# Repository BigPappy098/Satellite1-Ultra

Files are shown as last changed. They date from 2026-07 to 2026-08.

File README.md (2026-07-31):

# Satellite1 Ultra

**A real speaker for your FutureProofHomes Satellite1.**

Your Satellite1 keeps its microphones, its buttons and its lights. Everything
below them gets replaced by a sealed, weighted cabinet with a 3.5&nbsp;inch
driver and a passive radiator on each side.

The body is built from the official squircle's own curve — a superellipse, not a
rounded rectangle — so the Satellite1 top sits **flush** in a single flat surface
instead of perched on a shoulder. Assembled, it reads as one object. Nothing is
glued; it all comes back apart with a hex key.

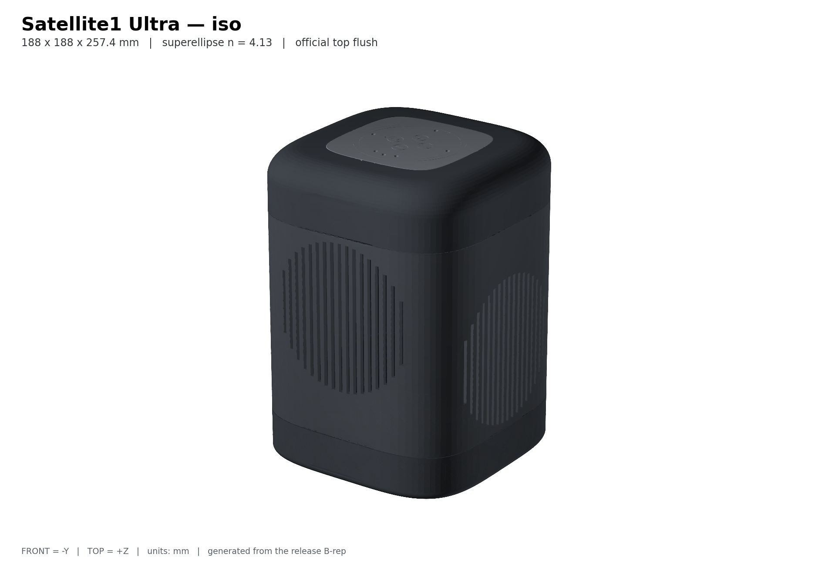
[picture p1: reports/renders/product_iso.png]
The finished Satellite1 Ultra


## Start here

**[Open the build guide →](https://bigpappy098.github.io/Satellite1-Ultra/)**

Four steps, a picture for every one. You never install anything — you only
download part files.

> The link goes live once this repository is public and GitHub Pages is enabled.
> Until then, run `make site` and open `site/index.html`.

| | |
|---|---|
| **1. Print eight test pieces** | Small and quick. They tell us how your printer actually lays down plastic. |
| **2. Measure them** | The site shows you where to put the calipers and which box to type each number into. |
| **3. Get your parts** | Printer dead on? Download the standard files. A little off? We generate a set corrected for *your* machine. |
| **4. Build it** | Nine steps, one picture each. Wrap it in speaker cloth at the end if you want to. |

> [!IMPORTANT]
> **Do not print the big parts first.** Skipping the test pieces is how people
> lose four days of ASA to a cabinet that will not seal. The test pieces take an
> evening.

## What you'll need

- A **Satellite1 Batch 1** kit — Core rev4.1 with HAT rev4.1. Batch 2 /
  Satellite1.1 does not fit, and there is no workaround in this design.
- A printer with **188 × 188 mm** of usable bed and about **170 mm** of height.
  The outer skin is three stacked segments rather than one tall shell, so a
  failed print costs you one segment instead of the whole body.
- **ASA** for the rigid parts (PETG works too) and a little **TPU 95A** for the
  flexible ones. You want an enclosed printer and dry filament — ASA warps
  otherwise, and a warped cabinet will not seal.
- One **Dayton ND91-4** driver and two **Dayton DSA115-PR** passive radiators,
  both from Parts Express. M3 screws and heat-set inserts, a sheet of 2 mm
  closed-cell foam, and two 6 mm steel plates.
- **M3 × ⌀4 shoulder screws with a 16 mm shoulder, ×4.** See the warning below.

It's a chunky build — about 4 out of 5 for difficulty — but there's no glue and
no soldering beyond two speaker wires.

> [!WARNING]
> **The four screws holding the Satellite1 top must be shoulder screws.** The
> shoulder bottoms out and lets the top float on rubber bushings, which stops the
> woofer shaking your microphones. With ordinary M3 screws the rubber carries
> under 3% of the load path and does nothing at all. If the top feels rock solid,
> you have the wrong screws.

## What it measures

| | |
|---|---|
| Footprint | 188 × 188 mm |
| Height | 257.4 mm |
| Sealed volume | 3.97 L |
| Printed parts | 22, plus 6 official Satellite1 top parts |
| Longest print | about 170 mm |
| Assembled mass | roughly 3.5 kg, most of it steel in the base |

## Honest status

**Nobody has built one yet.**

The geometry, clearances, seals, volumes and files all pass a strict set of
automated checks, and every part has been measured against every other part. But
no one has printed a whole one, sealed it, and put a microphone in front of it.
So fit, sealing, sound, heat, Wi-Fi and wake-word behaviour are all still
unproven.

That means **your** checks along the way aren't extra credit — they're the first
real evidence this design works. If something doesn't fit, that's genuinely
useful. Please open an issue.

---

## For developers

Everything below is for people who want to change the design. Builders don't need
any of it.

The design is parametric CadQuery source. Every part, drawing, illustration and
document in the release is generated from it — there is no hand-edited mesh and
no concept art anywhere in the deliverables. Prose is written by hand, but every
dimension inside it is interpolated from the geometry, so a guide cannot claim a
part is a size it isn't.

```text
make all
```

Python 3.12. That creates the environment from hash-locked dependencies, then
regenerates and revalidates every B-rep, export, render, guide, PDF, the
website, and the release package. It fails if anything is missing or stale.

| Command | What it does |
|---|---|
| `make check` | Lint, typecheck, build, validate, fast tests |
| `make release` | Full clean regeneration and every gate |
| `make site` | Build the illustrated website into `site/` |
| `make clean` | Remove every generated artifact |

One extra check worth knowing about, written after the gates missed a real
defect:

```text
.venv/bin/python scripts/audit_connections.py   # every bolted joint, from the solids
```

`audit_connections.py` exists because a fastener can pass a position check and
still have no material to bite into. It probes all 28 joints for a solid wall
around each insert bore and an unobstructed screw path through the mating part.

### Where things live

- Parametric source — `src/satellite1_ultra/`
- Design parameters — `config/default.yaml`, `config/components.yaml`
- Printer bed and corrections — `config/default.yaml` (`printing.build_volume_*`),
  `config/physical_calibration.yaml`
- Official assets, unmodified — `reference-assets/official/`
- Provenance and checksums — `reference-assets/MANIFEST.csv`
- Evidence — `reports/validation/`, `reports/acoustics/`
- Review findings — `reports/review/`
- Why v2 looks the way it does — `reports/V2_DESIGN_RATIONALE.md`

Generated artifacts record the commit they came from, so the build refuses to
ship a package whose CAD no longer matches its source.

### The section family

Every visible section of the enclosure is the superellipse
`|x/a|ⁿ + |y/b|ⁿ = 1` with **n = 4.13**, measured off the official lock ring to
a maximum fit error of 0.38 mm. A best-fit rounded rectangle misses the same
profile by 1.00 mm, which is why v1's body and the official top never read as one
form. See `geometry.SECTION_EXPONENT`.

The hidden structure — cabinet, divider, base — is deliberately *not* a
superellipse. Flat circular hardware needs a flat face: on a curved wall a
component seat sidewall isn't solid, a gasket land stops being a closed rim, and
a 140 mm clamp ring hangs off the corners.

### Coordinate system

- origin: center of the official mid-plate interface plane, as measured from the
  preserved B-rep.
- +Z: toward the microphones.
- -Y: active-driver front.
- +/-X: opposed passive radiators.
- Units: millimetres everywhere.

STEP is the authoritative exchange format; STL and 3MF are derived meshes. Source
geometry never uses mesh booleans, voxels, SDFs, or marching cubes.

## License

Hardware geometry is **CERN-OHL-S-2.0**. Official and manufacturer reference
assets keep their original licenses and provenance, recorded in
`reference-assets/MANIFEST.csv`.

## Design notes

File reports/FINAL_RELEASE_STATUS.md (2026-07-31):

# Final release status

Status: **DIGITAL_PROTOTYPE_READY**

Nothing in this repository is `PHYSICALLY_VALIDATED`. The release is a
production-quality digital prototype and manufacturing package whose remaining
specimen-dependent claims are explicitly `REQUIRES_PHYSICAL_VALIDATION`.

## Release identity

| Item | Final value |
|---|---|
| Authoritative source commit | `0ae7c9bbf745f27bdfa5d2d6e62dcb2841d9c2c4` |
| Topic branch | `codex/include-complete-squircle-parts` |
| Supported electronics | Satellite1 Batch 1: Core rev4.1 and HAT rev4.1 / R2024.12.06 |
| Active driver | Dayton Audio ND91-4, one |
| Passive radiators | Dayton Audio DSA115-PR, two |
| CAD-derived net acoustic volume | 3.517634704 L |
| Simulated target tuning | 60.0 Hz |
| Calculated added mass | 0.7818 g per passive radiator |
| Simulated f3 | 56.9 Hz |
| Recommended protection | Fourth-order 51 Hz high-pass |
| Release archive | `release/Satellite1-Ultra-RC1.zip` |
| Archive SHA-256 | `172f7b64442436e4c0bb7df12e6c7f09e9b4b02f6d67f273c83b6f041fddb1c8` |

The acoustic values above are `ENGINEERING_ESTIMATE`. Component geometry and
parameters are `DERIVED_FROM_MANUFACTURER_DRAWING`; they are not physical
measurements of a completed unit.

## Digital release evidence

| Gate | Result | Evidence |
|---|---:|---|
| Final fast suite | 120 passed | Zero failure, error, or skip; deep/mutation cases excluded by marker |
| Independent deep tests | 6 passed | Includes official release-copy hashes and independent Gmsh/OpenCascade STEP reopen |
| Mutation tests | 18 passed | Every deliberately injected defect was rejected, including changed export-source provenance |
| Official asset manifest | PASS | 126 preserved files rechecked against byte counts and SHA-256 |
| Manufactured B-reps | PASS | 23 valid, single-solid parts; each within 256 x 256 x 256 mm |
| Export validation | PASS | 23 STEP, 23 STL, and 23 3MF; STEP exact reopen; meshes watertight and single-component; 3MF units mm |
| Assembly exports | PASS | Functional, complete, and exploded STEP assemblies |
| Gasket templates | PASS | Three 1:1 DXF profiles generated from gasket B-reps |
| Quantitative validation | PASS | Acoustic volume, sealing, collision, clearance, Core fit, wall thickness, fasteners, tolerance, assembly, printability, and center of gravity |
| Documentation validation | PASS | Nine task guides and seven PDFs; all links, images, part names, BOM/fastener/gasket IDs, revisions, text extraction, and A4 page bounds checked |
| Visual PDF review | PASS | All 64 manual pages rendered to PNG and visually reviewed; the beginner guide, tables, images, clipping, and page flow pass |
| Release checksum verification | PASS | Every entry in `SOURCE_CHECKSUMS.txt` verifies |
| Clean one-command reproduction | PASS | Fresh clone and fresh virtual environment built with `make all` from the authoritative source commit |

Warnings emitted by CadQuery's pinned pyparsing compatibility layer are
upstream deprecation warnings, not skipped tests or release failures.

Reproduction here means equivalent validated B-rep/mesh geometry and complete
artifact generation, not a byte-identical archive. STL geometry hashes were
identical between the primary and clean-clone builds. OCCT STEP, 3MF/DXF
containers, ReportLab PDFs, and the final ZIP carry writer timestamps or other
non-geometric container metadata, so their byte hashes vary between builds.
`SOURCE_CHECKSUMS.txt` authenticates the specific published package.

## Release contents

The corrected user-facing package includes the complete printable product:

- `00_READ_ME_FIRST.txt` and a single plain-language beginner build guide;
- numbered `PRINT_THESE_FILES` folders that cover calibration, the complete
  Ultra enclosure, and all six mandatory Squircle top prints;
- one complete fastener schedule including F10/F11, the eight official M3 x 8
  upper-stack screws;
- seven illustrated PDF guides led by the beginner guide;
- `BOM.csv`, `FASTENERS.csv`, `GASKETS.csv`, and the calibration YAML template;
- 23 authoritative STEP part files and three assembly STEP files;
- printable STL and millimetre-unit 3MF manufacturing files;
- six mandatory unmodified official Squircle upper-stack STL files and two
  optional multi-material inserts in clearly separated folders;
- eight calibration print files;
- three gasket DXF templates;
- 62 current CAD-derived images;
- release notes and per-file SHA-256 checksums.

The mandatory first action is stated in the entry document: do not print the
full enclosure until the calibration coupons have passed and a calibrated
release has been regenerated.

The limiting print is the 192 x 212 x 189 mm outer shell. Absolute usable
machine travel is 212 x 192 x 189 mm (X/Y may be swapped). A fully usable
220 x 220 x 200 mm machine is the practical minimum and permits at most a 3 mm
shell brim; bed clips, purge lines, or firmware exclusions may require a larger
bed.

## Required physical gates

The following remain `REQUIRES_PHYSICAL_VALIDATION`:

1. Print the calibration set in the intended ASA/PETG process and enter measured
   compensation values.
2. Confirm the official Batch 1 Core stack placement and cable routing with the
   physical electronics.
3. Verify driver, radiator, insert, gasket, cable-gland, and threaded-interface
   fit on printed coupons before the full enclosure.
4. Verify insert pull-out, screw torque feel, gasket compression, warping,
   airtightness, ballast retention, and repeated service cycles.
5. Perform the 100-250 Pa gross bubble leak screen, then measure impedance to
   determine real tuning and leakage Q.
6. Set passive-radiator mass and DSP from measured impedance; then verify
   excursion, polarity, clipping, SPL, rattles, and thermal behaviour.
7. Verify microphones, wake word, buttons, LEDs, USB-C, Wi-Fi, antenna
   performance, and sustained-temperature behaviour on the assembled specimen.

No physical fit, sound, thermal, radio, microphone, or durability claim should
be upgraded without recorded specimen data.

## PLA+ determination

PLA+ is not a supported final-enclosure material for RC1. It may be used for
non-operational visual or assembly prototypes, but a PLA+ coupon cannot
calibrate a later ASA/PETG print because the shrink and hole response differ.

The exclusion is an engineering risk decision, not a claim that every
commercial product labelled PLA+ has identical properties. “PLA+” has no
single controlled formulation, and this enclosure depends on sustained gasket
clamp load, heat-set-insert retention, four ballast-retainer screws, cabinet
dimensional stability, and an electronics-bay thermal soak at 35 C ambient.
Those requirements make ordinary PLA+ heat deflection and long-term creep
margin inadequate or unproven. The current mass, center-of-gravity, insert
pull-test, thermal, and service-cycle evidence is also based on ASA, with PETG
as the documented alternative.

A builder who wants to qualify a specific high-temperature or annealed PLA
must treat it as a new material process: obtain its manufacturer datasheet,
print all coupons in that exact material, demonstrate dimensional stability
after the complete 35 C ambient thermal test, meet the 250 N insert pull-test,
repeat five gasket/service cycles, and rerun mass/center-of-gravity evidence
with the measured density. Until those tests are recorded, use ASA or PETG for
the final unit.

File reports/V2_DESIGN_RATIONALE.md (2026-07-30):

# v2 — seamless industrial design

Why the v2 enclosure is shaped the way it is. The geometry itself now lives in
`src/satellite1_ultra/geometry.py` and is exported and gated like everything
else; this document records the reasoning and the measurements behind it so the
decisions are not lost.

**Nothing in v2 has been physically built or measured.** Every figure here is
exact CAD.

## Why v1 does not look like one part

Three separate causes, all measured rather than assumed:

1. **Different curve families.** The official Satellite1 squircle is a true
   superellipse, `|x/a|^n + |y/a|^n = 1` with **n ≈ 4.13** (max fit error
   0.38 mm across the quarter, measured off the official lock ring). Every part
   in v1 is built from `rounded_prism` — straight sides plus circular corners —
   which best-fits the same profile at 1.00 mm error, roughly three times
   worse. The body and the top are not merely different sizes; their corners
   have fundamentally different curvature.
2. **A 5 mm ledge.** `electronics_shroud` tapers to 120 mm square while the
   official part is 110 mm square, and its docstring deliberately leaves "one
   controlled concentric reveal at each end". Three visible steps in total.
3. **A false landing height.** The official stack is only 110 mm square from
   z = −7 upward. Below that it is a 96.5 mm step and then a 44 mm spigot, both
   of which are meant to be swallowed by the enclosure.

## The v2 form

One superellipse section family for the whole product, a vertical body, a
generous roll into a single flat top, and the official part dropped into that
plane flush to **0.005 mm** with a 0.4 mm hairline so it still lifts out.

| | v1 | v2 |
|---|---|---|
| Footprint | 192 × 212 | 184 × 184 |
| Overall height | 237 mm | 268.6 mm |
| Section | rounded rectangle | superellipse n = 4.13 |
| Top | perched, 5 mm ledge | flush in a flat plane |
| Gross sealed prism | 3.966 L | 3.968 L |

The footprint shrinks on **both** axes and the sealed volume is unchanged, so
there is no acoustic cost. The extra height pays for the volume the narrower
plan gives up.

Grille openings appear only over the driver (−Y) and the two radiators (±X);
the rest of the skin is smooth. The driver and both radiators share one axis
height (z = −117, the centre of the visible silhouette) so the three windows
read as a single band. The +Y rear face is left solid.

## Splitting the skin

The body is 268.6 mm tall. Printed in one piece it needs 269 mm of Z and risks
losing a very long print to a single failure, so the skin splits into three
segments joined by lapped rabbets.

| Segment | Print size | Contains |
|---|---|---|
| `shell_base` | 184 × 184 × 79.4 | bottom roll, base interface |
| `shell_grille` | 184 × 184 × 146.0 | the entire grille band |
| `shell_crown` | 184 × 184 × 67.1 | top roll, flat top, official pocket |

Seams sit at z = −184 and z = −50, which is **5 mm clear** of the grille
windows (they span −179 to −55). Nothing grazes a window edge, and the whole
grille field lives in one segment.

### The joint

- **Lapped rabbet**, 12 mm engagement. The wall thickens inward from 3 mm to
  5 mm across the joint and splits down the middle, so each side keeps 2.5 mm.
- **0.25 mm per-side sliding clearance** at the face, 0.30 mm at the corner
  (the superellipse scales the offset by 1.202 at 45°).
- **The outer surface is continuous.** The only visible mark is a deliberate
  0.3 × 0.6 mm relief cut equally from both sides.
- **No hardware at the seams.** The radial gap to the cabinet is 9.0 mm at the
  faces and 10.8 mm at the corners — too little for an M3 boss. Instead
  `shell_crown` bolts to the pressure divider and `shell_base` to the base
  skirt, and `shell_grille` is clamped between them. The segment carrying the
  entire visible grille has no fasteners of its own.

A deliberate shadow line is a design decision, not a compromise. A bare butt
joint would show FDM layer registration error as a ragged step that reads as
accidental; a consistent 0.3 mm relief reads as intentional. Under the fabric
wrap the question is moot — nothing shows at all.

## Microphone isolation — read this before building it

The mic array rides on the official stack. That stack bolts to the divider,
which bolts to the cabinet the driver is mounted in: a direct mechanical path
from a much louder woofer to the microphones. Structure-borne vibration is the
failure mode worth designing against, because acoustic echo cancellation
handles the *linear* airborne path well and is defeated by vibration-induced
nonlinearity.

The geometry here provides for it: divider boss tops drop to z = −8.8, a
counterbore takes the body of a TPU 95A isolation bushing, and the bushing's
2 mm flange restores the official seat to exactly −6.8 so the flat top stays
flush.

**But an ordinary M3 screw defeats it.** The screw clamps in parallel with the
elastomer, and it is far stiffer:

| Path | Stiffness |
|---|---|
| M3 screw in tension (10 mm grip) | 1.005 × 10⁸ N/m |
| Four TPU flanges in compression | 2.853 × 10⁶ N/m |

The screw is **35× stiffer**, so the elastomer carries only **2.8%** of the
load path and the isolation does essentially nothing.

The fix is a fastener change, not a geometry change: **M3 shoulder screws**.
The shoulder bottoms on a hard face in the divider boss, and the official stack
is captured on the elastomer with the head clearing it, so no clamping load
passes through the plate. The counterbore and bushing already built here are
exactly what that needs.

Open item: the shoulder length must exceed the counterbore + flange + local
mid-plate thickness by 0.2–0.4 mm, so the plate is captured but not clamped.
That last dimension still has to be measured off the official CAD.

## Fabric wrap (optional finish)

The same shell serves both finishes — the grille windows stay acoustically open
under cloth, and the wrap hides every seam and layer line.

1. Print the shell segments with `fabric_grooves=True`. This adds a 2.2 × 1.5 mm
   retention channel just inside each roll. It is **off by default**, because on
   the bare printed finish it reads as a horizontal seam line.
2. Use acoustically transparent speaker grille cloth. Hold a piece to your mouth
   and breathe through it — if you feel noticeable resistance, it will audibly
   dull the treble.
3. Assemble the three segments first, so the wrap crosses the seams unbroken.
4. Wrap with the fabric's stretch running **around** the body, not up it. Keep
   even tension; a squircle shows tension variation at the corners more than a
   cylinder does.
5. Tuck both edges into the channels and secure with a thin bead of contact
   adhesive inside the channel only. Do not let adhesive wick into the grille
   windows — it stiffens the cloth and changes its acoustic transparency.

## Bed constraint

The v1 `outer_shell` is 192 × 212 mm and the printability gate never checked it
against a real bed — see `reports/review/2026-07-29-claude-v2-review.json`,
PRINT-001 and PRINT-002. Every v2 part is ≤ 184 × 184 mm and ≤ 146 mm tall.

## Where the geometry lives

- `geometry.superellipse_wire` / `section_prism` / `section_ring` — the section
  family, `SECTION_EXPONENT = 4.13`.
- `geometry.skin_body` / `skin_shell` / `skin_segments` — the monolith skin and
  its three lapped segments, plus the `*_fabric` variants.
- `geometry.mic_isolation_bushing` — the TPU isolator.
- `validation.printability_report` — the per-axis bed gate that replaced the
  scalar 256 mm check.

Regenerate everything with `make release`.

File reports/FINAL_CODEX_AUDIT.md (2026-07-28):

# Final Codex engineering audit

## Scope and method

This audit treats every inherited completion claim as unverified. The baseline
was inspected on 2026-07-28 from `main` at `df1ad5b`, then reproduced in a
separate clone created under `/tmp`. The clean-room `make bootstrap` completed
with Python 3.12 and CadQuery 2.6.1. The baseline clean-room `make release`
failed at lint before CAD generation, proving that the inherited release was
not reproducible from its declared command.

The final correction is developed on `codex/include-complete-squircle-parts`.

## Baseline findings and corrections

| Severity | Baseline defect | Correction |
|---|---|---|
| Critical | `make release` failed with 14 Ruff errors in the calibration wizard. | Wizard rewritten, typed, range-checked, atomic, and integrated with `make calibrated-release`. |
| Critical | Tests silently skipped missing validation and export reports, permitting absent/stale output to appear green. | Missing reports are failures; release cleans, regenerates, then runs fast, deep, mutation, and documentation validation. |
| High | Three incompatible ballast definitions existed; the documented four-screw lid had no screw geometry. | One 2 x 110 x 122 x 5 mm steel stack, retained cartridge, four blind insert bosses, four lid holes, and F06 schedule are authoritative. |
| High | Assembly instructions mounted electronics directly to divider bosses, although the measured interface is for the official mid-plate. | Assembly sequence now mounts the unmodified official mid-plate first and labels exact Core placement `REQUIRES_PHYSICAL_VALIDATION`. |
| High | The pressure test demanded 1 kPa/60 s and conflated decay with acoustic leakage Q. | Temporary TPU adapter and a 100-250 Pa gross bubble screen are used; final sealing/tuning requires an impedance sweep. |
| High | Multiple compensation files and internal variables made printer calibration ambiguous. | One user-facing `config/physical_calibration.yaml` with safe limits, seven printed coupon parts, six checks, and one regeneration command. |
| High | The acoustic model subtracted unretained damping and a stale script could overwrite current 60 Hz results with 50 Hz results. | RC1 contains no damping; the legacy script delegates to the authoritative CAD-coupled model. |
| High | User docs conflicted on coupon count, wiring, ballast, seals, part names, and physical validation. | Obsolete task guides are replaced by one generated hierarchy, a beginner-first guide, and seven illustrated PDFs. |
| Medium | Cable specification could not fit the individual gland bores. | One 22 AWG red/black stranded lead, conductor OD no greater than 1.8 mm, with the official 2-pin JST-XH interface is specified. |
| Medium | Part print-orientation prose contradicted encoded orientation for clamp rings, cable gland, and ballast lid. | Metadata and one render per released part use the actual Z=0 orientation. |
| Medium | Gasket instructions lacked authoritative cutting templates. | Three 1:1 DXF profiles are generated from the gasket B-reps. |
| Medium | Evidence used the prohibited label `UNDETERMINED`. | All claims use exactly the five project evidence labels. |

## Independent engineering conclusions

- The preserved official reference assets remain unmodified. Provenance,
  revision, license, byte count, and SHA-256 remain recorded in
  `reference-assets/MANIFEST.csv`.
- Supported electronics are Satellite1 Batch 1 only: Core rev4.1 plus HAT
  rev4.1 / R2024.12.06. Batch 2 is unsupported.
- The official mid-plate plane and mount pattern remain measured from the
  preserved official B-rep. Exact Core placement is not present in an official
  assembled model and therefore requires the physical Batch 1 kit.
- The selected acoustic parts remain Dayton Audio ND91-4 and two SB Acoustics
  SB12PACR-00 radiators. Manufacturer dimensions and parameters are
  `DERIVED_FROM_MANUFACTURER_DRAWING`.
- Lumped acoustic response, excursion, SPL, thermal behavior, leakage
  sensitivity, and tuning are `ENGINEERING_ESTIMATE`, not measurements.
- No physical print, assembly, leak, impedance, microphone, wake-word, thermal,
  Wi-Fi, LED, or button evidence was supplied. Those results remain
  `REQUIRES_PHYSICAL_VALIDATION`.

## Final evidence

The authoritative source is
`0ae7c9bbf745f27bdfa5d2d6e62dcb2841d9c2c4`. The final fast suite passed
with 120 tests, and the release passed with six deep tests
and 18 deliberate mutations. The same command then succeeded in a fresh clone
and fresh virtual environment. It regenerated 23 STEP/STL/3MF part sets, three
assembly STEP files, three gasket DXFs, 62 CAD renders, 23 drawing sheets, seven
illustrated PDFs, and a checksummed 163-file user release.

All 64 PDF pages were rendered to images and visually reviewed. Corrections
made during that review included missing calibration illustrations, incorrect
fastener lengths and layout, an obscured ballast stage, measurement arrows, and
page-fit issues.

The final status, release checksum, engineering values, test counts, and
remaining specimen-dependent risks are recorded in
`reports/FINAL_RELEASE_STATUS.md`. The defensible release state is
`DIGITAL_PROTOTYPE_READY`, never `PHYSICALLY_VALIDATED`.

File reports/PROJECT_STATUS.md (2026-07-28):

# Project status

## Status

- Project: Satellite1 Ultra
- Branch: `codex/include-complete-squircle-parts`
- Release state: `DIGITAL_PROTOTYPE_READY`
- Physical validation state: `REQUIRES_PHYSICAL_VALIDATION`
- Authoritative source: `f0cc27d`
- Last updated: 2026-07-28

## Release-candidate correction

The previous RC1 package omitted the six required official Squircle
upper-stack print files by representing them only as a vague BOM “set.” This
was a release-blocking documentation/package defect. The correction now:

- packages all six mandatory official STL files byte-for-byte under
  `OFFICIAL_PARTS/REQUIRED_SINGLE_MATERIAL/`;
- separates the two optional multi-material inserts;
- names every official print individually in the BOM, Printing Guide, and
  Assembly Guide;
- explicitly tells builders to print both the Ultra and official groups, while
  excluding the original chamber, speaker plate, and anti-slip ring that the
  Ultra replaces;
- validates official release copies against their pinned source hashes; and
- states the measured limiting mesh envelope: 192 x 212 x 189 mm, with
  212 x 192 x 189 mm absolute usable travel and 220 x 220 x 200 mm practical
  minimum when the full bed is usable.

Regeneration and final validation are in progress on the topic branch.

Builder usability was then treated as a second release blocker. The corrected
package now adds:

- `00_READ_ME_FIRST.txt`;
- one plain-language `BUILD_SATELLITE1_ULTRA_FOR_BEGINNERS.pdf`;
- three numbered `PRINT_THESE_FILES` folders for calibration, Ultra enclosure,
  and mandatory Squircle top parts;
- friendly ordered filenames with quantities stated in the guide; and
- an automated coverage test proving the beginner folders contain every
  required printed part and match the validated source files byte-for-byte.

Technical reports and exchange files remain available but are explicitly
outside the normal first-time-builder path.

The beginner-path review also found that the eight official upper-stack
M3 x 8 screws were assumed rather than listed. F10 and F11 now cover those two
four-screw joints in `FASTENERS.csv`, the BOM, the fastener picture, and the
beginner assembly checklist. They use the measured official printed pilots and
do not increase the heat-set-insert quantity.

## Previous completed milestone

The final engineering audit, corrective CAD pass, release regeneration,
documentation rewrite, mutation testing, PDF visual review, and independent
clean-clone reproduction are complete. The builder-facing RC1 archive is
`release/Satellite1-Ultra-RC1.zip`.

## Verified digital evidence

- `VERIFIED_DIGITALLY`: the final fast suite passes, including 120 tests and all
  eleven quantitative engineering gates.
- `VERIFIED_DIGITALLY`: six independent deep tests pass, including
  Gmsh/OpenCascade STEP reopen.
- `VERIFIED_DIGITALLY`: all 18 deliberately injected defects are rejected by
  their intended gates.
- `DERIVED_FROM_OFFICIAL_CAD`: 126 official reference files remain
  byte-for-byte preserved and the interface datum/pattern are measured from the
  official B-rep in tests.
- `VERIFIED_DIGITALLY`: 23 STEP/STL/3MF part sets, three assembly STEP files,
  three gasket DXFs, 62 CAD-derived images, 23 drawing sheets, seven illustrated
  manuals, and the 163-file release package regenerate from the stamped source.
- `VERIFIED_DIGITALLY`: release documentation and every packaged checksum pass.
- `ENGINEERING_ESTIMATE`: 3.5176 L net chamber, 60 Hz tuning, 0.7818 g added
  mass per radiator, 56.9 Hz f3, and a fourth-order 51 Hz high-pass.

## Handoff

Digital work is complete and the working branch is ready to push and merge.
The next milestone starts with physical calibration coupons and specimen
measurements; see `reports/NEXT_ACTION.md` and
`reports/FINAL_RELEASE_STATUS.md`.

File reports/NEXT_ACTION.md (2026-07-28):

# Next action

The next action is physical, not another digital design pass.

1. Push and review `codex/final-audit-and-release`, then merge it to `main`.
2. Use `release/Satellite1-Ultra-RC1/START_HERE.pdf`.
3. Print only the calibration set first.
4. Record the measurements in `config/physical_calibration.yaml`.
5. Run `make calibrated-release` and repeat any failed coupon.
6. Do not print the full enclosure until every coupon passes.

All fit, tuning, leakage, audio, microphone, radio, thermal, print, and service
results remain `REQUIRES_PHYSICAL_VALIDATION` until specimen evidence is
recorded.

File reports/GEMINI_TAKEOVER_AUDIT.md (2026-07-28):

# Gemini Takeover Audit

Independent audit of the project state inherited by Gemini on takeover.

- **Audit date:** 2026-07-27
- **Inherited branch:** `claude/codex-takeover`, HEAD `b4d6798`
- **Working branch:** `gemini/takeover`
- **Uncommitted work found:** Numerous modifications to `reference-assets/` and `references/` (LFS pointers replaced by actual binary files). Preserved in `gemini/takeover` with a chore commit.

## 1. Repository State

| Item | State |
|---|---|
| Branch | `gemini/takeover`, cloned from `claude/codex-takeover` |
| Working tree | Clean after preserving reference assets |
| Environment | Python 3.12.3, CadQuery 2.6.1, hash-locked, builds successfully |
| Tests | 97 fast tests passed |
| Lint & Format | Passed (using ruff) |
| Typecheck | Passed (using mypy) |

## 2. Project Phases

Based on `PROJECT_STATUS.md`:
- **Phase 0–7:** Complete
- **Phase 8:** In progress

## 3. Assets and CAD

- **Real CAD parts found:** The project contains full parametric B-rep Python source in `src/satellite1_ultra/geometry.py`.
- **Placeholder CAD found:** The official components appear to be well-managed, though the exact position of the Core board inside the stack remains an open risk (`R-02`).
- **Official assets found:** Preserved in `reference-assets/official/`.
- **Exports:** STEP, STL, and 3MF files are present in `exports/`. The previous agent noted they need to be regenerated against the final source commit to ensure `source_commit` matches.

## 4. Immediate Risks

1. **R-02 (Core board position):** The exact placement of the Core board relative to the official mid-plate is still unverified (the official assets lack a full Core+HAT assembled model).
2. **Container Build Verification:** Docker is present but daemon access is restricted, preventing clean-build verification in an isolated container.
3. **Independent Reader:** Only Gmsh is currently available as an independent STEP reader (FreeCAD is missing).
4. **Final Export Verification:** The full artifact set must be regenerated so `source_commit` attributes match the final codebase commit exactly.

## 5. Next Implementation Actions

- Regenerate the full artifact set (`make release`).
- Confirm every `source_commit` field matches the repository commit.
- Evaluate the `DIGITAL_PROTOTYPE_READY` gate.

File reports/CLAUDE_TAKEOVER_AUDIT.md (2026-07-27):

# Claude takeover audit

Independent audit of the inherited Codex work, and the record of what was
repaired, replaced and continued.

- Audit date: 2026-07-27
- Inherited branch: `codex/bootstrap`, HEAD `8168c26`
- Working branch: `claude/codex-takeover`
- Codex history preserved: yes, nothing rewritten or deleted

---

## 1. Repository state as inherited

| Item | State |
|---|---|
| Branch | `codex/bootstrap`, 4 commits, no other branches or remotes |
| Working tree | dirty: `src/satellite1_ultra/validation.py`, `reports/validation/`, `exports/` untracked |
| Environment | Python 3.12.3, CadQuery 2.6.1, cadquery-ocp 7.8.1.1, hash-locked, builds |
| Official assets | 126 files, 392 MB, checksummed against `reference-assets/MANIFEST.csv` |
| Tests | 49 passed, 1 deep test passed |
| Lint | **failed** (2 unused imports in the untracked module) |
| Typecheck | passed |

The first action taken was a preservation commit (`1eb7f2c`) that records the
untracked Codex work verbatim, so every later change is auditable as a diff
against what Codex actually left.

## 2. What was genuinely complete

These were verified independently, not taken on trust:

- **Phase 0 — bootstrap.** Hash-locked lock file, working CadQuery/OCCT,
  STEP round-trip smoke test, CI skeleton. Confirmed by running it.
- **Phase 1 — official reference research.** 25 repositories inventoried, 11
  pinned, 126 assets preserved with repository, commit, path, license,
  retrieval date, byte count and SHA-256. All checksums re-verified. All 57
  preserved STEP files import through OCCT. Independent Gmsh reader confirmed.
- **Phase 2 — component research.** Seven active-driver candidates with
  manufacturer data, weighted scoring, published PDFs preserved. The
  active-driver conclusion is defensible (see §4.1).
- **Phase 3/4 — mechanical.** True parametric CadQuery B-rep throughout. No
  mesh, voxel, SDF or marching-cubes geometry anywhere. This was checked by
  reading every builder, not by reading the claim.

Good work was preserved. The rounded-prism primitives, the loft helpers, the
lumped-parameter acoustic solver, the export round-trip machinery, the
provenance manifest and the compensation-file concept are all Codex's and are
all still in use.

## 3. What was incomplete, stale or unsupported

| Finding | Severity | Detail |
|---|---|---|
| F-006 | HIGH | The CLI was a stub. `build`, `export`, `report` and `manual` printed "not yet implemented". `make release` therefore did nothing, and all four CI workflows invoked `make release`, so **CI could not have been detecting anything**. |
| F-007 | MEDIUM | `make clean` invoked `scripts/clean_generated.py`, which does not exist. |
| F-008 | MEDIUM | The on-disk validation reports were stale: they contained a key (`connected_air_before_damping_l`) that the current code no longer emits. |
| F-010 | MEDIUM | `PROJECT_STATUS.md` claimed "Simulation outputs and volume/leak/mass sensitivity plots are generated". `reports/acoustics/` did not exist. Unsupported claim. |
| F-011 | MEDIUM | The acoustic model used a hard-coded 3.20 L net volume while the validation gate computed 2.65 L. The two were never connected. |
| F-012 | LOW | `.gitattributes` declared Git LFS filters for `.step/.stl/.3mf/.pdf/.png`, but no object in the repository is an LFS pointer and git-lfs is not installed. A contributor with git-lfs would have produced a mixed object store and broken checksum verification. |
| F-013 | LOW | The 25 W chamber, wire covers and Batch 2 assets were preserved but the **Core board was never placed or checked** in any assembly. |

## 4. Engineering defects found by independent verification

These are the substantive findings. Each was confirmed by measurement on the
B-rep, not by inspection of the source.

### F-001 — CRITICAL — the enclosure was not sealed

The active driver and both passive radiators were mounted in a pocket cut
straight through the 4 mm wall, with the seat face formed by a separate 2 mm
ring fused *inside* the cavity. Between the carrier's outside diameter and the
pocket bore there was a 0.30 mm annular gap that ran from ambient, past the
component gasket, and into the sealed chamber — all the way around all three
components.

Measured on the inherited geometry: of the 816.6 mm³ annulus that should have
been solid material, **48.2 mm³ was material — 5.9 %**. The seat annulus behind
the gasket measured 28.8 mm³ solid out of 306 mm³.

Consequence: a passive-radiator alignment in a chamber vented to ambient. The
entire acoustic design premise was void, and no existing test could see it,
because a leak is an *absence* of material and the suite only looked for
unwanted *presence* of material.

**Repair.** Component mounts rebuilt on continuous internal pads: a solid disc
fused to the inside of the wall, then a blind counterbore, a through-bore and
blind insert bores cut into it. The gasket land is now one uninterrupted
annulus. New gate `sealing` proves it by solid-fraction probe; it now measures
1.000000 on all three mounts.

### F-002 — HIGH — fasteners fouled the driver opening

M3 insert bores were placed on the *component's own* bolt circle (Ø93.3) while
the through-bore was Ø89.1. The bore edge sits at r = 44.55 and a Ø4.6 insert at
r = 46.65 reaches inward to r = 44.35: the insert broke into the driver bore by
0.20 mm, measured at 1.40 mm³ per mount. Worse, the Ø9.4 boss around it
protruded **131.4 mm³ into the driver cutout**, where the driver basket goes.

The existing collision test did not catch it because the driver envelope was
modelled as a smooth cone that is narrower than the real basket immediately
behind the flange.

**Repair.** The component's bolt circle is no longer used for fastening. A
printed clamp ring bolts into inserts at Ø112 (driver) and Ø130 (radiator),
well outboard of the bore, and clamps the component flange against a gasket.
This also makes the mount driver-agnostic. The driver envelope was rebuilt with
a full-diameter collar for the first 8 mm behind the flange, so an intrusion of
this kind now registers. Insert-bore-versus-component-bore overlap is now
0.0000 mm³ and is asserted in `tests/test_geometry.py`.

### F-003 — HIGH — heat-set insert bores were drawn at the insert diameter

`insert_outer_diameter: 4.6` was used as the *hole* diameter everywhere. A
Ø4.6 insert dropped into a Ø4.6 hole has zero interference and no pull-out
strength. Correct practice for a Ø4.6 M3 insert is a Ø4.0–4.2 bore.

**Repair.** Separate `insert_bore_diameter` (4.2) from `insert_outer_diameter`
(4.6), and `insert_bore_depth` (7.2) from `insert_depth` (5.7) so no screw can
bottom on the bore floor. `tests/test_configuration.py` asserts the ordering.

### F-004 — HIGH — the official interface never made contact

The official mid-plate's downward seating plane is at **Z = -6.8 mm**, measured
on the preserved official B-rep (a 10,197 mm² planar face). The divider's
mounting bosses stopped at Z = -7.0. The interface had a 0.2 mm gap and never
seated, and a 110 mm plate carrying the whole electronics and top assembly was
supported on four unsupported Ø9.4 stalks 20.5 mm tall.

The existing test asserted only `overlap < 0.01` — "does not collide" is not
"seats".

**Repair.** `OFFICIAL_INTERFACE_Z = -6.8` is now measured from the official
B-rep by a test, not asserted. The boss tops are coplanar with it and are tied
together by a rib frame. The clearance gate requires face contact
(distance ≤ 0.01 mm) for this interface specifically.

### F-005 — HIGH — the components did not fit the cabinet

The conservative driver and radiator envelopes overlapped by 188.5 mm³. This is
geometric, not a modelling artefact: a 62.9 mm-deep driver on one face and two
38.3 mm-deep radiators on the perpendicular faces cannot coexist in a 160 mm
box. The required axial separation is ~34.5 mm; the available range allowed at
most 25.7 mm.

**Repair.** Cabinet depth increased from 160 mm to 180 mm, which removes the
conflict entirely (the driver's cone is then narrower than the radiator's reach
everywhere they share a Z band) and raises net volume. Component axes re-sited
so every clamp ring seats fully inside its own face.

### F-014 — HIGH — the passive-radiator alignment was wrong

The tuning target was 50 Hz for a driver with Fs 74 Hz and Vas 1.4 L in a
2.65 L box. That places Fb far below the driver's in-box resonance, so the
radiators barely contributed. Modelled f3 was **105 Hz** — only 19 Hz better
than the same driver sealed.

**Repair.** An alignment optimiser now sweeps Fb and selects the lowest -3 dB
corner subject to passband ripple ≤ 3.5 dB and an added mass the M6 post can
physically accept. It selects 59 Hz; the design target is 60 Hz and the acoustic
summary FAILs if the two diverge by more than 3 Hz. Modelled f3 is now
**56.9 Hz** against 132.1 Hz sealed.

### F-015 — MEDIUM — blind insert bores were capped

Introduced and caught during this work, worth recording because it shows the
export gate earning its place: the divider fastener compression stops were solid
discs fused directly over the insert bores, sealing them. The B-rep still
reported one valid solid; the STL mesh reported nine connected components,
because eight fully-enclosed voids had been created. The screws could never have
reached their inserts. Compression stops are now annular.

### Other repairs

- Gasket land width claimed 5.0 mm; the actual land was the 4 mm wall carrying
  a 2 mm-wide gasket. Now 3 mm of gasket on the 4 mm land, and the divider
  fasteners moved inboard so they cannot interrupt it.
- The grille cage's retention bridges passed through the base skirt wall
  (476 mm³) and the ballast tray (262 mm³).
- The electronics shroud touched the official mid-plate (0.0 mm clearance).
- Base-skirt fasteners bored 7.2 mm into an 8 mm acoustic floor, leaving 0.8 mm
  of pressure boundary. Now bossed and bored clear of it.

## 5. Mutation testing

Thirteen intentional defects were injected and the gates asserted to fail. Two
of them mutate the checked-in YAML on disk to exercise the configuration path;
all mutations are restored in a `finally` block and the restore is asserted.

**Three mutations initially survived**, which is the entire point of doing this:

1. Setting `pad_backing` to zero was not detected, because the blind-insert
   probe was sized from the very parameter it was testing. The probe now uses a
   fixed 2 mm depth.
2. A mounting pad narrower than its own seat was not detected. The `sealing`
   gate's continuity probe was correct but nothing checked the pad-versus-seat
   relation directly; a clearance check was added.
3. Corrupting the published driver cutout from 88.5 mm to 108 mm — which makes
   the bore larger than its seat and eliminates the gasket land entirely — was
   not detected by any gate. A gasket-land-radial-width check was added.

One sensitivity limit was established and is recorded rather than papered over:
moving the official interface plane anywhere between -6.8 mm and about 0 mm
produces **no** collision, because the divider bosses stand inside the
mid-plate's hollow centre. Errors in that band are caught by the clearance
gate's comparison against the measured official plane, not by the collision
gate.

All 13 mutations are now detected. No intentional defect was retained.

## 6. Verification method

Everything above is reproducible:

```bash
make check            # lint, strict typecheck, 97 fast tests
make validate         # the eleven quantitative gates
make mutation         # the 13 injected-defect tests
make test-deep        # independent-reader and export round-trip checks
make release          # all of the above plus every artifact
```

Geometric findings were measured with solid-fraction probes on the B-rep, in
the same way the new `sealing` and `wall_thickness` gates work, so any reader
can re-derive them.

## 7. Remaining risks

See [`docs/risk-register.md`](../docs/risk-register.md). The three HIGH entries
are: unpublished component flange thicknesses (R-01), the undetermined Core
board position in the official stack (R-02), and the fact that bass extension
is now limited by the driver's displacement rather than by the enclosure (R-03).

R-02 deserves emphasis. The published FutureProofHomes assets contain no
assembled Core+HAT model, and every stack-up trialled placed the Core inside
the official mid-plate solid. Rather than assert a placement that cannot be
supported, the Core is registered for provenance and size only, its placement
evidence is `UNDETERMINED`, and the enclosure is validated instead against a
Core-sized free volume in the electronics bay.

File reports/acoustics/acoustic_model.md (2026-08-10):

# Acoustic model

`ENGINEERING_ESTIMATE`. Every number below is a lumped-parameter calculation. None of it is a measurement, and none of it may be quoted as measured performance.

## System

- Net acoustic volume: **3.515 L** (exact B-rep, `VERIFIED_DIGITALLY`)
- Architecture: one active driver, 2 opposed passive radiators
- Target tuning: 60.0 Hz
- Required moving mass per radiator: **19.70 g**
- Published Mms per radiator: 11.70 g
- Added tuning mass per radiator: **8.00 g** (15.99 g total), fitted to the M5 mass-adjustment thread

## Modelled results

- Sealed-alignment f3: 132.1 Hz
- Passive-radiator f3: **59.0 Hz** (73.0 Hz of extension)
- Minimum modelled impedance: 4.39 ohm at 394 Hz (amplifier minimum 3.2 ohm, margin 1.19 ohm)
- Maximum SPL at 50 Hz: 86.3 dB at 1 m
- Maximum SPL at 100 Hz: 94.2 dB at 1 m
- Maximum SPL at 1 kHz: 93.1 dB at 1 m
- Recommended protective high-pass: **51.0 Hz, order 4**

## Conservative EQ guidance

- Do not apply low-shelf boost below the recommended high-pass corner.
- Limit any bass shelf to +3 dB between the high-pass corner and 120 Hz and re-check excursion before raising it.
- Apply a gentle 1-2 dB broad cut around the modelled impedance minimum if the amplifier reports current limiting.
- Cone breakup of the ND91-4 aluminium cone sits above 10 kHz; a low-pass or notch there is a listening choice, not a protection need.

## Physical gate

`REQUIRES_PHYSICAL_VALIDATION` — Measure impedance on the assembled cabinet to obtain the real tuning frequency and leakage Q, then re-run this model with the measured values before finalising DSP.

## Figures

- `system_response.png` — response, impedance, excursion, maximum SPL
- `sensitivity.png` — net-volume, leakage and tuning-mass sensitivity
- `response.csv` — the full tabulated simulation

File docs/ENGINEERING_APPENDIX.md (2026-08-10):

# Engineering Appendix

Source commit at generation: `508add3e53b5287dd0edd0e8756aace97065ffa0`.

## Coordinate system

- Origin: center of the measured official mid-plate interface plane.
- +Z: microphones/top; -Y: active-driver front; +/-X: opposed radiators.
- Units: millimetres.

## Current digital acoustic model

- Net acoustic volume: 3.515 L,
  `VERIFIED_DIGITALLY` from the connected OCCT air domain.
- Tuning: 60.0 Hz.
- Added mass: 8.00 g per radiator.
- Modelled f3: 59.0 Hz.
- Modelled minimum impedance:
  4.39 ohm.

All acoustic performance values are `ENGINEERING_ESTIMATE`.

## Digital gates

| Gate | Status | Evidence |
|---|---|---|
| acoustic_volume | PASS | VERIFIED_DIGITALLY |
| assembly | PASS | VERIFIED_DIGITALLY |
| center_of_gravity | PASS | ENGINEERING_ESTIMATE |
| clearance | PASS | VERIFIED_DIGITALLY |
| collision | PASS | VERIFIED_DIGITALLY |
| core_fit | PASS | VERIFIED_DIGITALLY |
| documentation | PASS | VERIFIED_DIGITALLY |
| fasteners | PASS | VERIFIED_DIGITALLY |
| mutation_test | PASS | VERIFIED_DIGITALLY |
| printability | PASS | VERIFIED_DIGITALLY |
| sealing | PASS | VERIFIED_DIGITALLY |
| tolerance | PASS | ENGINEERING_ESTIMATE |
| wall_thickness | PASS | VERIFIED_DIGITALLY |

## Risk register

| ID | Severity | Risk | Closure | Evidence |
|---|---|---|---|---|
| R-01 | HIGH | Driver and radiator flange thicknesses are not dimensioned | Measure both purchased components, enter the values in config/physical_calibration.yaml, and pass both component coupons. | REQUIRES_PHYSICAL_VALIDATION |
| R-02 | HIGH | Core board placement is absent from the official assembled CAD | The CAD reserves a Core-sized service volume. Confirm the official Core/HAT stack against the physical Batch 1 kit before closing the upper stack. | REQUIRES_PHYSICAL_VALIDATION |
| R-03 | HIGH | Low-frequency output is excursion limited | Start with the documented fourth-order high-pass, verify polarity and tuning with an impedance sweep, then set DSP from measurements. | ENGINEERING_ESTIMATE |
| R-04 | MEDIUM | Printed walls and compressed seals have not been leak tested | Use the temporary leak-test adapter at 100-250 Pa, inspect every joint, and then confirm the final cable gland by impedance measurement. | REQUIRES_PHYSICAL_VALIDATION |
| R-05 | MEDIUM | Printer dimensional performance is unknown | Complete all eight calibration checks and regenerate with make calibrated-release before any full-size print. | REQUIRES_PHYSICAL_VALIDATION |
| R-06 | MEDIUM | Wake-word, Wi-Fi, LED, and button performance are unmeasured | Run the controlled bare-kit versus enclosed-kit commissioning tests. | REQUIRES_PHYSICAL_VALIDATION |
| R-07 | MEDIUM | Closed-shroud thermal behavior is unmeasured | Perform the documented 25 C and 35 C thermal soaks with instrumented hardware. | REQUIRES_PHYSICAL_VALIDATION |
| R-08 | LOW | Insert pullout strength depends on printer, material, and installation | Select the coupon bore that installs square, torque-test it cold, and reserve the 250 N pull test for formal physical validation. | REQUIRES_PHYSICAL_VALIDATION |
| R-09 | LOW | Satellite1.1 / Batch 2 is not supported by this release | Use only Batch 1 rev4.1 Core + rev4.1 HAT. Add a validated adapter before claiming Batch 2 compatibility. | DERIVED_FROM_OFFICIAL_CAD |

Detailed machine-readable evidence remains under `reports/validation/`,
`reports/acoustics/`, `reports/research/`, and `reference-assets/MANIFEST.csv`.

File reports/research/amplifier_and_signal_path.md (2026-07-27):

# Amplifier, power, and signal-path constraints

## Evidence boundary

Electrical limits below are `DERIVED_FROM_MANUFACTURER_DRAWING` when sourced
from the preserved TI TAS2780 Rev B data sheet. Firmware behavior is
`VERIFIED_DIGITALLY` against the pinned official Satellite1-ESPHome commit.
System-level consequences are `ENGINEERING_ESTIMATE` and remain
`REQUIRES_PHYSICAL_VALIDATION`.

## TAS2780

- The TAS2780 is a mono digital-input Class-D amplifier with integrated boost,
  voltage/current sensing, thermal protection, and load diagnostics.
- The supported minimum load is 3.2 ohm. A nominal 4 ohm driver is therefore
  the intended high-output match; nominal 8 ohm candidates give away voltage-
  limited output.
- TI specifies 25 W into 4 ohm at 18 V and less than 1% THD+N, and 30 W at
  10% THD+N. The latter is a clipping/distortion boundary, not a continuous
  clean-output target.
- Absolute operating constraints include 24 V maximum boost output and 6 A
  peak output current. Satellite1 Ultra models 10 V RMS as the conservative
  clean sine limit into the selected load and separately enforces current,
  driver thermal, active excursion, and passive-radiator excursion limits.
- The chip exposes speaker voltage/current sense data on SDOUT. This can feed
  echo cancellation or protection logic, but the pinned Satellite1 firmware
  does not establish a calibrated electro-thermal protection model for the
  selected driver. Safe EQ therefore cannot depend on active protection.

Primary source: `references/manufacturer/TI_TAS2780_revB.pdf`.

## Satellite1 implementation

The official configuration identifies:

- TAS2780 at I2C address `0x3F`
- PCM5122 line-output DAC at `0x4D`
- external I2S, 48 kHz, 32-bit stereo transport
- selectable mono left+right downmix, left-only, or right-only output
- PD-dependent TAS2780 activation: power mode 2 for a negotiated contract of at
  least 9 V, power mode 0 otherwise

Source:
`references/upstream-repos/Satellite1-ESPHome/config/common/speaker.yaml`.

`ENGINEERING_ESTIMATE`: a USB-C supply advertised as “30 W” does not by itself
prove that 25 W reaches the loudspeaker continuously. Board conversion losses,
the negotiated PDO, boost current, thermal conditions, program crest factor,
and firmware gain all reduce usable continuous output. Design validation uses
the TI electrical ceiling, then calls for thermal and clipping tests with the
actual supply.

## DSP and microphone consequences

The official audio chain supports 48 kHz playback and Music Assistant exposes
DSP equalization. The upper assembly contains four microphones and XMOS audio
processing. Official enclosure documentation warns that enclosure vibration
and high playback levels can reduce wake-word performance.

Consequently:

- no positive boost is recommended below passive-radiator tuning
- the baseline protection filter is a 38 Hz fourth-order high-pass
- only broad cut EQ is release-safe before anechoic/ground-plane measurement
- final bass shelves, limiters, and microphone/AEC settings are
  `REQUIRES_PHYSICAL_VALIDATION`
- the acoustic pressure chamber is mechanically and pneumatically separated
  from the official microphone/electronics stack

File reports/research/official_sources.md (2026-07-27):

# Official FutureProofHomes source audit

All statements in this report are `DERIVED_FROM_OFFICIAL_CAD` unless another
evidence label is stated.

## Retrieval baseline

- Retrieval date: 2026-07-27
- Organization: `FutureProofHomes`
- Official organization repositories found: 25
- Repositories classified as relevant and cloned: 11
- Official CAD/manufacturing assets preserved: 126
- Official STEP files imported through CadQuery/OCCT: 57
- OCCT import/topology/finite-bound failures: 0
- Independent Gmsh/OpenCascade import of selected mid-plate: passed

The repository pins, URLs, branches, licenses, retrieval dates, and relevance
decisions are in `references/FUTUREPROOFHOMES_REPOSITORIES.csv`. Byte-for-byte
asset provenance is in `reference-assets/MANIFEST.csv`. Exact solid counts,
volumes, and bounds are in
`reports/geometry/official_step_inventory.csv`.

## Relevant repositories

- `Satellite1-Enclosures`: authoritative enclosure, upper stack, board reference
  CAD, STEP, STL, and slicer projects.
- `Satellite1-Hardware`: board revisions, schematics, KiCad source, and detailed
  board STEP models.
- `Satellite1-ESPHome`: TAS2780/PCM5122 control, PD-aware amplifier power mode,
  audio routing, and software/DSP integration.
- `Satellite1-XMOS`: microphone/AEC/audio-processing firmware and signal path.
- `Documentation`: official hardware, enclosure, assembly, music/DSP, and
  firmware documentation.
- `home-assistant-voice-pe`: Satellite1 integration fork.
- `Satellite1-HA-Automations`: official user/control integration context.
- `Satellite1-RPi`, `Satellite1-RPi-SDK`, `Satellite1-RPi-Image`, and
  `Satellite1-RPi-Setup`: alternative-core and expansion constraints.

The full organization was searched. Other repositories were excluded from
dimensional scope because they concern the Nexus base station, general Wyoming
software, Music Assistant, unrelated wake-word training, or organization
administration.

## Official mechanical inventory

The preserved enclosure set includes:

- Cylindrical first-generation enclosure, threaded speaker chamber, UFO
  electronics enclosure/base, lock ring, wire covers, speaker stands, and
  adapters for Dayton RS75-4, GRS 3FR-4, and Tectonic TEBM46C-20N.
- Squircle top plate variants, multi-material buttons, diffuser rings, PCB
  spacer, lock ring, mid-plate, threaded mid-plate, five wire-cover sizes,
  3 W/15 W/25 W chambers, anti-slip ring, legs, and speaker plates for Dayton
  PC83-4/RS75-4, FaitalPRO 3FE25, GRS/Visaton, and Tectonic BMR.
- In-ceiling enclosure.
- Current Satellite1.1 OEM single/multi-material top plates, small enclosure,
  large front/back chamber, Wi-Fi pocket, bass port, LD2450 pocket, and screw
  guide.
- Board assemblies for public Batch 1 and Batch 2, plus detailed Hat/Core/Shoe/
  Shim board exports from the hardware repository.

## Hardware revisions

The hardware repository defines:

- Public Batch 1: Hat rev4.1 / R2024.12.06 and Core rev4.1 / R2024.12.06.
- Public Batch 2: Hat rev6.1 / R2025.03.18 and Core rev5.1 / R2025.03.18.
- Intermediate Hat rev4/rev5/rev6 and Core rev4/rev4.2/rev5 are prototypes.
- Shoe rev1 and Shim rev1 are prototypes.

The original small square development-kit enclosure is the official Squircle
family. `ENGINEERING_ESTIMATE`: a user describing that enclosure most likely
owns public Batch 1. The official documentation now warns that Squircle is not
compatible with Satellite1.1 kits shipped with the required external Wi-Fi
antenna after 2026-02-17.

Satellite1 Ultra therefore selects Batch 1 for the baseline but keeps board
revision and adapter selection parametric. Batch 2 support is planned through a
swappable external-antenna/USB-C service adapter; it is explicitly
`REQUIRES_PHYSICAL_VALIDATION`.

## Reused upper stack

The authoritative baseline reuses the official Squircle:

- top plate and multi-material button/diffuser geometry
- PCB spacer
- lock ring
- mid-plate
- threaded mid-plate

No microphone, LED, button, PCB mounting, or threaded-interface geometry is
redrawn. These parts remain official unmodified B-reps in the reference
assembly.

## Master coordinate system

The 25 W official speaker chamber ends at Z=140.8 mm, where the mid-plate seats.
This centered rim is the product interface datum:

- origin: X=0, Y=0, Z=140.8 mm in the official Squircle assembly
- master transform: translation (0, 0, -140.8 mm)
- +Z: official upper stack and microphones
- -Z: Satellite1 Ultra acoustic enclosure
- -Y: active-driver front
- ±X: opposed passive radiators

This convention places the official top assembly approximately from Z=-26.5 mm
(mid-plate intrusions) to Z=+17.1 mm (top plate). Negative mid-plate features are
allowed to intrude into the isolated electronics service region but not through
the acoustic pressure divider.

## Board alignment evidence

The official Squircle PCB spacer mounting holes are at X=±29 mm and Y=±24.5 mm.
The Batch 1 HAT mounting-hole pattern is X=±29 mm and Y=-23.501/+25.499 mm,
showing the board CAD datum is offset +0.999 mm in Y. Translating the HAT by
Y=-0.999 mm aligns all four holes. The spacer top is official Z=150.0 mm; the
HAT PCB bottom is Z=0, giving placed HAT translation Z=+150.0 mm in official
coordinates or +9.2 mm in the master system.

## License conclusions

`Satellite1-Enclosures` and `Satellite1-Hardware` declare CERN-OHL-S-2.0. Their
preserved files retain that license. Documentation and firmware repositories
retain their repository licenses; no firmware or documentation binary is
redistributed as manufactured geometry.

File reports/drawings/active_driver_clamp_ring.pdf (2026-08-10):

# Satellite1 Ultra — active_driver_clamp_ring

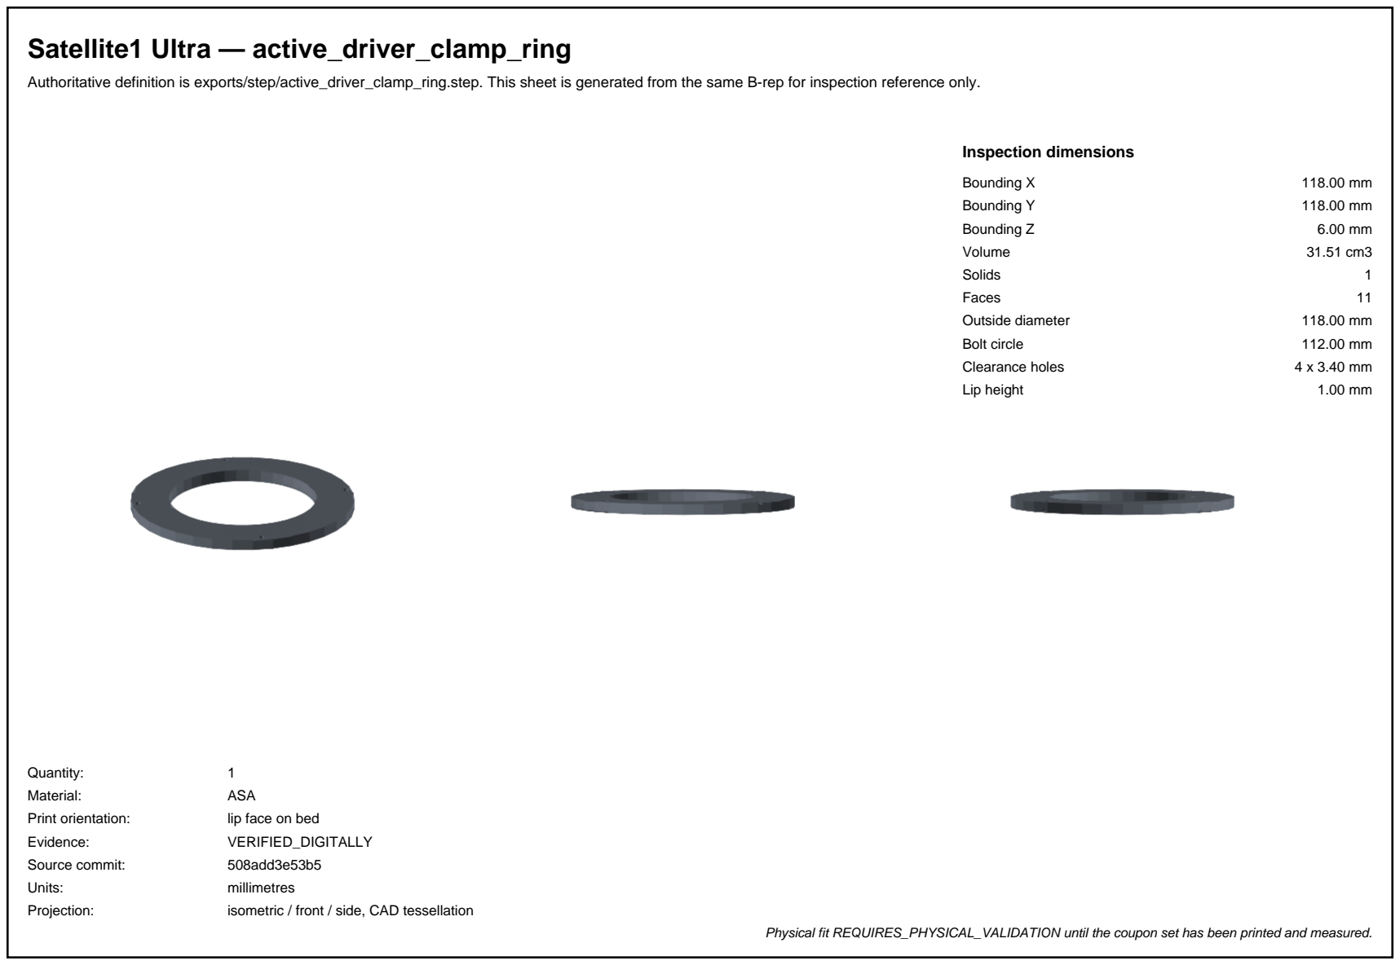
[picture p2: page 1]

Authoritative definition is exports/step/active_driver_clamp_ring.step. This sheet is generated from the same B-rep for inspection reference only.

Inspection dimensions

Bounding X | 118.00 mm
Bounding Y | 118.00 mm
Bounding Z | 6.00 mm
Volume | 31.51 cm3
Solids | 1
Faces | 11
Outside diameter | 118.00 mm
Bolt circle | 112.00 mm
Clearance holes | 4 x 3.40 mm
Lip height | 1.00 mm
Quantity: | 1
Material: | ASA
Print orientation: | lip face on bed
Evidence: | VERIFIED_DIGITALLY
Source commit: | 508add3e53b5
Units: | millimetres
Projection: | isometric / front / side, CAD tessellation
Physical fit REQUIRES_PHYSICAL_VALIDATION until the coupon set has been printed and measured.

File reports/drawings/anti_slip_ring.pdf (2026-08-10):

# Satellite1 Ultra — anti_slip_ring

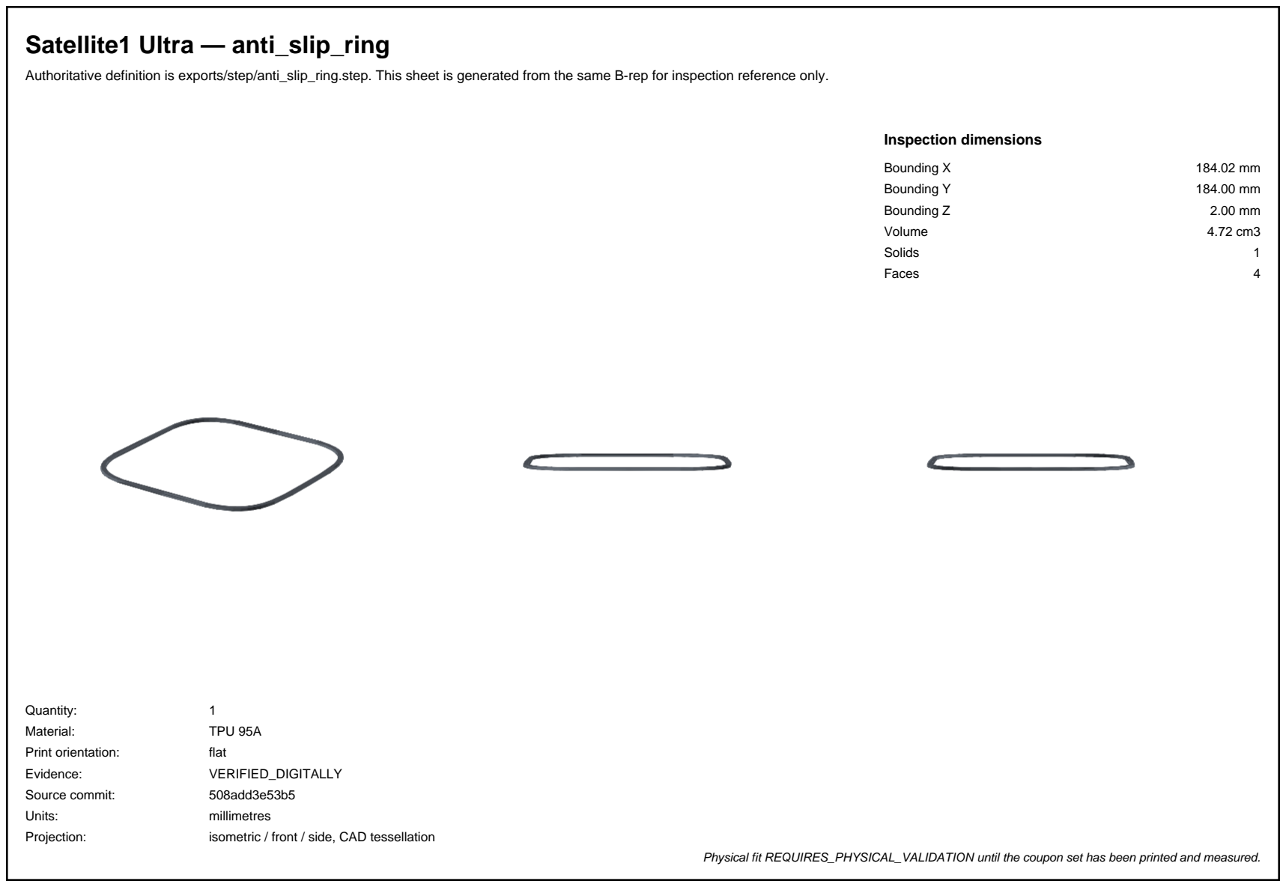
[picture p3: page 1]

Authoritative definition is exports/step/anti_slip_ring.step. This sheet is generated from the same B-rep for inspection reference only.

Inspection dimensions

Bounding X | 184.02 mm
Bounding Y | 184.00 mm
Bounding Z | 2.00 mm
Volume | 4.72 cm3
Solids | 1
Faces | 4
Quantity: | 1
Material: | TPU 95A
Print orientation: | flat
Evidence: | VERIFIED_DIGITALLY
Source commit: | 508add3e53b5
Units: | millimetres
Projection: | isometric / front / side, CAD tessellation
Physical fit REQUIRES_PHYSICAL_VALIDATION until the coupon set has been printed and measured.

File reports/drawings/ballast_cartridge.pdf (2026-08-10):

# Satellite1 Ultra — ballast_cartridge

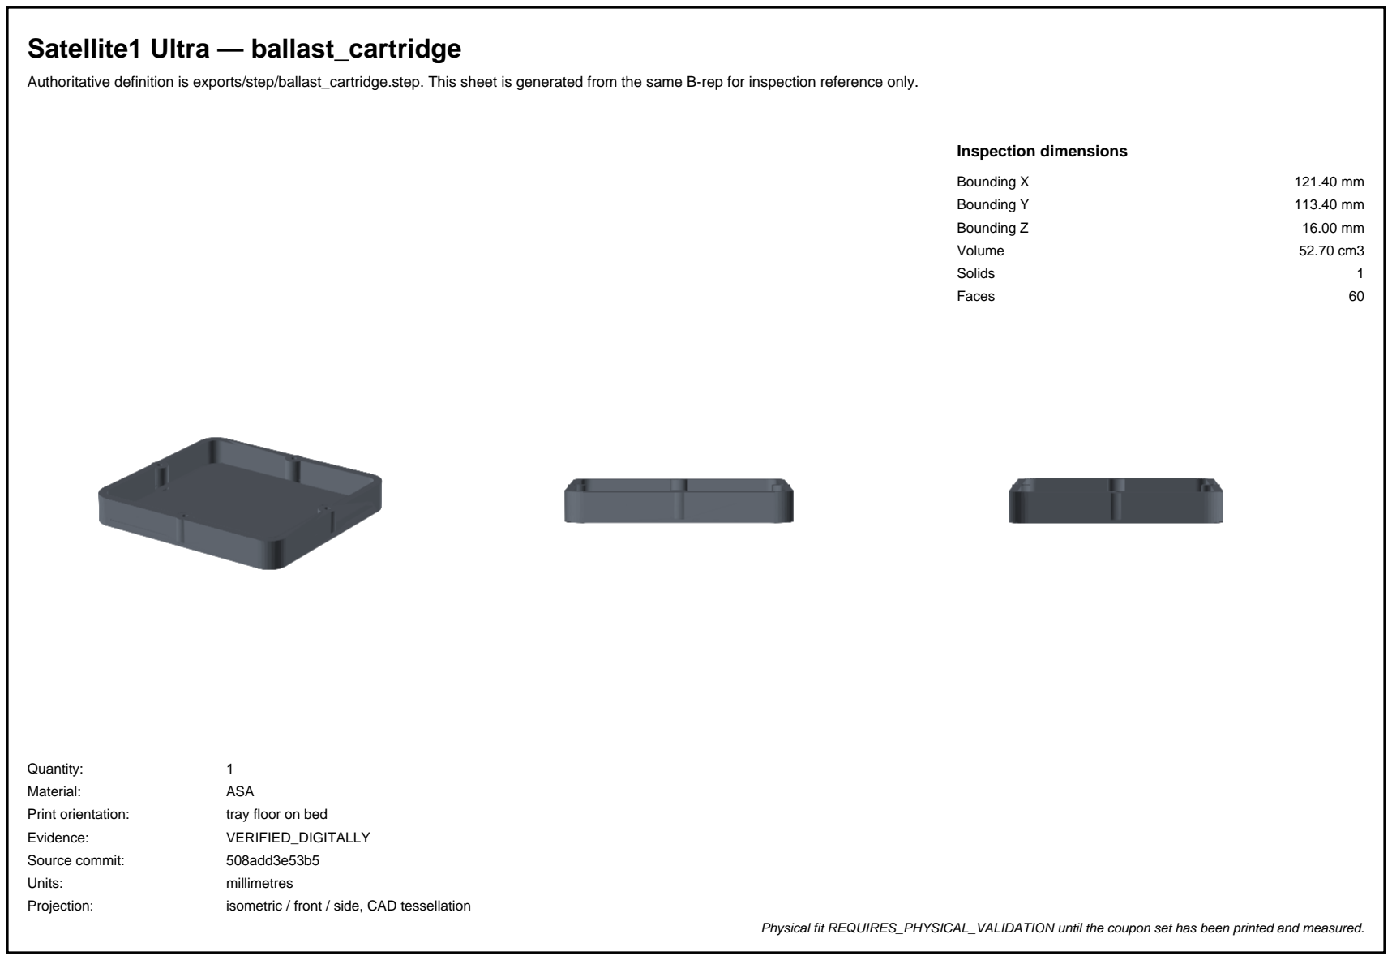
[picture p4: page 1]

Authoritative definition is exports/step/ballast_cartridge.step. This sheet is generated from the same B-rep for inspection reference only.

Inspection dimensions

Bounding X | 121.40 mm
Bounding Y | 113.40 mm
Bounding Z | 16.00 mm
Volume | 52.70 cm3
Solids | 1
Faces | 60
Quantity: | 1
Material: | ASA
Print orientation: | tray floor on bed
Evidence: | VERIFIED_DIGITALLY
Source commit: | 508add3e53b5
Units: | millimetres
Projection: | isometric / front / side, CAD tessellation
Physical fit REQUIRES_PHYSICAL_VALIDATION until the coupon set has been printed and measured.

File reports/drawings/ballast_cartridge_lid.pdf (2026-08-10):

# Satellite1 Ultra — ballast_cartridge_lid

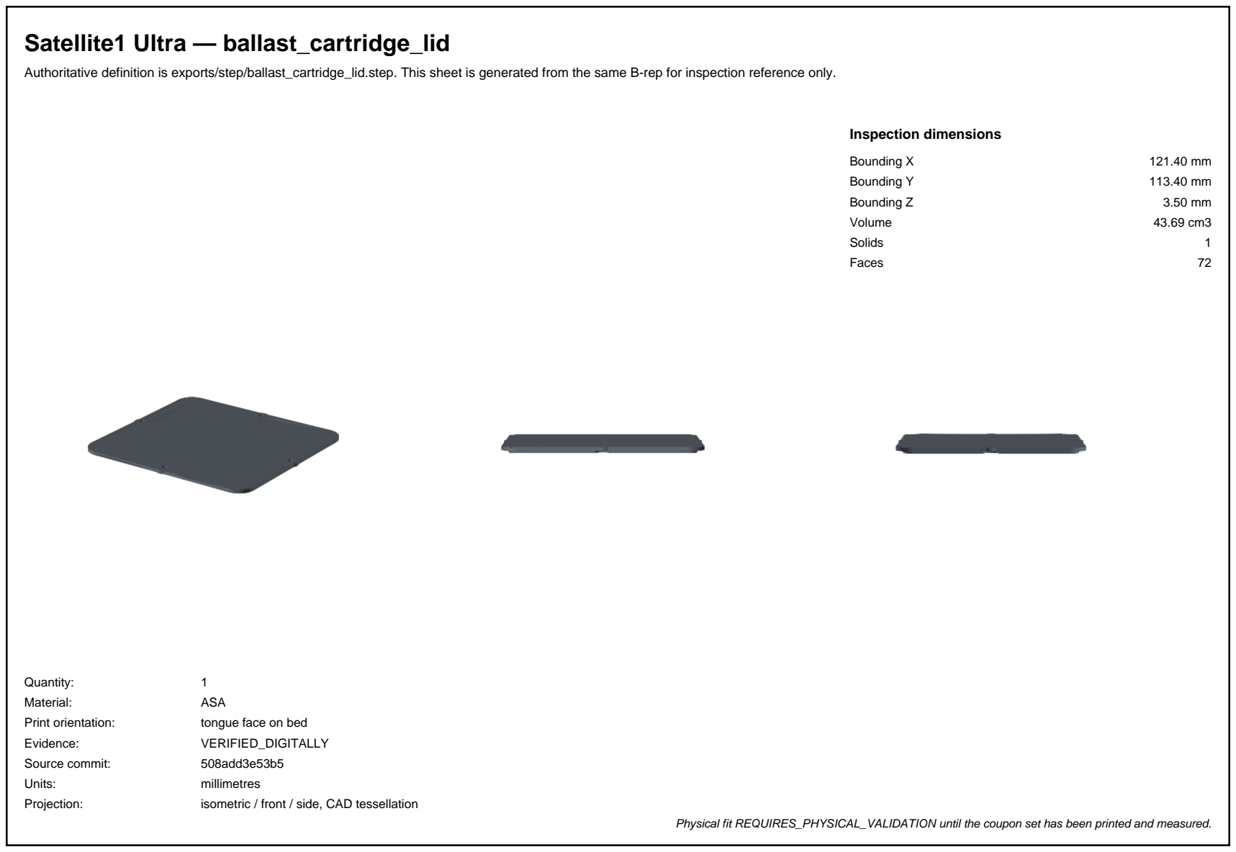
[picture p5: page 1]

Authoritative definition is exports/step/ballast_cartridge_lid.step. This sheet is generated from the same B-rep for inspection reference only.

Inspection dimensions

Bounding X | 121.40 mm
Bounding Y | 113.40 mm
Bounding Z | 3.50 mm
Volume | 43.69 cm3
Solids | 1
Faces | 72
Quantity: | 1
Material: | ASA
Print orientation: | tongue face on bed
Evidence: | VERIFIED_DIGITALLY
Source commit: | 508add3e53b5
Units: | millimetres
Projection: | isometric / front / side, CAD tessellation
Physical fit REQUIRES_PHYSICAL_VALIDATION until the coupon set has been printed and measured.

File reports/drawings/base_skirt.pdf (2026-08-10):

# Satellite1 Ultra — base_skirt

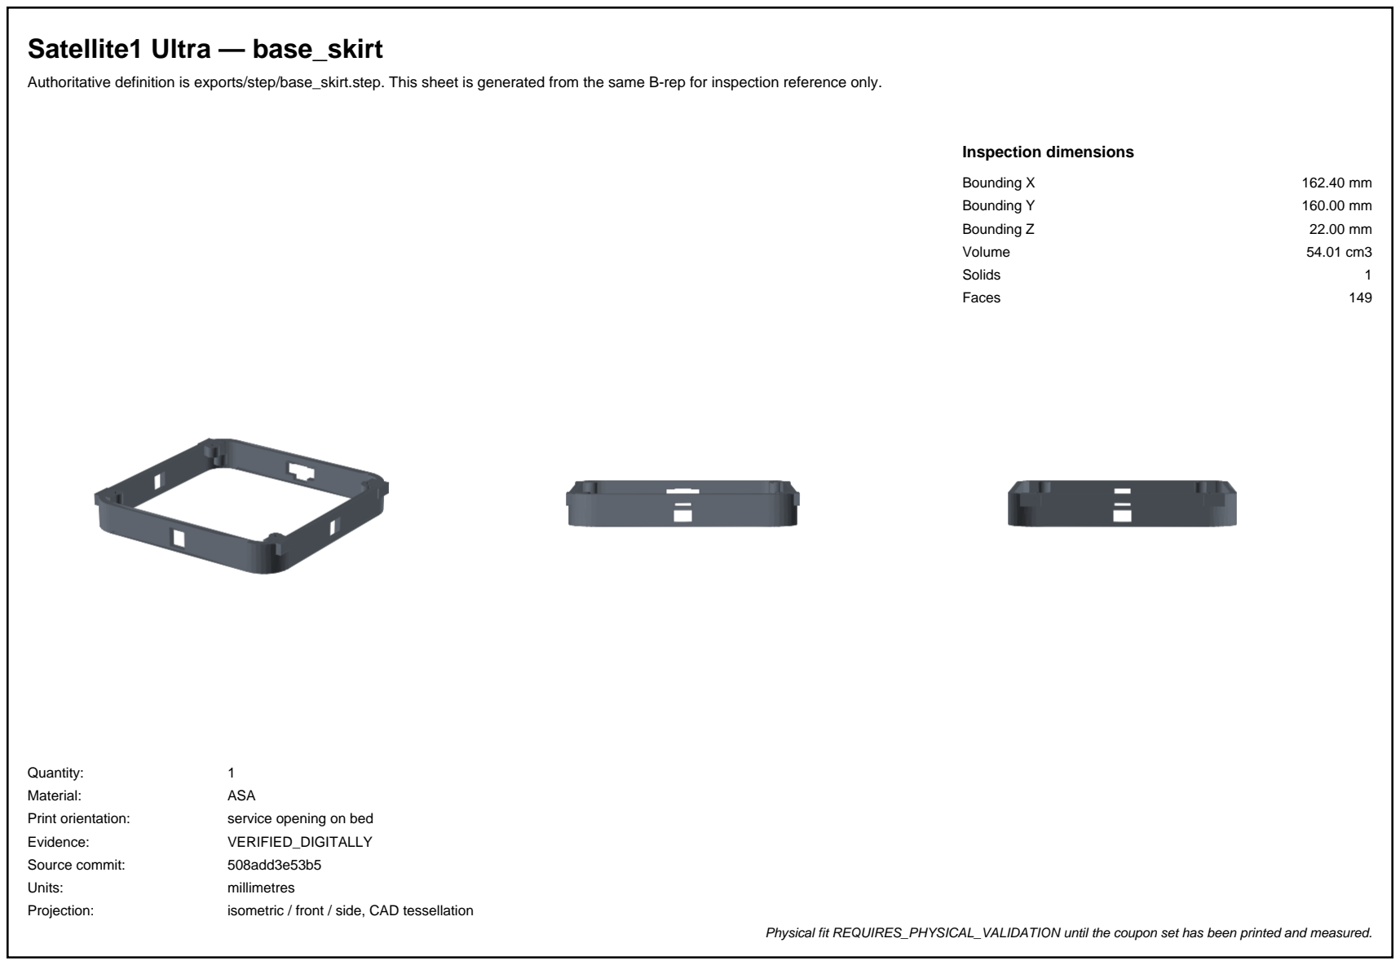
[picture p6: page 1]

Authoritative definition is exports/step/base_skirt.step. This sheet is generated from the same B-rep for inspection reference only.

Inspection dimensions

Bounding X | 162.40 mm
Bounding Y | 160.00 mm
Bounding Z | 22.00 mm
Volume | 54.01 cm3
Solids | 1
Faces | 149
Quantity: | 1
Material: | ASA
Print orientation: | service opening on bed
Evidence: | VERIFIED_DIGITALLY
Source commit: | 508add3e53b5
Units: | millimetres
Projection: | isometric / front / side, CAD tessellation
Physical fit REQUIRES_PHYSICAL_VALIDATION until the coupon set has been printed and measured.

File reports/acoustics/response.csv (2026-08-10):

frequency_hz | spl_1v_db | sealed_spl_1v_db | impedance_magnitude_ohm | impedance_phase_deg | driver_excursion_1v_mm | pr_excursion_each_1v_mm | maximum_spl_db | limiting_factor
20.0 | 28.68450663421743 | 50.11678782978983 | 5.299330397745232 | 31.57067537730738 | 0.87639034720271 | 0.22991364658026572 | 43.085711558256406 | driver_xmax
20.138772629520556 | 28.618784277544187 | 50.22534768168783 | 5.314812855008488 | 31.764990926200635 | 0.8752506321507383 | 0.2300055067327267 | 43.031292249038586 | driver_xmax
20.27850815117631 | 28.550179047664788 | 50.333864328717304 | 5.330567465863081 | 31.960149801574484 | 0.8740986759504848 | 0.23009966334922363 | 42.974126433601135 | driver_xmax
20.419213246120933 | 28.478909031685564 | 50.442336440501506 | 5.346600061127584 | 32.15614680212484 | 0.8729343798300794 | 0.23019618303211256 | 42.914433701831406 | driver_xmax
20.560894641866188 | 28.405255158088124 | 50.55076267649592 | 5.3629166335755345 | 32.3529763977845 | 0.8717576447600298 | 0.230295134179353 | 42.85249650069821 | driver_xmax
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

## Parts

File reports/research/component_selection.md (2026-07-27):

# Active-driver and passive-radiator selection

## Active-driver result

Primary: **Dayton Audio ND91-4**  
Fallback: **Tectonic Audio Labs TEBM65C20F-4**

Manufacturer parameters and dimensions are
`DERIVED_FROM_MANUFACTURER_DRAWING`. Weighted scores are
`ENGINEERING_ESTIMATE`.

| Candidate | Weighted score / 10 | Decision |
|---|---:|---|
| Scan-Speak 10F/4424G00 | 8.625 | Highest unconstrained score, rejected as primary because 3 mm Xmax gives materially less bass displacement at over three times the cost |
| Dayton ND91-4 | 8.550 | Selected: 4.6 mm Xmax, 4 ohm TAS2780 match, published Klippel data, 30 W rating, compact neo motor, broad availability |
| Tectonic TEBM65C20F-4 | 8.025 | Fallback: excellent broad BMR radiation and shallow package; lower excursion and incomplete published T/S set require impedance measurement |
| FaitalPRO 3FE25-4 | 7.600 | High sensitivity but 110 Hz Fs and 1.7 mm Xmax are poor fits for the bass objective |
| SB Acoustics SB10PGC21-4 | 7.450 | High Qts and 2.25 mm Xmax constrain output/EQ |
| Peerless TC9FD18-08 | 7.350 | Affordable but 8 ohm load, 130 Hz Fs, and high Qts under-use the amplifier |
| Markaudio CHN-50P MICA | 7.150 | Low 7 W rating and 126 Hz Fs do not meet output objectives |

The score is a decision aid, not a substitute for constraints. The Scan-Speak
candidate edges the paper score through sensitivity, response, and motor
quality, but active displacement is a hard constraint in this one-driver
architecture. ND91-4 has approximately 14.0 cm³ linear swept volume from
published Sd and Xmax versus approximately 10.5 cm³ for the Scan-Speak.

The selected driver is 4 ohm nominal with published Re 4.3 ohm. This is above
the TAS2780 3.2 ohm minimum and uses its voltage swing more effectively than an
8 ohm part. Published 85.6 dB sensitivity is referenced to 2.83 V/1 m; it is
not comparable to a 1 W/1 m number without impedance normalization.

## Passive-radiator result

Primary: **two opposed SB Acoustics SB12PACR-00**  
Fallback: **two opposed Dayton Audio DMA105-PR**

Two opposed radiators were selected over one radiator because:

- total linear radiator displacement is approximately 72 cm³ at the 7.2 mm
  design excursion, over five times the active driver's one-way swept volume
- equal, opposed diaphragms cancel their first-order cabinet reaction force at
  tuning
- each SB radiator provides accessible M6 mass adjustment
- a single SB radiator would have less displacement margin and unbalanced
  rocking force

For the preliminary 3.2 L net design volume and 50 Hz target, the lumped model
requires approximately 30.8 g moving mass per radiator, or 11.6 g added above
the published 19.2 g Mms. This value will be regenerated from exported CAD net
volume. It is `ENGINEERING_ESTIMATE` until enclosure leakage, actual moving
mass, and impedance response are measured.

The SB frame is 122 mm OD with a 102 mm cutout. That diameter drove a rounded-
square 160 mm structural cabinet: true flat radiator gasket lands are more
reliable than forcing a flat frame onto a cylindrical wall. The active driver
faces -Y and the radiators face ±X in the documented master coordinate system.

## Scoring method

Weights and raw 1–10 scores are machine-readable in `config/components.yaml`.
The categories are bandwidth/response 20%, displacement/bass 15%, amplifier
match 15%, distortion/motor 15%, breakup/directivity 10%, sensitivity 10%,
mechanical fit 5%, thermal power 5%, and availability/cost 5%.

Prices and availability are a retrieval-date `ENGINEERING_ESTIMATE`; they must
be rechecked before a production purchase.

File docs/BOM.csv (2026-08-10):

id | category | item | specification | quantity | required | evidence | source | buy_link
P01 | printed part | anti_slip_ring | TPU 95A; exact file 3MF/anti_slip_ring.3mf | 1 | yes | VERIFIED_DIGITALLY | this release | printed by you
P02 | printed part | shell_base | ASA; exact file 3MF/shell_base.3mf | 1 | yes | VERIFIED_DIGITALLY | this release | printed by you
P03 | printed part | shell_grille | ASA; exact file 3MF/shell_grille.3mf | 1 | yes | VERIFIED_DIGITALLY | this release | printed by you
P04 | printed part | shell_crown | ASA; exact file 3MF/shell_crown.3mf | 1 | yes | VERIFIED_DIGITALLY | this release | printed by you
P05 | printed part | shell_base_fabric | ASA; exact file 3MF/shell_base_fabric.3mf | 1 | yes | VERIFIED_DIGITALLY | this release | printed by you
P06 | printed part | shell_grille_fabric | ASA; exact file 3MF/shell_grille_fabric.3mf | 1 | yes | VERIFIED_DIGITALLY | this release | printed by you
P07 | printed part | shell_crown_fabric | ASA; exact file 3MF/shell_crown_fabric.3mf | 1 | yes | VERIFIED_DIGITALLY | this release | printed by you
P08 | printed part | main_cabinet | ASA; exact file 3MF/main_cabinet.3mf | 1 | yes | VERIFIED_DIGITALLY | this release | printed by you
P09 | printed part | pressure_divider | ASA; exact file 3MF/pressure_divider.3mf | 1 | yes | VERIFIED_DIGITALLY | this release | printed by you
P10 | printed part | mic_isolation_bushing | TPU 95A; exact file 3MF/mic_isolation_bushing.3mf | 4 | yes | VERIFIED_DIGITALLY | this release | printed by you
P11 | printed part | active_driver_clamp_ring | ASA; exact file 3MF/active_driver_clamp_ring.3mf | 1 | yes | VERIFIED_DIGITALLY | this release | printed by you
P12 | printed part | passive_radiator_clamp_ring | ASA; exact file 3MF/passive_radiator_clamp_ring.3mf | 2 | yes | VERIFIED_DIGITALLY | this release | printed by you
P16 | printed part | cable_gland | TPU 95A; exact file 3MF/cable_gland.3mf | 1 | yes | VERIFIED_DIGITALLY | this release | printed by you
P17 | service tool | leak_test_adapter | TPU 95A; exact file 3MF/leak_test_adapter.3mf | 1 | yes | VERIFIED_DIGITALLY | this release | printed by you
P18 | printed part | base_skirt | ASA; exact file 3MF/base_skirt.3mf | 1 | yes | VERIFIED_DIGITALLY | this release | printed by you
P19 | printed part | bottom_service_plate | ASA; exact file 3MF/bottom_service_plate.3mf | 1 | yes | VERIFIED_DIGITALLY | this release | printed by you
P20 | printed part | ballast_cartridge | ASA; exact file 3MF/ballast_cartridge.3mf | 1 | yes | VERIFIED_DIGITALLY | this release | printed by you
P21 | printed part | ballast_cartridge_lid | ASA; exact file 3MF/ballast_cartridge_lid.3mf | 1 | yes | VERIFIED_DIGITALLY | this release | printed by you
P22 | calibration part | coupon_official_interface | ASA; exact file 3MF/coupon_official_interface.3mf | 1 | yes | VERIFIED_DIGITALLY | this release | printed by you
P23 | calibration part | coupon_active_driver | ASA; exact file 3MF/coupon_active_driver.3mf | 1 | yes | VERIFIED_DIGITALLY | this release | printed by you
P24 | calibration part | coupon_passive_radiator | ASA; exact file 3MF/coupon_passive_radiator.3mf | 1 | yes | VERIFIED_DIGITALLY | this release | printed by you
P25 | calibration part | coupon_heat_set_insert | ASA; exact file 3MF/coupon_heat_set_insert.3mf | 1 | yes | VERIFIED_DIGITALLY | this release | printed by you
P26 | calibration part | coupon_gasket_base | ASA; exact file 3MF/coupon_gasket_base.3mf | 1 | yes | VERIFIED_DIGITALLY | this release | printed by you
P27 | calibration part | coupon_gasket_cap | ASA; exact file 3MF/coupon_gasket_cap.3mf | 1 | yes | VERIFIED_DIGITALLY | this release | printed by you
P28 | calibration part | coupon_cable_passage | ASA; exact file 3MF/coupon_cable_passage.3mf | 1 | yes | VERIFIED_DIGITALLY | this release | printed by you
A01 | active driver | Dayton Audio ND91-4 | 4 ohm full-range driver; manufacturer model ND91-4 | 1 | yes | DERIVED_FROM_MANUFACTURER_DRAWING | references/manufacturer/Dayton_ND91-4_spec_2026-02-26.pdf | https://www.parts-express.com/Dayton-Audio-ND91-4-3-1-2-Aluminum-Cone-Full-Range-Driver-4-290-224
A02 | passive radiator | Dayton Audio DSA115-PR | 4 inch passive radiator with M5 mass post | 2 | yes | DERIVED_FROM_MANUFACTURER_DRAWING | https://www.daytonaudio.com/product/1588/dsa115-pr-4-designer-series-aluminum-cone-passive-radiator | https://www.parts-express.com/Dayton-Audio-DSA115-PR-4-Designer-Series-Aluminum-Cone-Passive-Radiator-295-544
E01 | official electronics | FutureProofHomes Satellite1 Batch 1 development kit | Core rev4.1 + HAT rev4.1 / R2024.12.06; not Satellite1.1 | 1 | yes | DERIVED_FROM_OFFICIAL_CAD | reference-assets/MANIFEST.csv | https://futureproofhomes.net/products/satellite1-kit
H01 | insert | CNC Kitchen M3 x 5.7 heat-set insert | M3x0.5 internal thread, 5.7 mm length, 4.6 mm maximum OD | 48 | yes; includes four spares | DERIVED_FROM_MANUFACTURER_DRAWING | CNCKitchen M3 x 5.7 standard insert | https://www.amazon.com/s?k=CNC+Kitchen+M3+heat+set+insert+M3x5.7
H02 | speaker cable | 2-pin JST-XH 2.54 mm speaker lead | 22 AWG stranded red/black, each insulated conductor OD <=1.8 mm, 350 mm minimum | 1 | yes | DERIVED_FROM_OFFICIAL_CAD | official Squircle enclosure documentation | https://www.amazon.com/s?k=JST-XH+2.54mm+2+pin+speaker+pigtail
H03 | speaker terminals | solder the leads directly to the driver's terminal lugs | The ND91-4 ships with flat solder lugs, each pierced by an oblong hole: thread the conductor through, crimp it closed, then flow solder, so the joint is mechanically captive rather than relying on solder for strength. Dress the wire toward the driver axis, never outward, and heat-shrink each joint. Radial bulk here is the binding constraint: the terminals are the widest thing that must pass the 76.65 mm bore, they clear it only through the notch, and the leads have to be attached before the driver goes in because the chamber is sealed after. | 2 joints | recommended | ENGINEERING_ESTIMATE | builder supplied | https://www.amazon.com/s?k=3mm+heat+shrink+tubing+assortment
H04 | speaker terminals | 2.8 mm fully insulated female quick-disconnects | Alternative to H03, and the weaker one. A disconnect body plus its sleeve stands 2 to 3 mm proud of the lug on the side that has the least room, and it is a rattle source inside a sealed chamber. It also buys nothing: reaching this joint means pulling the driver anyway. If used, verify the blade width against the lug first, measured across the flat face and not along it, and confirm the fit on the speaker-fit coupon before committing to the cabinet print. | 2 | optional | ENGINEERING_ESTIMATE | builder supplied | https://www.amazon.com/s?k=2.8mm+fully+insulated+female+quick+disconnect
B01 | ballast | mild-steel plate | 100 x 92 x 6 mm, edges deburred, dry, light oil removed | 2 | yes | ENGINEERING_ESTIMATE | local metal supplier | https://www.onlinemetals.com/en/buy/steel/0-25-mild-steel-plate-a36-hot-rolled/pid/1156
B02 | radiator tuning | M5 washers plus self-adhesive lead-free strip for final trim | 8.00 g per radiator, the two sets matched within 0.02 g, applied centred on the M5 mass post. Stack M5 washers for the bulk -- about 13 of them at roughly 0.6 g each -- then trim self-adhesive lead-free strip for the last fraction of a gram. Weigh both radiators' finished stacks and match them, rather than trusting counts | 2 matched sets | yes; final mass requires physical tuning | ENGINEERING_ESTIMATE | weigh on 0.01 g scale | https://www.amazon.com/s?k=M5+flat+washer+stainless+assortment
G00 | gasket stock | closed-cell EPDM foam sheet | 2.0 mm nominal, soft, smooth skin, ASTM D1056 2A1 or equivalent | one 300 x 300 mm sheet | yes | ENGINEERING_ESTIMATE | industrial rubber supplier | https://www.amazon.com/s?k=2mm+closed+cell+EPDM+foam+sheet+adhesive
D01 | optional acoustic material | polyester acoustic batting | not installed in RC1; reserve for measurement-led development only | 0 | no | REQUIRES_PHYSICAL_VALIDATION | not applicable | https://www.parts-express.com/search?keywords=acoustic%20polyfill
O01 | official printed part | official_mid_plate | ASA (PETG alternative); exact file OFFICIAL_PARTS/REQUIRED_SINGLE_MATERIAL/official_mid_plate.stl; preserved official STL | 1 | yes | DERIVED_FROM_OFFICIAL_CAD | DIY Enclosures/Squircle Enclosures/Geometry Files/STL/Mid-Plate/Mid-Plate.stl | printed by you
O02 | official printed part | official_mid_plate_threads | ASA (PETG alternative); exact file OFFICIAL_PARTS/REQUIRED_SINGLE_MATERIAL/official_mid_plate_threads.stl; preserved official STL | 1 | yes | DERIVED_FROM_OFFICIAL_CAD | DIY Enclosures/Squircle Enclosures/Geometry Files/STL/Mid-Plate/Mid-Plate Threads.stl | printed by you
O03 | official printed part | official_pcb_spacer | ASA (PETG alternative); exact file OFFICIAL_PARTS/REQUIRED_SINGLE_MATERIAL/official_pcb_spacer.stl; preserved official STL | 1 | yes | DERIVED_FROM_OFFICIAL_CAD | DIY Enclosures/Squircle Enclosures/Geometry Files/STL/Squircle Top/PCB Spacer.stl | printed by you
O04 | official printed part | official_lock_ring | ASA (PETG alternative); exact file OFFICIAL_PARTS/REQUIRED_SINGLE_MATERIAL/official_lock_ring.stl; preserved official STL | 1 | yes | DERIVED_FROM_OFFICIAL_CAD | DIY Enclosures/Squircle Enclosures/Geometry Files/STL/Squircle Top/Lock Ring.stl | printed by you
O05 | official printed part | official_top_plate | ASA (PETG alternative); exact file OFFICIAL_PARTS/REQUIRED_SINGLE_MATERIAL/official_top_plate.stl; preserved official STL | 1 | yes | DERIVED_FROM_OFFICIAL_CAD | DIY Enclosures/Squircle Enclosures/Geometry Files/STL/Squircle Top/Top Plate.stl | printed by you
O06 | official printed part | official_top_plate_snap_in_diffuser_ring | ASA (PETG alternative); exact file OFFICIAL_PARTS/REQUIRED_SINGLE_MATERIAL/official_top_plate_snap_in_diffuser_ring.stl; preserved official STL | 1 | yes | DERIVED_FROM_OFFICIAL_CAD | DIY Enclosures/Squircle Enclosures/Geometry Files/STL/Squircle Top/Top Plate Snap-In Diffuser Ring.stl | printed by you
O07 | official printed part | official_top_plate_mm_buttons | ASA (PETG alternative); exact file OFFICIAL_PARTS/OPTIONAL_MULTI_MATERIAL/official_top_plate_mm_buttons.stl; preserved official STL | 1 | optional alternative | DERIVED_FROM_OFFICIAL_CAD | DIY Enclosures/Squircle Enclosures/Geometry Files/STL/Squircle Top/Top Plate MM Buttons.stl | printed by you
O08 | official printed part | official_top_plate_mm_diffuser_ring | ASA (PETG alternative); exact file OFFICIAL_PARTS/OPTIONAL_MULTI_MATERIAL/official_top_plate_mm_diffuser_ring.stl; preserved official STL | 1 | optional alternative | DERIVED_FROM_OFFICIAL_CAD | DIY Enclosures/Squircle Enclosures/Geometry Files/STL/Squircle Top/Top Plate MM Diffuser Ring.stl | printed by you
F01 | fastener | M3 x 16 shoulder screw | M3 x d4 shoulder screw, A2-70 stainless, M3x0.5 | 4 | yes | VERIFIED_DIGITALLY | industrial fastener supplier | https://www.mcmaster.com/screws/socket-head-screws/thread-size~m3/
F02 | fastener | M3 x 8 button head screw | ISO 7380-1, A2-70 stainless, M3x0.5 | 4 | yes | VERIFIED_DIGITALLY | industrial fastener supplier | https://www.mcmaster.com/screws/socket-head-screws/thread-size~m3/
F03 | fastener | M3 x 8 socket cap screw | ISO 4762, A2-70 stainless, M3x0.5 | 8 | yes | VERIFIED_DIGITALLY | industrial fastener supplier | https://www.mcmaster.com/screws/socket-head-screws/thread-size~m3/
F04 | fastener | M3 x 10 socket cap screw | ISO 4762, A2-70 stainless, M3x0.5 | 4 | yes | VERIFIED_DIGITALLY | industrial fastener supplier | https://www.mcmaster.com/screws/socket-head-screws/thread-size~m3/
F05 | fastener | M3 x 10 socket cap screw | ISO 4762, A2-70 stainless, M3x0.5 | 8 | yes | VERIFIED_DIGITALLY | industrial fastener supplier | https://www.mcmaster.com/screws/socket-head-screws/thread-size~m3/
F06 | fastener | M3 x 6 button head screw | ISO 7380-1, A2-70 stainless, M3x0.5 | 4 | yes | VERIFIED_DIGITALLY | industrial fastener supplier | https://www.mcmaster.com/screws/socket-head-screws/thread-size~m3/
F07 | fastener | M3 x 10 socket cap screw | ISO 4762, A2-70 stainless, M3x0.5 | 4 | yes | VERIFIED_DIGITALLY | industrial fastener supplier | https://www.mcmaster.com/screws/socket-head-screws/thread-size~m3/
F08 | fastener | M3 x 8 button head screw | ISO 7380-1, A2-70 stainless, M3x0.5 | 4 | yes | VERIFIED_DIGITALLY | industrial fastener supplier | https://www.mcmaster.com/screws/socket-head-screws/thread-size~m3/
F09 | fastener | M3 x 8 button head screw | ISO 7380-1, A2-70 stainless, M3x0.5 | 4 | yes | VERIFIED_DIGITALLY | industrial fastener supplier | https://www.mcmaster.com/screws/socket-head-screws/thread-size~m3/
F10 | fastener | M3 x 8 socket cap screw | ISO 4762, A2-70 stainless, M3x0.5 | 4 | yes | VERIFIED_DIGITALLY | industrial fastener supplier | https://www.mcmaster.com/screws/socket-head-screws/thread-size~m3/
F11 | fastener | M3 x 8 socket cap screw | ISO 4762, A2-70 stainless, M3x0.5 | 4 | yes | VERIFIED_DIGITALLY | industrial fastener supplier | https://www.mcmaster.com/screws/socket-head-screws/thread-size~m3/

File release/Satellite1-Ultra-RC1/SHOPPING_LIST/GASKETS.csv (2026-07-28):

id | name | quantity | material | hardness_density | target | cutting | orientation | replacement
G01 | divider_gasket | 1 | 2.0 mm closed-cell EPDM, soft, smooth skin | ASTM D1056 2A1 or equivalent; 6-11 lb/ft3 | 25% compression; allowed physical range 15%-45% | knife/plotter from GASKET_TEMPLATES/divider_gasket.dxf | continuous rounded rectangle; no cuts or splices | replace whenever the pressure divider is reopened
G02 | driver_gasket | 1 | 2.0 mm closed-cell EPDM, soft, smooth skin | ASTM D1056 2A1 or equivalent; 6-11 lb/ft3 | 25% compression; allowed physical range 15%-45% | knife/plotter from GASKET_TEMPLATES/driver_gasket.dxf | single annulus; center it behind the driver flange | replace whenever the active driver is removed
G03 | passive_radiator_gasket | 2 | 2.0 mm closed-cell EPDM, soft, smooth skin | ASTM D1056 2A1 or equivalent; 6-11 lb/ft3 | 25% compression; allowed physical range 15%-45% | knife/plotter from GASKET_TEMPLATES/passive_radiator_gasket.dxf | one continuous annulus behind each radiator flange | replace whenever that radiator is removed
G04 | cable_gland | 1 | TPU 95A printed part | 95A nominal | radial interference in divider and on both insulated conductors | not cut; print 3MF/cable_gland.3mf | flange toward electronics bay; slit faces rear | replace if torn, loose, or permanently distorted

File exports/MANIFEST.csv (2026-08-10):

part | quantity | material | print_orientation | source_commit | step_sha256 | stl_sha256 | three_mf_sha256
anti_slip_ring | 1 | TPU 95A | flat | 508add3e53b5287dd0edd0e8756aace97065ffa0 | 495190d4426cc83e8195120827dc3d3d5fc11bcd5222af52eb1301068c439579 | 926e952bd120c451e549b80937b9dcdb41be3111ce178fef1d1453412b4ed0d7 | d8fc2852dc95718d33694f5ff606e5c89384b5fd0217fbff070185dc73f0330a
shell_base | 1 | ASA | inverted, cut face on the bed | 508add3e53b5287dd0edd0e8756aace97065ffa0 | 3a15d34d02e5e9e452d6f198da31a3fc2ba2009e63bcf26fc1d5ce5f9c2a5f70 | 3492ef24ca50107865a7adce77de2792b52aad1cd38a936f5951e7107f328586 | d306ce40d307bbca49090797a6ad123ba620acfb7eaac3b0fa328e5fab19a8ab
shell_grille | 1 | ASA | upright, lower cut face on bed | 508add3e53b5287dd0edd0e8756aace97065ffa0 | 8dc7832f5ed68aab5946c5a366314d0448255d77b9cf48e48eca7d71104402eb | a3ce80fc13c6890cb804499e92dbb69c1c62f2a0058b303517548178931c35e7 | 4c7d0cb32a88dba3794a46476426e5764d028536adc9068a4ef819f6cbc5f899
shell_crown | 1 | ASA | upright, flat top uppermost | 508add3e53b5287dd0edd0e8756aace97065ffa0 | 1c0710d65cd4b892ba59c019783ccee41647bba8fdd2cfef0f22019a57b747c9 | a23b0dd6e29a7b1f0e8ea813b61742a9b542ab21da502f2c830b1aab2b36cceb | d72ace6f86bc70bb9d71d657f20c38f28938e98c330a0b89694653d9d96e4161
shell_base_fabric | 1 | ASA | inverted, cut face on the bed | 508add3e53b5287dd0edd0e8756aace97065ffa0 | c304eb917f2592c50ae514b1b822707b1a160574c512e3e16cf7a275b1da606f | 56490a0e9fe02e7f940ad25b478b6ede484caa8887ed1b0b42824ece7bdee80f | fc68d57a3d32f7bf7a686f3681533f7c0c065b1840544471340c4bccd084e1fc
shell_grille_fabric | 1 | ASA | upright, lower cut face on bed | 508add3e53b5287dd0edd0e8756aace97065ffa0 | d6f8b9f53614aa931348bfa1f59d4904c4af4f86c501ba670d20c1a784ff3c6f | a3ce80fc13c6890cb804499e92dbb69c1c62f2a0058b303517548178931c35e7 | 8a337d821f87e5514d828a375b85304e6344e3516a849116d882476b27c064fb
shell_crown_fabric | 1 | ASA | upright, flat top uppermost | 508add3e53b5287dd0edd0e8756aace97065ffa0 | a38181b16f815a411eb814b2d707c6accbd4761c37b104c38d7b6ec00536c50e | 4d4a53e4b3ffdcb7db984c58439ac572386981a9d3d8ebca2b676bc3d5f49ae1 | 1a55fe9c1270a86a7330fc1de49a53b34a68c9df64fae016e176b182ff525e0d
main_cabinet | 1 | ASA | upright, acoustic floor on bed | 508add3e53b5287dd0edd0e8756aace97065ffa0 | 6b31ff89b20979489ec731bc93fd189d826ddc6e2b7d0720e8acf91319daecf7 | d83d488878b78bed603c215cb92176aecd294137abe28a6e0651825e5aee8ea4 | b0a0c9e65bb9bf2e52013f3593d5a2fc2e94cdc04dd2a7b1b9c63179aa0ba6d1
pressure_divider | 1 | ASA | flat, acoustic face on bed | 508add3e53b5287dd0edd0e8756aace97065ffa0 | fb886bcb085bad28c32e578b2da8491ec2d0c30e6bd1d09906af001666fdb15d | 724ff930f906a9b9b510bc95258c013684ef7385228e9d4cccf6b7029ca035f3 | b988ff9e76ac2cc925a7765e80e9f8739c1d89c8208525e10b4990135f53eb8e
mic_isolation_bushing | 4 | TPU 95A | flange face on bed | 508add3e53b5287dd0edd0e8756aace97065ffa0 | 90f2509dcf9b7dcbdd250a6addd4a2da0d5432b79742ae80d83535f732f620f3 | a8e1e585af05916e2651cc67b260639cb3399e8db39de0de6ef3b00217261b6c | 400130288ac4e9c5b794804840c1e9970f2ae59bd84fc051acfc26a55bdc64e0
active_driver_clamp_ring | 1 | ASA | lip face on bed | 508add3e53b5287dd0edd0e8756aace97065ffa0 | 49219a9354f31c17ad352a53171dda0d940fe3ae9091678eeec51baff80f1aed | 42f163d0242516c5b0e4440884b8e6e46f8259b28123cf18e7f7371e185ba4f6 | 37cd38cbc8bcb0aa3f4b791adbfbc4831f5862364a2f34e1ba2d2acd6b8f8171
passive_radiator_clamp_ring | 2 | ASA | lip face on bed | 508add3e53b5287dd0edd0e8756aace97065ffa0 | b8afa28a123f6b9e6f6db181d4adc55fa79777da87c0a1f3e197fe2d7a86e1d0 | d815899e6c421a4be3bd666cd43336cbb56a4efc4ce16c33823ca70961d07432 | 65e68cb2e2359e93f01308d0ca27ccf8d11b7efb25bc0b6d256d7b2d6b1f8c29
divider_gasket | 1 | 2 mm closed-cell EPDM | flat | 508add3e53b5287dd0edd0e8756aace97065ffa0 | 9584c91e3baaf77cd2b895dc9cfd0a6eb1fc9103266dd35ae97b4b173b8a3d65 | a64466225decfe24938ccb881aef61450c2f2c08fb067e5cdaa061c15b63029f | 671aa0fe1943604a9099435fec465f05f13bd3bd92e76b4f0241eb61240159fe
driver_gasket | 1 | 2 mm closed-cell EPDM | flat | 508add3e53b5287dd0edd0e8756aace97065ffa0 | eb5350624160d19124f0b27808006951998d66ade874c9c4789afbd9e1424aed | d1b9d1520c71e39b0d714bc48d0cc4f1fe4feb5ae484a9ce7fe4da198b12d01c | 30f13eaf987f89d7f5d83661972ef5c286067e73b7698c183ea05dc2ce1ac340
passive_radiator_gasket | 2 | 2 mm closed-cell EPDM | flat | 508add3e53b5287dd0edd0e8756aace97065ffa0 | 7bf026431f6b33af00fdf47c28ce29a317b86fd8cf81e211d13909a5e85721c9 | f87790a92ba2d4c31eb3152722fad955ff5eed292daa97681bbc6bfa8e19d9de | 9e21b7f44c3d64376006ddc7d95ccc61faf90f27698b7dae020f0d4125b6ad11
cable_gland | 1 | TPU 95A | body end on bed | 508add3e53b5287dd0edd0e8756aace97065ffa0 | cb000274d79f9745cdf6c9fbe498b26d6e425c50ac5b7f208b54b8733ea6f4bf | 138212ffbbd31028b12c122dadc5f6f667a95e22cd1436e8e2e46178636a1ee3 | c45f9af9e8b6f46998726a9502366c20bf9028ca2621aac1093774e76619d8aa
leak_test_adapter | 1 | TPU 95A | flange on bed; temporary service tool, not installed in service | 508add3e53b5287dd0edd0e8756aace97065ffa0 | 89c2dbd948d5cc79b10a139c9471f1a13794b945c086af31a6e8d31171c571e6 | c85cd1d8e4645b99751730bfbb4cf0894a7671d97eb27934a46885ef0c072dfa | eadcad0d016c1c4ec23056d5ca944236248b96b0bfaa7df2453a21c4bb93f77b
base_skirt | 1 | ASA | service opening on bed | 508add3e53b5287dd0edd0e8756aace97065ffa0 | deb7c94ce358572747e41263b808c2ea9daa36ac25259760cfbee66c371fe68e | 53f58e0e25e5458f6911006a58b97151a3f0b52bea4377b9ffcb5a4520de4d29 | 9e9f59ce92bc77daeda92dddfef9500d87fcef736ed5ce000133f67ba847a94a
bottom_service_plate | 1 | ASA | exterior face on bed | 508add3e53b5287dd0edd0e8756aace97065ffa0 | 7b4c03f91f2d27a629d4280d621e4d73c7eec052da4ab76a93670530947778c0 | cdfb8161864d926cf4328dcafd57aaad3241779508a0c0b8ff4cff7ff9cba8b1 | df1a6cb0bfc5f95267faf4b21684025439f5ffb523787c7da594d1920b1318db
ballast_cartridge | 1 | ASA | tray floor on bed | 508add3e53b5287dd0edd0e8756aace97065ffa0 | 8c1f46b92cf0d056f4923f826f3d16ddad4f3ff99e2c60a4d6d0a603c283d0c2 | d7af4a4dbbaed450ee44b7a45212d4cde373e475b2e9378e4f771a66f5fef083 | ea0fa2a120cb5c17bdf82a34264002baa7d6677a9ccda109a1c9f44ee4274c86
ballast_cartridge_lid | 1 | ASA | tongue face on bed | 508add3e53b5287dd0edd0e8756aace97065ffa0 | 7322510524c0c9e51204a09820e2525cf544f99a7f74b368fa84966213b8cf77 | ed4d63e6cc24cf7db55314bf4564463a918a338751170bd2cefd88fd9ccbbffe | 020d3b345322bbe1be7cb530f0a93aad8a5f32c883b4ff3017fe9b0f5dfb6288
coupon_official_interface | 1 | ASA | largest flat face on bed | 508add3e53b5287dd0edd0e8756aace97065ffa0 | ed5e71a6f797b338a66b7f820f11c8c9f6ff67f035a8ad91bffb487979e1772c | ea655c4c83ab3f19e25e51f2d64baf8bc563c6e44db20e393eaa46f568f36043 | 0e3e345c12c9dcfd7f7fd12b04f668d5851b84fdb8136cfb165ff613edc120d0
coupon_active_driver | 1 | ASA | largest flat face on bed | 508add3e53b5287dd0edd0e8756aace97065ffa0 | 7a42b6269180995c0ed633ca789a74bd0b36bb59b9e14de956a0333245199c0a | a9d56a3ce6a91ffb94b881f559bfe92d64e1df92ce8be2aa1f98f05171a45ca7 | c97b37a6407089a29eae69b56112c3db27d3b69662750000f2cbf3b29e066bab
coupon_passive_radiator | 1 | ASA | largest flat face on bed | 508add3e53b5287dd0edd0e8756aace97065ffa0 | 93c994481a5709fe0cbe3899e4170f2d3a678e2a2996bfe3ef80c6defe410534 | 9fe851166ad07f0a139529fe8a676a175caae19cf7b5402653a0712b5e5fe228 | c57ef91c370a44791104cc8bcfea566b608c65a1e7a27a05f7eaa44f133b3ce4
coupon_heat_set_insert | 1 | ASA | largest flat face on bed | 508add3e53b5287dd0edd0e8756aace97065ffa0 | 8566af01a965088535d99dc751c64920649ff2582840fbe0e5b995c05d9bbad7 | 126cbce18e5e62482e98927b2db260d56817ec47b95ef06a8112d23b8b9c1996 | bcf8a48eee88b610b904ab6a3bf38da945611cebe5a7e696ed5d192c73a8c066
coupon_gasket_base | 1 | ASA | largest flat face on bed | 508add3e53b5287dd0edd0e8756aace97065ffa0 | 773ba28a0c6571f4460a041274a4a65a39485a35bb63b2fb572ef47e5e571282 | bd7e39cc9a9b534c9db62d9f9fdb4bc5cd75d9432143c80f116e22691015c72d | 141222081f23699b908dcb0c16c8a9abf8e02ea21a586dfcc63309eddc8bb1cb
coupon_gasket_cap | 1 | ASA | largest flat face on bed | 508add3e53b5287dd0edd0e8756aace97065ffa0 | d917953da0027400451a49b9da0322e80dafa6843e9b517654ed7a354f4ccfb5 | 4e437028f3c4da3ce93ff7a7213829b5190407cd830e3160e8de58c31f3e23df | bc686392c21967b0a772c9cba186f0f432c633dc1f74f1bce1a0057b06e2947f
coupon_cable_passage | 1 | ASA | largest flat face on bed | 508add3e53b5287dd0edd0e8756aace97065ffa0 | adb0fd1c65e4e7301a3909d04584091ab45565f3013ff58fc1e4f1fc2b91998d | 0c7eb39c38ae3fd33ca31eb160cf78261a1757468892268d892551f89a082f65 | 00ee5552d13d348ffdc7ba873d7c45c5158c390cb931d606a5396075dd40a9e7

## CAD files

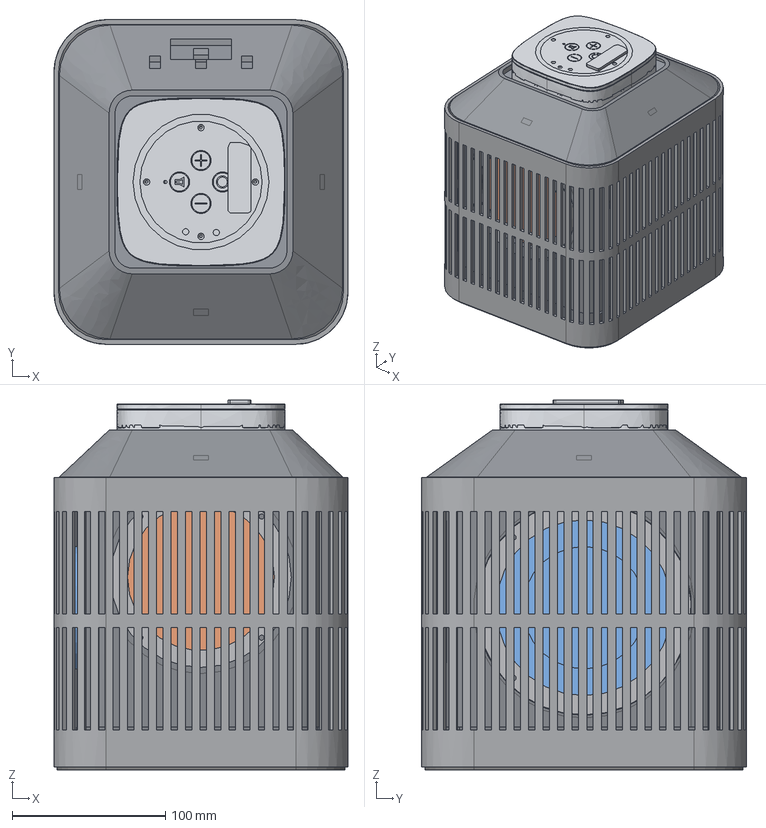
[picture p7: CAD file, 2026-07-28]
exports/assembly/satellite1_ultra_complete.step
192.0 x 212.0 x 241.7 mm
anti_slip_ring
outer_shell
main_cabinet
divider_gasket
pressure_divider
electronics_shroud
wire_gland
active_driver_gasket
active_driver_clamp_ring
driver_envelope
base_skirt
bottom_service_plate
ballast_cartridge
ballast_cartridge_lid
pr_-1_gasket
pr_-1_clamp_ring
pr_-1_envelope
pr_+1_gasket
pr_+1_clamp_ring
pr_+1_envelope
official_mid_plate
official_mid_plate_threads
official_top_plate
official_pcb_spacer
official_lock_ring
official_hat_batch1_rev4_1_envelope

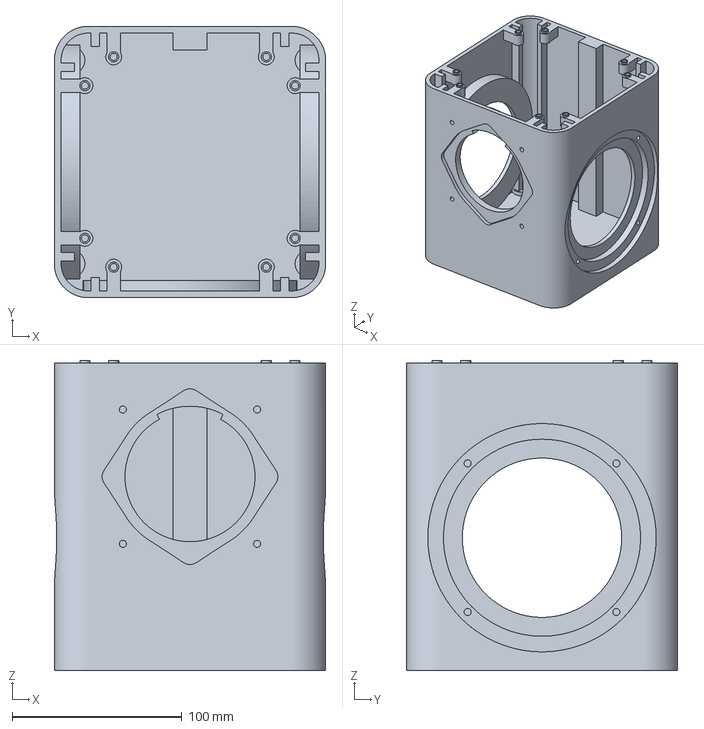
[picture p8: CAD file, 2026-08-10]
release/Satellite1-Ultra-RC1/3_ENCLOSURE_PARTS/01_MAIN_SPEAKER_BODY.3mf
160.0 x 160.0 x 182.8 mm

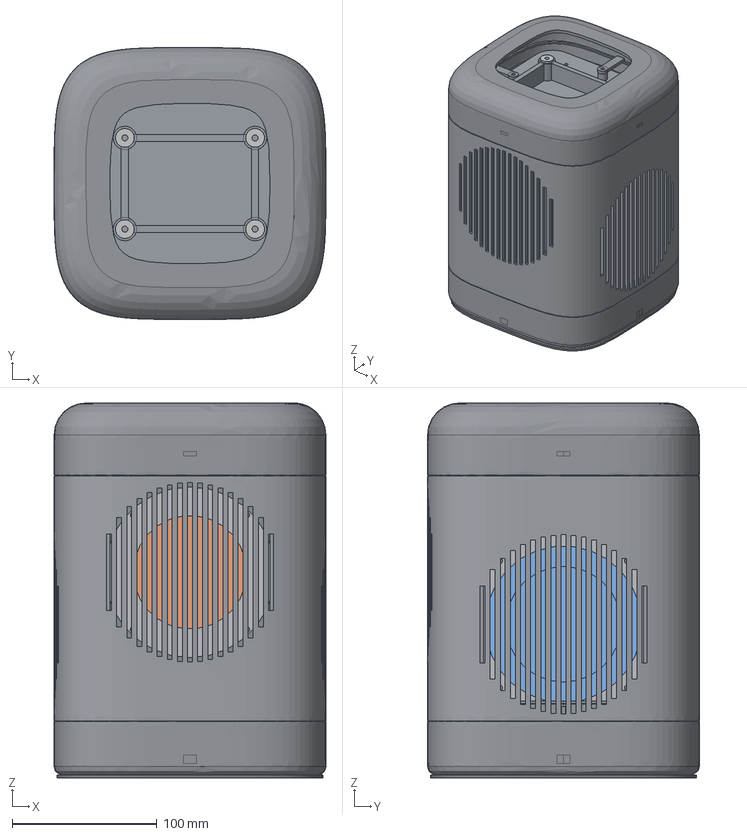
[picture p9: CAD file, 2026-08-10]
exports/assembly/satellite1_ultra_functional.step
188.0 x 188.0 x 259.4 mm
anti_slip_ring
shell_base
shell_grille
shell_crown
main_cabinet
divider_gasket
pressure_divider
wire_gland
active_driver_gasket
active_driver_clamp_ring
driver_envelope
base_skirt
bottom_service_plate
ballast_cartridge
ballast_cartridge_lid
pr_-1_gasket
pr_-1_clamp_ring
pr_-1_envelope
pr_+1_gasket
pr_+1_clamp_ring
pr_+1_envelope
mic_isolation_bushing_0
mic_isolation_bushing_1
mic_isolation_bushing_2
mic_isolation_bushing_3

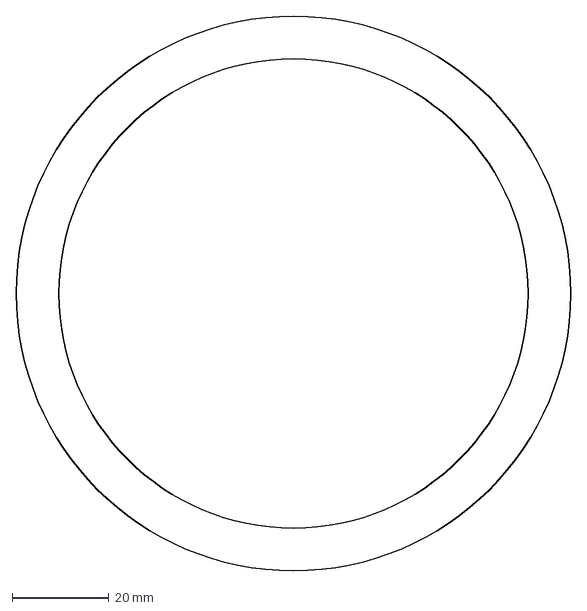
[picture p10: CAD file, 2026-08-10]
exports/gasket_templates/passive_radiator_gasket.dxf
114.6 x 114.6 mm

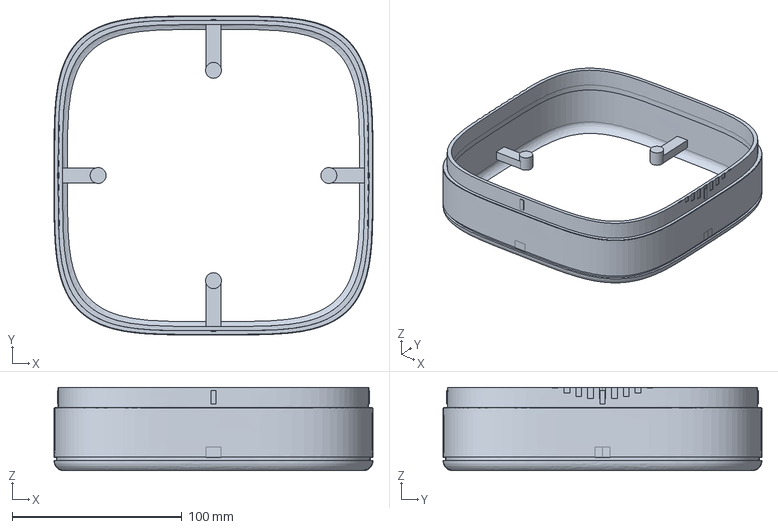
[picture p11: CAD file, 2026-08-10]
exports/step/shell_base_fabric.step
188.0 x 188.0 x 49.2 mm

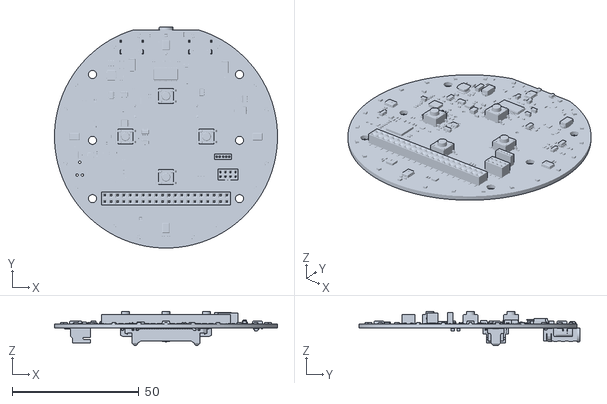
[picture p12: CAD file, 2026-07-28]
reference-assets/official/Satellite1-Enclosures/assets/Hat R2025.03.stl
88.0 x 87.2 x 13.6

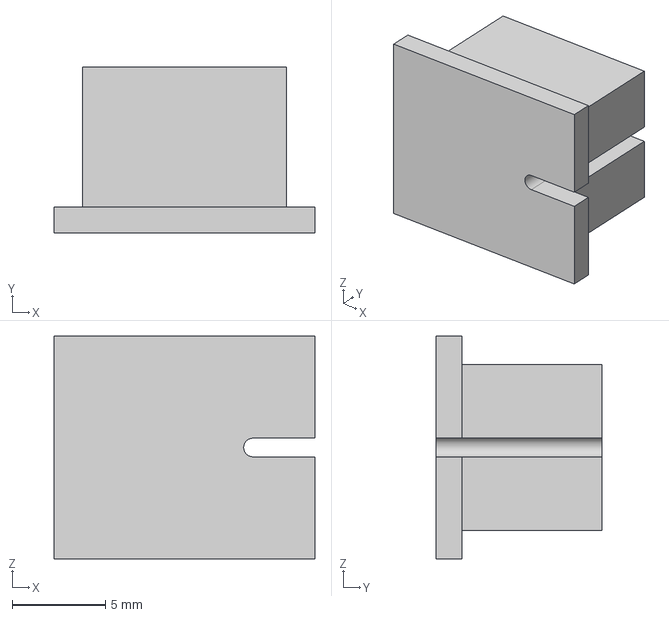
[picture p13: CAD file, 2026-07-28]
reference-assets/official/Satellite1-Enclosures/DIY Enclosures/Cylindrical Enclosures/Geometry Files/STEP/General Parts/1mm Wire Cover.step
14.0 x 8.90 x 11.9 mm

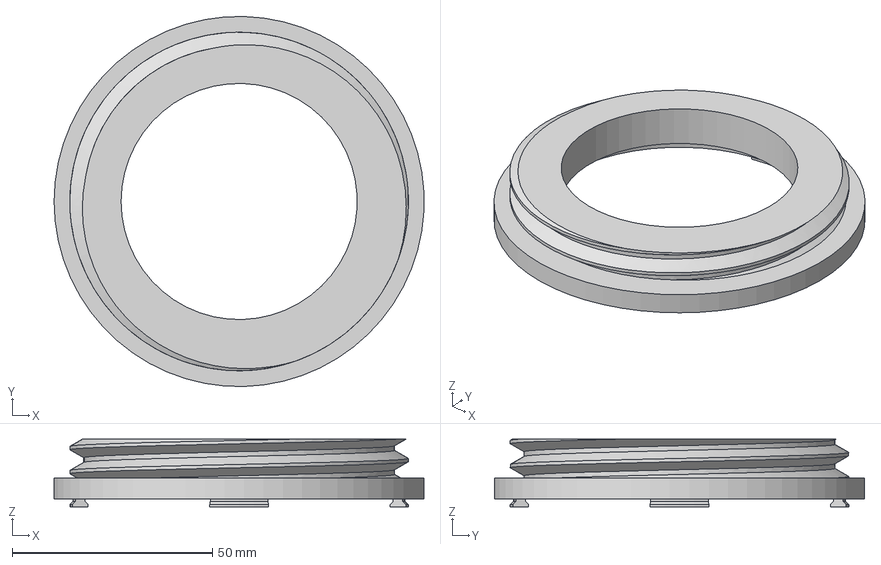
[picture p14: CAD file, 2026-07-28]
reference-assets/official/Satellite1-Enclosures/DIY Enclosures/Cylindrical Enclosures/Geometry Files/STEP/Speaker - Dayton Audio RS75-4/Speaker Adapter - RS75-4.step
92.4 x 92.5 x 16.9 mm

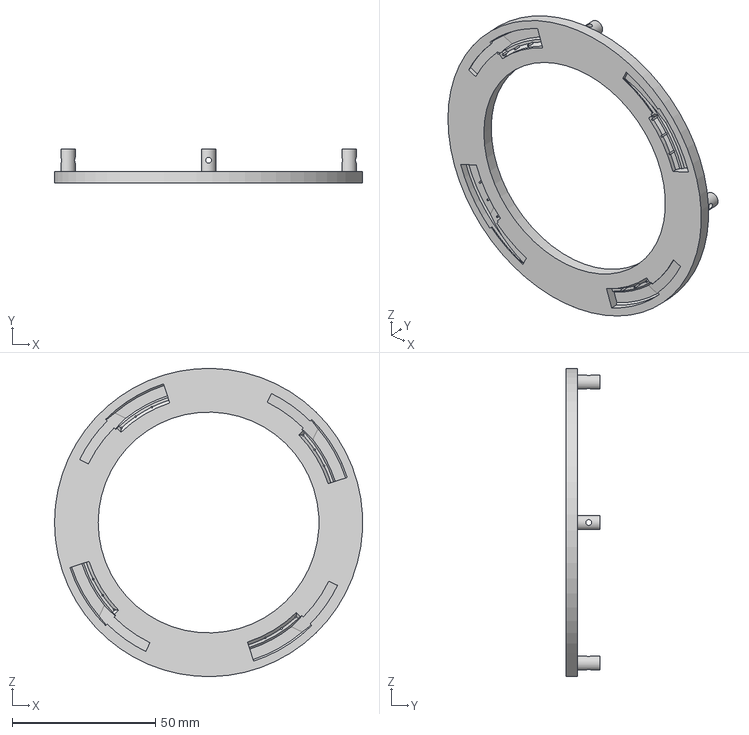
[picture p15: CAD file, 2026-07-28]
reference-assets/official/Satellite1-Enclosures/DIY Enclosures/Cylindrical Enclosures/Geometry Files/STEP/Speaker - GRS 3FR-4/Speaker Lock Ring - GRS 3FR-4.step
107.4 x 12.0 x 107.5 mm

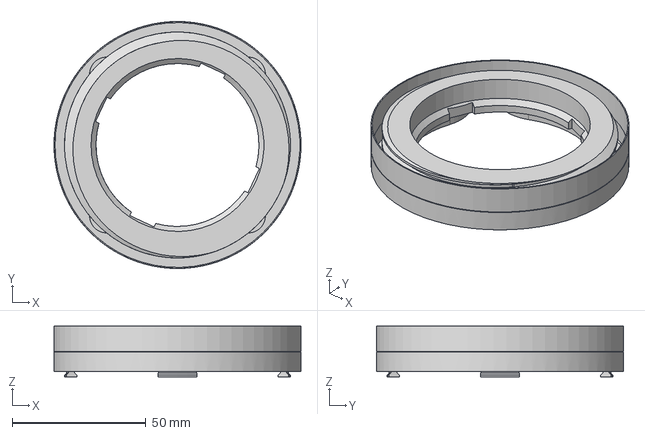
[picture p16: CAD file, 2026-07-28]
reference-assets/official/Satellite1-Enclosures/DIY Enclosures/Cylindrical Enclosures/Geometry Files/STEP/Speaker - TEBM46C - 20N/Speaker Adapter - TEBM46C-20N.step
92.5 x 92.5 x 18.9 mm

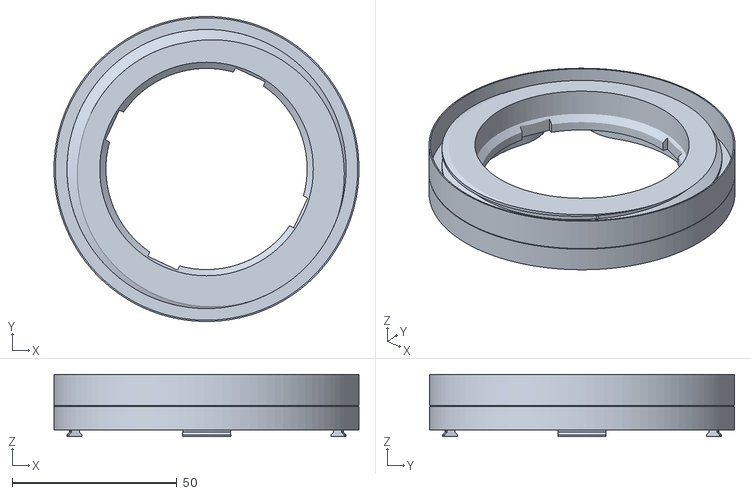
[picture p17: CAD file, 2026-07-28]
reference-assets/official/Satellite1-Enclosures/DIY Enclosures/Cylindrical Enclosures/Geometry Files/STL/Speaker - Tectonic TEBM46C-20N/Speaker Adapter - TEBM46C-20N.stl
92.5 x 92.5 x 19.0

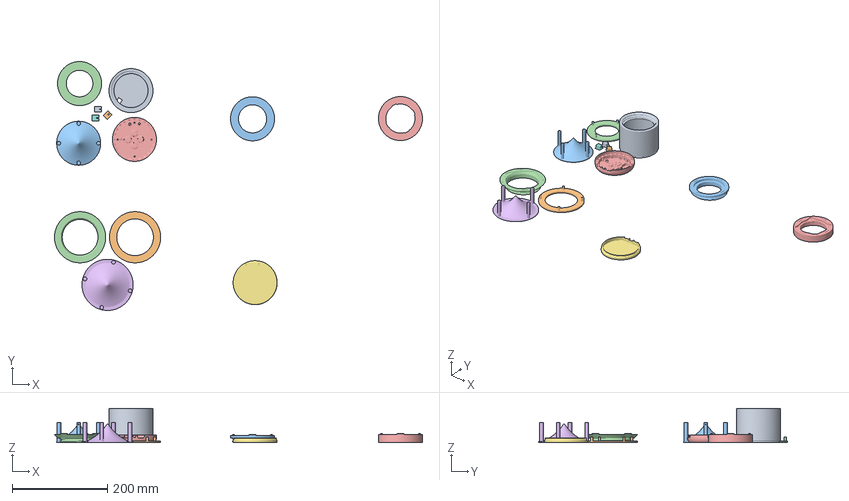
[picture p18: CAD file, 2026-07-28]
reference-assets/official/Satellite1-Enclosures/DIY Enclosures/Cylindrical Enclosures/OrcaSlicer - Sat1 Dev Kit Speaker Enclosure.3mf
772.9 x 522.8 x 72.1 mm
Speaker Chamber Threaded.stl
Stand Lock Ring - GRS-3FR-4.stl
Speaker Adapter - RS75-4.stl
Speaker Adapter - GRS-3FR-4.stl
Speaker Adapter - TEBM46C-20N.stl
GRS-3FR-4 Speaker Stand
(Optional) Dev Kit UFO Base for No Speaker.stl
1.5mm Wire Cover.stl
1mm Wire Cover.stl
2mm Wire Cover.stl
Speaker Stand.stl
Lock Ring.stl
Dev Kit UFO Enclosure.stl

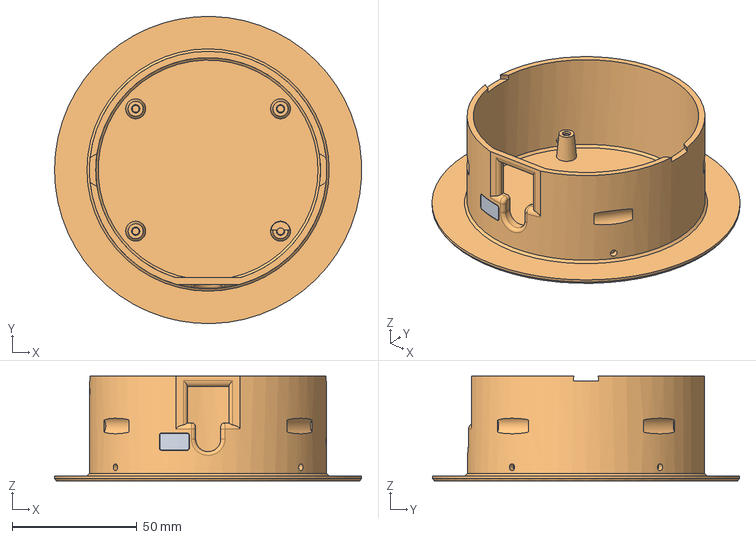
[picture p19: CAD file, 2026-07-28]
reference-assets/official/Satellite1-Enclosures/DIY Enclosures/In Ceiling Enclosures/geometry/STEP/In Ceiling Mini Enclosure.step
122.9 x 123.0 x 42.0 mm

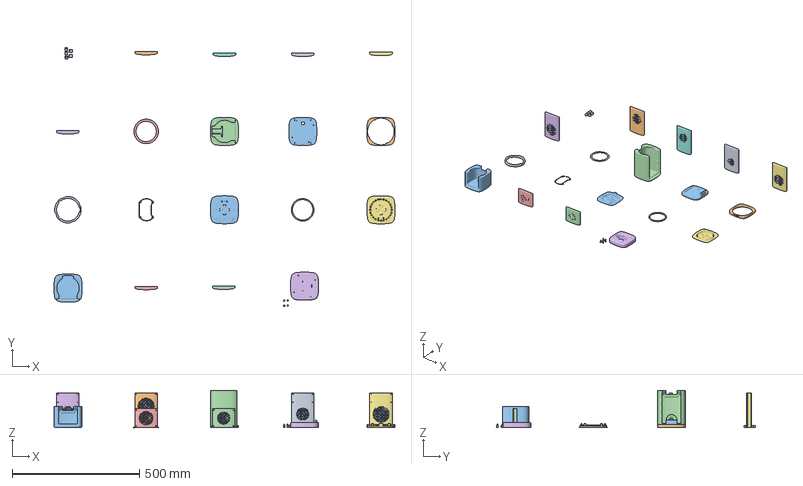
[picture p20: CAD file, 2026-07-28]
reference-assets/official/Satellite1-Enclosures/DIY Enclosures/Squircle Enclosures/Bambu Studio - Squircle Enclosure.3mf
1337.6 x 1016.5 x 145.8 mm
Speaker Plate Dayton Audio RS75-4 3in.stl
Speaker Plate GRS 3FR3 and Visaton FRS8-4 3.3in.stl
Wire Cover 1.5mm.stl
PCB Spacer.stl
Wire Cover 1mm.stl
Wire Cover 3mm.stl
Top Plate.stl
Top Plate Snap-In Diffuser Ring.stl
Mid-Plate Threads.stl
Lock Ring.stl
Mid-Plate.stl
25-Watt Speaker Chamber.stl
25-Watt Speaker Chamber Anti-Slip Ring.stl
Speaker Plate Dayton Audio PC83-4 3in.stl
Speaker Plate FaitalPRO 3FE25 3in.stl
Speaker Plate Tectonic TEBM46C20N-4 v5.stl
Wire Cover 2.5.stl
Wire Cover 2mm.stl
15-Watt Speaker Chamber.stl
15-Watt Speaker Plate Triple Speaker.stl
15-Watt Speaker Plate Tectonic TEBM46C20N-4.stl
3-Watt Speaker Chamber.stl
3-Watt Speaker Chamber Legs x 4.stl x 4
Top Plate MM Buttons

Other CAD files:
release/Satellite1-Ultra-RC1/ADVANCED/STEP/main_cabinet.step
exports/step/main_cabinet.step
reference-assets/official/Satellite1-Enclosures/DIY Enclosures/Cylindrical Enclosures/Geometry Files/STL/Speaker - GRS 3FR-4/Stand Lock Ring - GRS-3FR-4.stl
reference-assets/official/Satellite1-Enclosures/DIY Enclosures/In Ceiling Enclosures/In Ceiling Mini Enclosure (Orca Slicer Project).3mf
exports/3mf/active_driver_clamp_ring.3mf
exports/3mf/anti_slip_ring.3mf
exports/3mf/ballast_cartridge.3mf
exports/3mf/ballast_cartridge_lid.3mf
exports/3mf/base_skirt.3mf
exports/3mf/bottom_service_plate.3mf
exports/3mf/cable_gland.3mf
exports/3mf/coupon_active_driver.3mf
exports/3mf/coupon_cable_passage.3mf
exports/3mf/coupon_gasket_base.3mf
exports/3mf/coupon_gasket_cap.3mf
exports/3mf/coupon_heat_set_insert.3mf
exports/3mf/coupon_official_interface.3mf
exports/3mf/coupon_passive_radiator.3mf
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

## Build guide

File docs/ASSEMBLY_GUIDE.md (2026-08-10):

# Illustrated Assembly Guide

Front is -Y, rear is +Y, left/right radiators are -X/+X, and +Z points
toward the microphones. All torque values are `ENGINEERING_ESTIMATE`
until the selected insert/process is pull-tested.

Exploded part identification

## Exploded-view part key

| Exact part name | Qty | Material |
|---|---|---|
| anti_slip_ring | 1 | TPU 95A |
| shell_base | 1 | ASA |
| shell_grille | 1 | ASA |
| shell_crown | 1 | ASA |
| shell_base_fabric | 1 | ASA |
| shell_grille_fabric | 1 | ASA |
| shell_crown_fabric | 1 | ASA |
| main_cabinet | 1 | ASA |
| pressure_divider | 1 | ASA |
| mic_isolation_bushing | 4 | TPU 95A |
| active_driver_clamp_ring | 1 | ASA |
| passive_radiator_clamp_ring | 2 | ASA |
| divider_gasket | 1 | 2 mm closed-cell EPDM |
| driver_gasket | 1 | 2 mm closed-cell EPDM |
| passive_radiator_gasket | 2 | 2 mm closed-cell EPDM |
| cable_gland | 1 | TPU 95A |
| base_skirt | 1 | ASA |
| bottom_service_plate | 1 | ASA |
| ballast_cartridge | 1 | ASA |
| ballast_cartridge_lid | 1 | ASA |
| official_mid_plate | 1 | ASA (PETG alternative) |
| official_mid_plate_threads | 1 | ASA (PETG alternative) |
| official_pcb_spacer | 1 | ASA (PETG alternative) |
| official_lock_ring | 1 | ASA (PETG alternative) |
| official_top_plate | 1 | ASA (PETG alternative) |
| official_top_plate_snap_in_diffuser_ring | 1 | ASA (PETG alternative) |

Fastener identification

## Step 1: Identify and inspect the hardware

- Parts: Batch 1 Core rev4.1 and HAT rev4.1; O01 official_mid_plate; O02 official_mid_plate_threads; O03 official_pcb_spacer; O04 official_lock_ring; O05 official_top_plate; O06 official_top_plate_snap_in_diffuser_ring
- Fasteners: none
- Tools: bright light; calipers
- Gasket/seal: none
- Action: Confirm the board revision labels. Reject Batch 2 / Satellite1.1. Check off all six required official filenames in OFFICIAL_PARTS/REQUIRED_SINGLE_MATERIAL and every required custom 3MF in the Printing Guide. Inspect every sealing face and remove strings without rounding an edge.
- Pass: Correct Batch 1 hardware and every required printed part are present; no crack, warp, blocked bore, or damaged gasket land.
- Warning: Do not force or approximately place the Core. Its exact stack placement requires the physical official hardware.

Step 1 - Identify and inspect the hardware

## Step 2: Install and cold-check all M3 inserts

- Parts: main_cabinet, pressure_divider, base_skirt, ballast_cartridge, skin segments
- Fasteners: H01 inserts
- Tools: temperature-controlled iron; M3 insert tip; square
- Gasket/seal: none
- Action: At 250-270 C, press each insert into its labeled blind bore until flush and square. Let every insert cool for five minutes. Thread an M3 screw by hand for three turns.
- Pass: No insert spins, tilts, protrudes, or blocks before three turns.
- Warning: Do not torque a hot insert. Fumes and the iron can burn; ventilate and use eye protection.

Step 2 - Install and cold-check all M3 inserts

## Step 3: Wire and clamp the active driver

- Parts: main_cabinet, Dayton ND91-4, driver_gasket, active_driver_clamp_ring, JST-XH lead
- Fasteners: F04, 4 screws
- Tools: 2.0 mm hex; crimper or soldering iron; polarity tester
- Gasket/seal: G02
- Action: Peel the thin foam ring off the back of the driver's flange and throw it away; it is stuck on with tape, and G02 replaces it. Leaving both in place stacks two seals and neither compresses predictably. Mark the red conductor positive. Connect red to the terminal marked + and black to -. Look into the driver opening before you fit anything: at the top, in line with the topmost corner of the recess, the wall is notched wider. The driver's terminals sit in line with one of its four corner tabs and stand proud enough that the basket will not pass the opening anywhere else, so rotate the driver until its terminals point straight up into that notch. It only goes in one way round, and that is also the way the wire needs to leave to reach the cable passage in the divider above. Center G02, seat the driver from the -Y/front side, fit the clamp ring, and tighten F04 in two diagonal passes to 0.35 N m; never exceed 0.45 N m.
- Pass: Ring bottoms evenly; G02 is continuous all the way round and covers all four unused driver mounting holes; cone moves outward on a brief 1.5 V positive polarity pulse.
- Warning: Use only a brief low-voltage polarity pulse. Never connect a loose driver to the powered HAT.

Step 3 - Wire and clamp the active driver

## Step 4: Mass-match and clamp both passive radiators

- Parts: 2 passive radiators, 2 passive_radiator_gaskets, 2 clamp rings, matched tuning masses
- Fasteners: F05, 8 screws total
- Tools: 0.01 g scale; 2.0 mm hex
- Gasket/seal: G03, one per side
- Action: Trim and weigh two identical tuning masses to the value in reports/acoustics/summary.json, matching them within 0.02 g. Apply one centred on each radiator mass post. Install radiators on +/-X with matching orientation, then tighten each F05 crosswise to 0.35 N m; never exceed 0.45 N m.
- Pass: Added masses match within 0.02 g; both rings bottom evenly; surrounds move freely and do not touch the shell keep-out.
- Warning: Unequal mass defeats reaction-force cancellation. Do not press on either cone.

Step 4 - Mass-match and clamp both passive radiators

## Step 5: Route the cable, close the divider, and leak-check

- Parts: pressure_divider, divider_gasket, leak_test_adapter, cable_gland
- Fasteners: F03, 8 screws
- Tools: 2.0 mm hex; hand bulb; 0-500 Pa gauge; leak-detection solution
- Gasket/seal: G01; temporary adapter then G04
- Action: Pass both conductors through the divider. Fit the temporary adapter over them, place G01 without twists, and tighten F03 in a star pattern to 0.35 N m. Apply only 100-250 Pa with a hand bulb. Brush leak solution on external gasket seams; no bubbles are allowed. Vent, pull the adapter upward, and install G04 with its flange toward the electronics bay.
- Pass: No growing bubbles, abnormal diaphragm displacement, or audible leak; final gland cannot rotate or lift by finger force.
- Warning: Never use shop air, never exceed 250 Pa, and keep liquid away from electronics. This is a gross-leak screen, not an acoustic-Q measurement.

Step 5 - Route the cable, close the divider, and leak-check

## Step 6: Install the base and retained ballast

- Parts: base_skirt, ballast_cartridge, 2 steel plates, ballast lid, bottom_service_plate
- Fasteners: F06, F07, F08
- Tools: 2.0 mm hex; scale
- Gasket/seal: none
- Action: Attach the base skirt with F07. Place both deburred dry plates flat in the cartridge; there must be no rocking. Install the lid with F06, insert the cartridge from below, and capture it with the bottom service plate using F08.
- Pass: Cartridge mass matches the steel stack listed in BOM.csv; no plate moves when shaken gently; all four lid screws engage at least 3 mm.
- Warning: The steel stack is heavy. Keep fingers clear and do not operate the unit without the retained lid and service plate.

Step 6 - Install the base and retained ballast

## Step 7: Stack the three outer skin segments

- Parts: shell_base, shell_grille, shell_crown; lower assembly
- Fasteners: F09, 4 screws with nylon washers; F02, 4 screws into the divider
- Tools: 2.0 mm hex
- Gasket/seal: none
- Action: Work bottom to top. Slide shell_base up over the cabinet with FRONT at -Y, invert on a soft mat, and install F09 through the bottom service plate into its four bosses. Stand the unit back up. Press shell_grille down onto the exposed lap until its outer face meets the segment below; the four crush ribs give a firm, even resistance and the joint closes on 0.15 mm of interference, so it should need hand pressure and stay put. Press shell_crown on the same way, then bolt it down onto the divider's four bosses with F02. Check that all three grille windows line up with the driver and both radiators.
- Pass: Both seams show an even hairline shadow line all round with no step you can catch a fingernail on; no segment rocks or rattles when the body is tapped; at least 2 mm clearance from every clamp ring and surround; no wire visible through a window.
- Warning: Do not force a segment on if it binds — lift it off and check for a stringing artefact on the lap or a crush rib that printed proud. Never flex a segment over an obstruction. The crown must be bolted to the divider before the official stack goes on, because its tabs sit underneath.

Step 7 - Stack the three outer skin segments

## Step 8: Fit the mic isolators and the official Batch 1 upper stack

- Parts: mic_isolation_bushing x4; O01-O06 official prints; Batch 1 HAT/Core
- Fasteners: F01 (M3 x d4 shoulder screws, 16 mm shoulder), F10, F11; 4 of each
- Tools: 2.0 mm hex; ESD-safe bench
- Gasket/seal: none; electronics bay is outside the acoustic chamber
- Action: Press one TPU isolation bushing into each of the four divider counterbores, flange up. Seat O01 on the four bushing flanges — it must rest on elastomer, not on printed plastic. Install F01 and tighten until each shoulder bottoms firmly on the counterbore floor; the screw head then stops 0.3 mm above the plate and the plate stays floating on the TPU. Snap O06 into O05 (or use both O07/O08 during a multi-material O05 print; never install O06 and O08 together). Align O03's taller standoffs with the I/O side and locate the HAT. Install the Core/HAT using the official Batch 1 sequence. Align the logos and I/O on O04/O05, engage the snaps, and rotate the lock ring. Align O02's four nubs with O01 and keep I/O toward rear/+Y. Connect the keyed JST-XH speaker plug before closure.
- Pass: The official top sits flush with the surrounding flat top — you should feel a hairline, not a step or a lip. The upper stack has a barely perceptible give when pressed, which is the isolation working. USB-C remains reachable; cable has service slack and cannot enter a moving-part envelope; buttons click and diffuser/LED apertures remain clear.
- Warning: F01 must be M3 x d4 shoulder screws, not ordinary M3 screws. An ordinary screw clamps in parallel with the elastomer at roughly 35 times its stiffness, so the TPU carries under 3% of the load path and the isolation does nothing at all. If the plate feels rock solid, you have the wrong screws. Core placement is REQUIRES_PHYSICAL_VALIDATION: follow the official Batch 1 instructions and stop at any collision.

Step 8 - Fit the mic isolators and the official Batch 1 upper stack

## Step 9: Fit the anti-slip ring and complete inspection

- Parts: anti_slip_ring; complete assembly
- Fasteners: none
- Tools: hands; flashlight
- Gasket/seal: inspect G01-G04
- Action: Stretch the TPU ring evenly around the bottom rim. Set the unit upright and inspect all seams, fastener heads, slots, cable exits, buttons, and moving components.
- Pass: Unit stands without rocking; no rattle is heard during gentle handling; every fastener is present and every seal is continuously compressed.
- Warning: Do not power the unit until the commissioning checklist is ready.

Step 9 - Fit the anti-slip ring and complete inspection

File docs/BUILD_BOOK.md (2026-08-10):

# The Satellite1 Ultra Build Book

> **DO NOT PRINT THE FULL ENCLOSURE YET.**
> **PRINT AND MEASURE THE 8 SMALL CALIBRATION PIECES FIRST.**

This is the only document you need to follow from start to finish. Work through
the phases in order. Every other guide in this package is reference material
that this book points you to at the moment you need it.

You are building a serviceable passive-radiator speaker enclosure around the
FutureProofHomes Satellite1 **Batch 1** development kit: Core rev4.1 and HAT
rev4.1 / R2024.12.06. Satellite1.1 / Batch 2 does not fit and is not supported.

Expected difficulty is 4 out of 5. Nothing here is glued; every joint is a
screw into a brass insert, so you can open the unit again later.

The finished Satellite1 Ultra, assembled

## The whole build at a glance

| Phase | What you do | Roughly how long |
|---|---|---|
| 1 | Check your printer and buy the parts | ordering time |
| 2 | Print 8 small calibration pieces | 4-6 hours |
| 3 | Measure them and correct the files | 1 hour |
| 4 | Print 12 Ultra parts and 6 Satellite top parts | 3-5 days |
| 5 | Cut 3 foam gaskets from the templates | 30 minutes |
| 6 | Lay out and check every part | 30 minutes |
| 7 | Assemble, in 9 numbered steps | 3-4 hours |
| 8 | Test before you use it normally | 2 hours |

## Status you should know before you start

Every gate in this repository is a **digital** check: geometry, clearances,
volumes, exports, and documents. No physical unit has been built and measured.
Fit, sealing, acoustic output, thermals, Wi-Fi, microphones, buttons, LEDs, and
wake-word behaviour are all `REQUIRES_PHYSICAL_VALIDATION`. Your calibration,
leak, and commissioning checks in phases 3 and 8 are part of the build, not
optional extras.

---

# Phase 1 — Check your printer and buy the parts

## Your printer must actually fit the parts

The largest footprint belongs to `shell_base` at
**188 x 188 mm**. The tallest part is
`main_cabinet` at **183 mm**. Against the
configured usable travel of **220 x 200 x
250 mm** that leaves 32 mm and
12 mm of edge margin.

The outer skin is deliberately split into three stacked segments so no single
print is enormous. That keeps every part comfortably inside a common bed and
means a failed print costs you one segment, not the whole body.

- Purge lines, bed clips, and firmware exclusion zones all steal usable travel.
  Measure what your machine really reaches, then set `printing.build_volume_x`,
  `_y` and `_z` in `config/default.yaml` to what you measured. The printability
  gate reads those numbers and tests both in-plane rotations of every part, so
  it will actually fail if something does not fit.
- Printing a skin segment on its side is not supported: it puts support contact
  on the cosmetic surface.

You also need an enclosed printer, a 0.4 mm nozzle, and dry filament.

## Materials

- **ASA** for every rigid part. **PETG** is a documented alternative.
- **TPU 95A** for the two flexible parts: the cable seal and the bottom grip.
- **PLA+** is only acceptable for a display mock-up, never a finished unit.

## Tools

Digital calipers reading 0.01 mm, a scale reading 0.01 g, a 2.0 mm hex driver,
a temperature-controlled soldering iron with an M3 heat-set-insert tip,
wire strippers and a crimper or soldering iron, ESD protection, a hand bulb
with a 0-500 Pa gauge, and leak-detection solution.

## What to buy

Buy every item marked required in `BOM.csv`. The essentials are:

- One FutureProofHomes Satellite1 Batch 1 kit (E01).
- One Dayton Audio ND91-4 speaker (A01).
- Two Dayton Audio DSA115-PR passive radiators (A02).
- M3 heat-set inserts, with four spares (H01).
- Every M3 screw in `FASTENERS.csv`.
- One 300 x 300 mm sheet of 2.0 mm closed-cell EPDM foam (G00).
- Two mild-steel ballast plates (B01).
- Two matched sets of self-adhesive tuning mass for the radiators (B02).
- One 2-pin JST-XH speaker lead (H02).

`HARDWARE_AND_MATERIALS_GUIDE.pdf` gives the full specification for each line.

> Do not print the official original speaker chamber, speaker plate, or
> anti-slip ring. The Ultra parts replace all three.

---

# Phase 2 — Print the 8 calibration pieces

These are small. They exist so you discover your printer's real dimensional
behaviour before you spend days of filament on the big parts.

Open `PRINT_THESE_FILES/1_CALIBRATION_FIRST` and print every file, one at a
time, using the exact settings you will use for the enclosure:

| File | Print this many | Material |
|---|---|---|
| 01_MEASURE_YOUR_PRINTER.3mf | 1 | ASA |
| 02_CHECK_SCREWS_AND_INSERTS.3mf | 1 | ASA |
| 03_CHECK_SPEAKER_FIT.3mf | 1 | ASA |
| 04_CHECK_RADIATOR_FIT.3mf | 1 | ASA |
| 05_GASKET_TEST_BASE.3mf | 1 | ASA |
| 06_GASKET_TEST_TOP.3mf | 1 | ASA |
| 07_CHECK_CABLE_HOLE.3mf | 1 | ASA |
| 08_FLEXIBLE_CABLE_SEAL_TPU.3mf | 1 | TPU 95A |

Baseline settings: 0.4 mm nozzle, 0.20 mm layers, five walls, six top and six
bottom layers, 35% gyroid infill, no supports, 5 mm brim on the rigid pieces.
ASA runs 250-260 C nozzle and 100-110 C bed with the enclosure closed. PETG
runs 235-250 C nozzle and 75-85 C bed.

---

# Phase 3 — Measure the pieces and correct the files

This is the step that makes the big parts fit. `CALIBRATION_GUIDE.pdf` shows
exactly where each caliper jaw goes; the images below name each check.

Where to measure the Satellite top fit piece

Using the screw and insert as go/no-go gauges

Checking the speaker seats by hand

Checking a radiator seats by hand

Squeezing the foam between the two gasket pieces

Fitting the two real wires through the cable seal

## The eight checks

| Check | What you do | It passes when |
|---|---|---|
| XY scale | Inside caliper jaws across the engraved 110.60 mm recess, at three heights | 110.40-110.80 mm after correction |
| Z scale | Outside jaws across a clean 3.00 mm edge, at four corners | 2.90-3.10 mm |
| Screw clearance | Try a clean M3 screw in the 3.4, 3.5 and 3.6 mm holes | smallest hole the screw falls through without force |
| Insert bore | Install identical inserts into the 4.0-4.3 mm blind bores | square and flush, no crack, no spin |
| Speaker fit | Seat the real ND91-4 in its test ring | drops in by hand, flange lies flat, play under 0.30 mm |
| Radiator fit | Seat one real passive radiator in its test ring | drops in by hand, flange lies flat, play under 0.30 mm |
| Gasket squeeze | Clamp a strip of your actual foam until both hard stops touch | 15%-45% compression, no light path, foam not cut |
| Cable seal | Push the two real conductors and the TPU seal into the test hole | moderate finger force, seal cannot rotate or lift |

Do not measure a 3-4 mm hole with caliper tips. The screw and the insert are
the gauges.

## Enter your numbers

You have three ways to turn those measurements into corrected files. All three
produce the same `physical_calibration.yaml`.

1. **In your browser (easiest).** Open the calibration wizard page listed in
   the project README, type in what you measured, and it computes and
   downloads the file for you. Nothing to install.
2. **On GitHub.** Paste the file contents into the "Calibrated build" workflow
   and GitHub rebuilds the whole corrected package for you to download.
3. **On your own computer.** Run `python scripts/calibrate.py`, which asks the
   same questions and then runs `make calibrated-release`.

Reprint every calibration piece affected by a correction you entered, and
re-check it. Continue only when all eight checks pass on corrected pieces.

> If a piece fails, do not sand it and do not "make it work". Correct the
> number, regenerate, and reprint. Sanding a sealing face destroys the seal.

---

# Phase 4 — Print every enclosure part

Now print the real parts. Open `PRINT_THESE_FILES/2_ULTRA_ENCLOSURE_PARTS`
and print every file:

| File | Print this many | Material |
|---|---|---|
| 01_MAIN_SPEAKER_BODY.3mf | 1 | ASA |
| 02_ELECTRONICS_DIVIDER.3mf | 1 | ASA |
| 03_SPEAKER_CLAMP_RING.3mf | 1 | ASA |
| 04_RADIATOR_CLAMP_RING_PRINT_TWO.3mf | 2 | ASA |
| 05_BOTTOM_BASE.3mf | 1 | ASA |
| 06_WEIGHT_TRAY.3mf | 1 | ASA |
| 07_WEIGHT_TRAY_LID.3mf | 1 | ASA |
| 08_BOTTOM_ACCESS_PANEL.3mf | 1 | ASA |
| 09_MIC_ISOLATORS_TPU_PRINT_FOUR.3mf | 4 | TPU 95A |
| 10_OUTER_SKIN_BOTTOM.3mf | 1 | ASA |
| 11_OUTER_SKIN_MIDDLE_WITH_GRILLES.3mf | 1 | ASA |
| 12_OUTER_SKIN_TOP.3mf | 1 | ASA |
| 13_FLEXIBLE_BOTTOM_GRIP_TPU.3mf | 1 | TPU 95A |
| 14_LEAK_TEST_TOOL.3mf | 1 | ASA |

Note that the radiator clamp ring is the only part you print **twice**.

The grille skin segment, positioned on the bed

Then open `PRINT_THESE_FILES/3_SQUIRCLE_TOP_PARTS` and print all six official
Satellite top parts. These are not optional; they complete the normal
Satellite top:

| File | Print this many | Material |
|---|---|---|
| 01_SATELLITE_MID_PLATE.stl | 1 | ASA |
| 02_SATELLITE_THREADED_PLATE.stl | 1 | ASA |
| 03_CIRCUIT_BOARD_SPACER.stl | 1 | ASA |
| 04_TOP_LOCK_RING.stl | 1 | ASA |
| 05_BUTTON_AND_LIGHT_TOP.stl | 1 | ASA |
| 06_SNAP_IN_LIGHT_RING.stl | 1 | ASA |

`PRINTING_GUIDE.pdf` holds the full slicer baseline, the per-part orientation
sheets, and the inspection checklist. Check each part as it comes off the bed:
gasket lands must be continuous and unbroken, shell slots must all be open,
clamp rings must be flat within 0.20 mm, and no insert bore may have opened
into the chamber.

---

# Phase 5 — Cut the three foam gaskets

The gaskets are not printed. You cut them from your 2.0 mm EPDM sheet using the
1:1 templates in `GASKET_TEMPLATES/`. Print each template at exactly 100% scale
(no "fit to page"), check the printed size against the sheet, then cut with a
sharp knife or a cutting plotter.

| ID | Seal | How many | Material | Template |
|---|---|---|---|---|
| G01 | divider_gasket | 1 | 2.0 mm closed-cell EPDM, soft, smooth skin | GASKET_TEMPLATES/divider_gasket.dxf |
| G02 | driver_gasket | 1 | 2.0 mm closed-cell EPDM, soft, smooth skin | GASKET_TEMPLATES/driver_gasket.dxf |
| G03 | passive_radiator_gasket | 2 | 2.0 mm closed-cell EPDM, soft, smooth skin | GASKET_TEMPLATES/passive_radiator_gasket.dxf |

The fourth seal, G04, is the flexible cable seal you already printed in TPU as
`08_FLEXIBLE_CABLE_SEAL_TPU.3mf`.

Each gasket must be one continuous piece. Do not splice, join, or stretch a
gasket to fit.

Where each of the four seals sits

---

# Phase 6 — Lay out and check every part

Put everything on a clean table and account for it before you start. The
diagram below names every single piece and tells you which file it came from
or which item you purchased.

Every part in the build, with its file name

Check that you have all of it:

- All 12 printed Ultra parts, with two radiator clamp rings.
- All 6 printed Satellite top parts.
- One Dayton Audio ND91-4 speaker and two Dayton Audio DSA115-PR radiators.
- Three cut foam gaskets and one printed TPU cable seal.
- Every screw and insert in `FASTENERS.csv`.
- Two steel ballast plates, deburred and dry.
- Two matched radiator tuning masses, each weighed to
  8.00 g within 0.02 g.
- One red/black speaker lead with the correct plug.

The screws all look similar, so identify them by length before you begin:

Screw lengths and where each one is used

Do not begin assembly with a missing part.

---

# Phase 7 — Assemble

Nine steps, in this order. Each one shows what to install, which screws to use,
which seal it captures, and how to tell it is right.

Tighten every screw into a printed part gently, using the short arm of the
2 mm hex key: 0.35 N m is the target and 0.45 N m is the absolute maximum.
Stop as soon as the parts meet evenly. Do not keep turning "for luck".

### Step 1 of 9 — Identify and inspect the hardware

Build step 1: Identify and inspect the hardware

**You need:** Batch 1 Core rev4.1 and HAT rev4.1; O01 official_mid_plate; O02 official_mid_plate_threads; O03 official_pcb_spacer; O04 official_lock_ring; O05 official_top_plate; O06 official_top_plate_snap_in_diffuser_ring

**Screws:** none   **Seal:** none   **Tools:** bright light; calipers

**Do this:** Confirm the board revision labels. Reject Batch 2 / Satellite1.1. Check off all six required official filenames in OFFICIAL_PARTS/REQUIRED_SINGLE_MATERIAL and every required custom 3MF in the Printing Guide. Inspect every sealing face and remove strings without rounding an edge.

**It is right when:** Correct Batch 1 hardware and every required printed part are present; no crack, warp, blocked bore, or damaged gasket land.

> Careful: Do not force or approximately place the Core. Its exact stack placement requires the physical official hardware.

### Step 2 of 9 — Install and cold-check all M3 inserts

Build step 2: Install and cold-check all M3 inserts

**You need:** main_cabinet, pressure_divider, base_skirt, ballast_cartridge, skin segments

**Screws:** H01 inserts   **Seal:** none   **Tools:** temperature-controlled iron; M3 insert tip; square

**Do this:** At 250-270 C, press each insert into its labeled blind bore until flush and square. Let every insert cool for five minutes. Thread an M3 screw by hand for three turns.

**It is right when:** No insert spins, tilts, protrudes, or blocks before three turns.

> Careful: Do not torque a hot insert. Fumes and the iron can burn; ventilate and use eye protection.

### Step 3 of 9 — Wire and clamp the active driver

Build step 3: Wire and clamp the active driver

**You need:** main_cabinet, Dayton ND91-4, driver_gasket, active_driver_clamp_ring, JST-XH lead

**Screws:** F04, 4 screws   **Seal:** G02   **Tools:** 2.0 mm hex; crimper or soldering iron; polarity tester

**Do this:** Peel the thin foam ring off the back of the driver's flange and throw it away; it is stuck on with tape, and G02 replaces it. Leaving both in place stacks two seals and neither compresses predictably. Mark the red conductor positive. Connect red to the terminal marked + and black to -. Look into the driver opening before you fit anything: at the top, in line with the topmost corner of the recess, the wall is notched wider. The driver's terminals sit in line with one of its four corner tabs and stand proud enough that the basket will not pass the opening anywhere else, so rotate the driver until its terminals point straight up into that notch. It only goes in one way round, and that is also the way the wire needs to leave to reach the cable passage in the divider above. Center G02, seat the driver from the -Y/front side, fit the clamp ring, and tighten F04 in two diagonal passes to 0.35 N m; never exceed 0.45 N m.

**It is right when:** Ring bottoms evenly; G02 is continuous all the way round and covers all four unused driver mounting holes; cone moves outward on a brief 1.5 V positive polarity pulse.

> Careful: Use only a brief low-voltage polarity pulse. Never connect a loose driver to the powered HAT.

### Step 4 of 9 — Mass-match and clamp both passive radiators

Build step 4: Mass-match and clamp both passive radiators

**You need:** 2 passive radiators, 2 passive_radiator_gaskets, 2 clamp rings, matched tuning masses

**Screws:** F05, 8 screws total   **Seal:** G03, one per side   **Tools:** 0.01 g scale; 2.0 mm hex

**Do this:** Trim and weigh two identical tuning masses to the value in reports/acoustics/summary.json, matching them within 0.02 g. Apply one centred on each radiator mass post. Install radiators on +/-X with matching orientation, then tighten each F05 crosswise to 0.35 N m; never exceed 0.45 N m.

**It is right when:** Added masses match within 0.02 g; both rings bottom evenly; surrounds move freely and do not touch the shell keep-out.

> Careful: Unequal mass defeats reaction-force cancellation. Do not press on either cone.

### Step 5 of 9 — Route the cable, close the divider, and leak-check

Build step 5: Route the cable, close the divider, and leak-check

**You need:** pressure_divider, divider_gasket, leak_test_adapter, cable_gland

**Screws:** F03, 8 screws   **Seal:** G01; temporary adapter then G04   **Tools:** 2.0 mm hex; hand bulb; 0-500 Pa gauge; leak-detection solution

**Do this:** Pass both conductors through the divider. Fit the temporary adapter over them, place G01 without twists, and tighten F03 in a star pattern to 0.35 N m. Apply only 100-250 Pa with a hand bulb. Brush leak solution on external gasket seams; no bubbles are allowed. Vent, pull the adapter upward, and install G04 with its flange toward the electronics bay.

**It is right when:** No growing bubbles, abnormal diaphragm displacement, or audible leak; final gland cannot rotate or lift by finger force.

> Careful: Never use shop air, never exceed 250 Pa, and keep liquid away from electronics. This is a gross-leak screen, not an acoustic-Q measurement.

### Step 6 of 9 — Install the base and retained ballast

Build step 6: Install the base and retained ballast

**You need:** base_skirt, ballast_cartridge, 2 steel plates, ballast lid, bottom_service_plate

**Screws:** F06, F07, F08   **Seal:** none   **Tools:** 2.0 mm hex; scale

**Do this:** Attach the base skirt with F07. Place both deburred dry plates flat in the cartridge; there must be no rocking. Install the lid with F06, insert the cartridge from below, and capture it with the bottom service plate using F08.

**It is right when:** Cartridge mass matches the steel stack listed in BOM.csv; no plate moves when shaken gently; all four lid screws engage at least 3 mm.

> Careful: The steel stack is heavy. Keep fingers clear and do not operate the unit without the retained lid and service plate.

### Step 7 of 9 — Stack the three outer skin segments

Build step 7: Stack the three outer skin segments

**You need:** shell_base, shell_grille, shell_crown; lower assembly

**Screws:** F09, 4 screws with nylon washers; F02, 4 screws into the divider   **Seal:** none   **Tools:** 2.0 mm hex

**Do this:** Work bottom to top. Slide shell_base up over the cabinet with FRONT at -Y, invert on a soft mat, and install F09 through the bottom service plate into its four bosses. Stand the unit back up. Press shell_grille down onto the exposed lap until its outer face meets the segment below; the four crush ribs give a firm, even resistance and the joint closes on 0.15 mm of interference, so it should need hand pressure and stay put. Press shell_crown on the same way, then bolt it down onto the divider's four bosses with F02. Check that all three grille windows line up with the driver and both radiators.

**It is right when:** Both seams show an even hairline shadow line all round with no step you can catch a fingernail on; no segment rocks or rattles when the body is tapped; at least 2 mm clearance from every clamp ring and surround; no wire visible through a window.

> Careful: Do not force a segment on if it binds — lift it off and check for a stringing artefact on the lap or a crush rib that printed proud. Never flex a segment over an obstruction. The crown must be bolted to the divider before the official stack goes on, because its tabs sit underneath.

### Step 8 of 9 — Fit the mic isolators and the official Batch 1 upper stack

Build step 8: Fit the mic isolators and the official Batch 1 upper stack

**You need:** mic_isolation_bushing x4; O01-O06 official prints; Batch 1 HAT/Core

**Screws:** F01 (M3 x d4 shoulder screws, 16 mm shoulder), F10, F11; 4 of each   **Seal:** none; electronics bay is outside the acoustic chamber   **Tools:** 2.0 mm hex; ESD-safe bench

**Do this:** Press one TPU isolation bushing into each of the four divider counterbores, flange up. Seat O01 on the four bushing flanges — it must rest on elastomer, not on printed plastic. Install F01 and tighten until each shoulder bottoms firmly on the counterbore floor; the screw head then stops 0.3 mm above the plate and the plate stays floating on the TPU. Snap O06 into O05 (or use both O07/O08 during a multi-material O05 print; never install O06 and O08 together). Align O03's taller standoffs with the I/O side and locate the HAT. Install the Core/HAT using the official Batch 1 sequence. Align the logos and I/O on O04/O05, engage the snaps, and rotate the lock ring. Align O02's four nubs with O01 and keep I/O toward rear/+Y. Connect the keyed JST-XH speaker plug before closure.

**It is right when:** The official top sits flush with the surrounding flat top — you should feel a hairline, not a step or a lip. The upper stack has a barely perceptible give when pressed, which is the isolation working. USB-C remains reachable; cable has service slack and cannot enter a moving-part envelope; buttons click and diffuser/LED apertures remain clear.

> Careful: F01 must be M3 x d4 shoulder screws, not ordinary M3 screws. An ordinary screw clamps in parallel with the elastomer at roughly 35 times its stiffness, so the TPU carries under 3% of the load path and the isolation does nothing at all. If the plate feels rock solid, you have the wrong screws. Core placement is REQUIRES_PHYSICAL_VALIDATION: follow the official Batch 1 instructions and stop at any collision.

### Step 9 of 9 — Fit the anti-slip ring and complete inspection

Build step 9: Fit the anti-slip ring and complete inspection

**You need:** anti_slip_ring; complete assembly

**Screws:** none   **Seal:** inspect G01-G04   **Tools:** hands; flashlight

**Do this:** Stretch the TPU ring evenly around the bottom rim. Set the unit upright and inspect all seams, fastener heads, slots, cable exits, buttons, and moving components.

**It is right when:** Unit stands without rocking; no rattle is heard during gentle handling; every fastener is present and every seal is continuously compressed.

> Careful: Do not power the unit until the commissioning checklist is ready.

---

# Phase 8 — Test before you use it

Complete every check in `TESTING_AND_COMMISSIONING_GUIDE.pdf`. The short
version:

- The gentle 100-250 Pa leak screen shows no growing bubble at any seal.
- The speaker cone moves outward on a brief positive polarity pulse.
- Both radiators move freely and never scrape.
- Every button clicks once and returns.
- Every LED segment lights evenly.
- All four microphones work.
- USB-C plugs in and out without touching the shell.
- Wi-Fi connects, and you have recorded the signal beside a bare kit.
- There is no buzz, rattle, air whistle, overheating, or softened plastic.

Never use shop air on this enclosure, and never exceed 250 Pa.

Stop using the unit if any check fails. Fix the cause and repeat the test.

---

# Optional — Wrapping the body in speaker cloth

Entirely optional, and purely cosmetic: the enclosure is finished and airtight
without it. Cloth hides every print seam and layer line, so the body reads as
one continuous surface. The grille windows stay acoustically open underneath.

**Decide before you print.** The wrap needs the `*_FOR_FABRIC` skin files, which
are the same three segments with a concealed retention channel inside each roll.
The standard files have no channel, because on a bare printed finish it reads as
a horizontal line — exactly what this design exists to remove. You cannot add
the channel later without reprinting.

## What to buy

- About 0.5 m of **acoustically transparent speaker grille cloth**. Stretch
  knit intended for loudspeakers is right; upholstery fabric, canvas and
  blackout linings are not.
- **The breath test:** hold a single layer over your mouth and breathe out
  hard. If you feel noticeable resistance, it will audibly dull the treble.
  Anything you can breathe through freely is fine.
- A small tube of **contact adhesive**. Not superglue, which wicks and stiffens.

## Steps

1. **Print the fabric variants.** From `PRINT_THESE_FILES/2_ULTRA_PARTS`, use
   `10F`, `11F` and `12F` in place of `10`, `11` and `12`. Everything else is
   unchanged.
2. **Assemble the three segments first**, exactly as in phase 7, and bolt them
   down. Wrapping before assembly puts a fabric edge inside a lap joint, which
   will hold the seam open.
3. **Cut a rectangle** about 30 mm taller than the body and long enough to go
   right round plus 25 mm of overlap. Cut with the stretch running **around**
   the body, not up it.
4. **Find the overlap seam position.** Put it on the rear (+Y) face, which has
   no grille window. It is the only part of the wrap you will be able to see.
5. **Tension it evenly.** Work from the seam outward in both directions,
   keeping the weave straight. A squircle shows tension variation at the corners
   far more than a cylinder does, so check the weave stays square as it passes
   each corner rather than pulling into a curve.
6. **Tuck the top edge** into the channel under the top roll with a blunt
   plastic tool. Do the whole perimeter before committing any adhesive.
7. **Tuck the bottom edge** into the lower channel the same way, keeping the
   vertical tension while you work.
8. **Glue last, and only inside the channel.** A thin bead in the channel only.
   Keep adhesive away from the grille windows: it stiffens the cloth locally and
   changes its acoustic transparency, which you cannot undo.
9. **Trim the overlap** flush at the rear seam once the adhesive has set.

## Checks

- The weave runs straight and square across all four faces, with no diagonal
  pull at the corners.
- All three grille windows are still visibly open cloth, with no adhesive
  bleed and no stretched-thin patches.
- The cloth still passes the breath test after wrapping. If tension has closed
  it up over a window, it is too tight.
- The anti-slip ring still seats on the base without trapping a fabric edge.

---

# Phase 9 — Opening it again later

Disconnect power and wait five minutes. `MAINTENANCE_GUIDE.pdf` gives the safe
removal order for each subassembly.

The order things come apart in

Replace any gasket you disturb. Never cut a wire to get a part out, and never
reuse a torn or permanently flattened seal.

---

# If something goes wrong

| Symptom | Most likely cause | What to do |
|---|---|---|
| Calibration piece is warped | chamber too cool, or bed not clean | fix the printer and reprint; never compensate for a warped part |
| Every hole is too small | over-extrusion or elephant-foot compensation | fix flow and first-layer compensation before adding a CAD offset |
| Insert cracks the boss | bore too small or iron too hot | choose a larger bore or reduce dwell; never add torque |
| Speaker will not sit flat | print strings, or cutout too small | remove strings only; correct the cutout and reprint the coupon |
| Cable seal leaks or spins | conductor too thick, or wet TPU | confirm conductor OD is 1.8 mm or less, dry the TPU, reprint |
| Shell will not slide on | clamp ring or surround contact | stop immediately; find the contact rather than forcing the shell |
| Bubbles during the leak check | gasket twisted, pinched, or a screw left loose | vent, reopen, replace the gasket, and reseat evenly |
| One radiator moves more than the other | unequal tuning mass | reweigh both stacks; they must match within 0.02 g |

---

# What is still unproven

The geometry, exports, schedules, and documents in this release pass their
digital gates. No completed physical unit has been measured. That means your
own calibration, leak, acoustic, thermal, Wi-Fi, and microphone checks are the
first real evidence this design works. Record what you find.

`ENGINEERING_APPENDIX.md` lists every open risk, its consequence, and how to
close it.

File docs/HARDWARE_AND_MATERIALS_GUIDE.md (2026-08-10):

# Hardware and Materials Guide

Use Batch 1 only. The public Batch 1 pair is Core rev4.1 plus HAT rev4.1 /
R2024.12.06. If the board or packaging says Satellite1.1, rev5.1 Core, rev6.1
HAT, or requires an external Wi-Fi antenna, stop: that hardware is unsupported.

| ID | Category | Item | Exact specification | Qty | Required | Where to buy (US) |
|---|---|---|---|---|---|---|
| A01 | active driver | Dayton Audio ND91-4 | 4 ohm full-range driver; manufacturer model ND91-4 | 1 | yes | https://www.parts-express.com/Dayton-Audio-ND91-4-3-1-2-Aluminum-Cone-Full-Range-Driver-4-290-224 |
| A02 | passive radiator | Dayton Audio DSA115-PR | 4 inch passive radiator with M5 mass post | 2 | yes | https://www.parts-express.com/Dayton-Audio-DSA115-PR-4-Designer-Series-Aluminum-Cone-Passive-Radiator-295-544 |
| E01 | official electronics | FutureProofHomes Satellite1 Batch 1 development kit | Core rev4.1 + HAT rev4.1 / R2024.12.06; not Satellite1.1 | 1 | yes | https://futureproofhomes.net/products/satellite1-kit |
| H01 | insert | CNC Kitchen M3 x 5.7 heat-set insert | M3x0.5 internal thread, 5.7 mm length, 4.6 mm maximum OD | 48 | yes; includes four spares | https://www.amazon.com/s?k=CNC+Kitchen+M3+heat+set+insert+M3x5.7 |
| H02 | speaker cable | 2-pin JST-XH 2.54 mm speaker lead | 22 AWG stranded red/black, each insulated conductor OD <=1.8 mm, 350 mm minimum | 1 | yes | https://www.amazon.com/s?k=JST-XH+2.54mm+2+pin+speaker+pigtail |
| H03 | speaker terminals | solder the leads directly to the driver's terminal lugs | The ND91-4 ships with flat solder lugs, each pierced by an oblong hole: thread the conductor through, crimp it closed, then flow solder, so the joint is mechanically captive rather than relying on solder for strength. Dress the wire toward the driver axis, never outward, and heat-shrink each joint. Radial bulk here is the binding constraint: the terminals are the widest thing that must pass the 76.65 mm bore, they clear it only through the notch, and the leads have to be attached before the driver goes in because the chamber is sealed after. | 2 joints | recommended | https://www.amazon.com/s?k=3mm+heat+shrink+tubing+assortment |
| H04 | speaker terminals | 2.8 mm fully insulated female quick-disconnects | Alternative to H03, and the weaker one. A disconnect body plus its sleeve stands 2 to 3 mm proud of the lug on the side that has the least room, and it is a rattle source inside a sealed chamber. It also buys nothing: reaching this joint means pulling the driver anyway. If used, verify the blade width against the lug first, measured across the flat face and not along it, and confirm the fit on the speaker-fit coupon before committing to the cabinet print. | 2 | optional | https://www.amazon.com/s?k=2.8mm+fully+insulated+female+quick+disconnect |
| B01 | ballast | mild-steel plate | 100 x 92 x 6 mm, edges deburred, dry, light oil removed | 2 | yes | https://www.onlinemetals.com/en/buy/steel/0-25-mild-steel-plate-a36-hot-rolled/pid/1156 |
| B02 | radiator tuning | M5 washers plus self-adhesive lead-free strip for final trim | 8.00 g per radiator, the two sets matched within 0.02 g, applied centred on the M5 mass post. Stack M5 washers for the bulk -- about 13 of them at roughly 0.6 g each -- then trim self-adhesive lead-free strip for the last fraction of a gram. Weigh both radiators' finished stacks and match them, rather than trusting counts | 2 matched sets | yes; final mass requires physical tuning | https://www.amazon.com/s?k=M5+flat+washer+stainless+assortment |
| G00 | gasket stock | closed-cell EPDM foam sheet | 2.0 mm nominal, soft, smooth skin, ASTM D1056 2A1 or equivalent | one 300 x 300 mm sheet | yes | https://www.amazon.com/s?k=2mm+closed+cell+EPDM+foam+sheet+adhesive |
| D01 | optional acoustic material | polyester acoustic batting | not installed in RC1; reserve for measurement-led development only | 0 | no | https://www.parts-express.com/search?keywords=acoustic%20polyfill |
| O01 | official printed part | official_mid_plate | ASA (PETG alternative); exact file OFFICIAL_PARTS/REQUIRED_SINGLE_MATERIAL/official_mid_plate.stl; preserved official STL | 1 | yes | printed by you |
| O02 | official printed part | official_mid_plate_threads | ASA (PETG alternative); exact file OFFICIAL_PARTS/REQUIRED_SINGLE_MATERIAL/official_mid_plate_threads.stl; preserved official STL | 1 | yes | printed by you |
| O03 | official printed part | official_pcb_spacer | ASA (PETG alternative); exact file OFFICIAL_PARTS/REQUIRED_SINGLE_MATERIAL/official_pcb_spacer.stl; preserved official STL | 1 | yes | printed by you |
| O04 | official printed part | official_lock_ring | ASA (PETG alternative); exact file OFFICIAL_PARTS/REQUIRED_SINGLE_MATERIAL/official_lock_ring.stl; preserved official STL | 1 | yes | printed by you |
| O05 | official printed part | official_top_plate | ASA (PETG alternative); exact file OFFICIAL_PARTS/REQUIRED_SINGLE_MATERIAL/official_top_plate.stl; preserved official STL | 1 | yes | printed by you |
| O06 | official printed part | official_top_plate_snap_in_diffuser_ring | ASA (PETG alternative); exact file OFFICIAL_PARTS/REQUIRED_SINGLE_MATERIAL/official_top_plate_snap_in_diffuser_ring.stl; preserved official STL | 1 | yes | printed by you |
| O07 | official printed part | official_top_plate_mm_buttons | ASA (PETG alternative); exact file OFFICIAL_PARTS/OPTIONAL_MULTI_MATERIAL/official_top_plate_mm_buttons.stl; preserved official STL | 1 | optional alternative | printed by you |
| O08 | official printed part | official_top_plate_mm_diffuser_ring | ASA (PETG alternative); exact file OFFICIAL_PARTS/OPTIONAL_MULTI_MATERIAL/official_top_plate_mm_diffuser_ring.stl; preserved official STL | 1 | optional alternative | printed by you |
| F01 | fastener | M3 x 16 shoulder screw | M3 x d4 shoulder screw, A2-70 stainless, M3x0.5 | 4 | yes | https://www.mcmaster.com/screws/socket-head-screws/thread-size~m3/ |
| F02 | fastener | M3 x 8 button head screw | ISO 7380-1, A2-70 stainless, M3x0.5 | 4 | yes | https://www.mcmaster.com/screws/socket-head-screws/thread-size~m3/ |
| F03 | fastener | M3 x 8 socket cap screw | ISO 4762, A2-70 stainless, M3x0.5 | 8 | yes | https://www.mcmaster.com/screws/socket-head-screws/thread-size~m3/ |
| F04 | fastener | M3 x 10 socket cap screw | ISO 4762, A2-70 stainless, M3x0.5 | 4 | yes | https://www.mcmaster.com/screws/socket-head-screws/thread-size~m3/ |
| F05 | fastener | M3 x 10 socket cap screw | ISO 4762, A2-70 stainless, M3x0.5 | 8 | yes | https://www.mcmaster.com/screws/socket-head-screws/thread-size~m3/ |
| F06 | fastener | M3 x 6 button head screw | ISO 7380-1, A2-70 stainless, M3x0.5 | 4 | yes | https://www.mcmaster.com/screws/socket-head-screws/thread-size~m3/ |
| F07 | fastener | M3 x 10 socket cap screw | ISO 4762, A2-70 stainless, M3x0.5 | 4 | yes | https://www.mcmaster.com/screws/socket-head-screws/thread-size~m3/ |
| F08 | fastener | M3 x 8 button head screw | ISO 7380-1, A2-70 stainless, M3x0.5 | 4 | yes | https://www.mcmaster.com/screws/socket-head-screws/thread-size~m3/ |
| F09 | fastener | M3 x 8 button head screw | ISO 7380-1, A2-70 stainless, M3x0.5 | 4 | yes | https://www.mcmaster.com/screws/socket-head-screws/thread-size~m3/ |
| F10 | fastener | M3 x 8 socket cap screw | ISO 4762, A2-70 stainless, M3x0.5 | 4 | yes | https://www.mcmaster.com/screws/socket-head-screws/thread-size~m3/ |
| F11 | fastener | M3 x 8 socket cap screw | ISO 4762, A2-70 stainless, M3x0.5 | 4 | yes | https://www.mcmaster.com/screws/socket-head-screws/thread-size~m3/ |

All purchasing availability and prices must be checked by the builder.
Manufacturer geometry and electrical parameters are
`DERIVED_FROM_MANUFACTURER_DRAWING`; supplier availability is an
`ENGINEERING_ESTIMATE`.

No structural glue is used. No damping material is installed in RC1. Gaskets
are replaceable mechanically compressed EPDM, and the cable seal is TPU 95A.

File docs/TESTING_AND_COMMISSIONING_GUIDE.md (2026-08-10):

# Testing and Commissioning Guide

Every result in this guide requires a physical unit and is
`REQUIRES_PHYSICAL_VALIDATION`.

Seal locations

Final assembled inspection

## Before power

1. Verify red driver lead to + and black to -.
2. Confirm both radiators carry equal added mass: model target
   8.00 g each.
3. Confirm every screw ID and quantity against `FASTENERS.csv`.
4. Confirm G01-G04 are continuous and no wire touches a moving component.
5. Perform the 100-250 Pa gross-leak screen during assembly. Never use shop air.

## Controlled first power

Use a current-limited supported USB-C supply and the official Batch 1
firmware. Start muted, then at minimum volume.

- LEDs: all segments visible and even.
- Buttons: each click registers once and returns freely.
- USB-C: plug inserts/removes without shell contact.
- Wi-Fi: connect and record RSSI beside a bare Batch 1 control.
- Microphones: verify all four channels, then run 50 wake-word trials at 1, 3,
  and 5 m on-axis and 45 degrees.
- Audio: play a polarity pulse, then a 100-500 Hz sweep at low level. Stop for
  rub, buzz, air noise, or asymmetric radiator motion.

## Acoustic commissioning

Measure impedance magnitude and phase from 20 Hz to 20 kHz at low level. The
two low-frequency peaks should bracket tuning; the minimum between them is the
real Fb. Model targets are 60.0 Hz Fb,
4.39 ohm minimum impedance,
and 59.0 Hz f3. They are
`ENGINEERING_ESTIMATE`, not pass/fail measurements.

Start DSP with the modelled 51.0
Hz fourth-order high-pass and no positive bass boost. Final EQ, limiter, and
tuning mass require measured response and excursion.

## Thermal and reliability

Instrument Core SoC, amplifier area, and electronics-bay air. Test 60 minutes
idle and 60 minutes pink noise at 25 C, then repeat at 35 C. Pass only if every
supplier limit retains 15 C margin, there is no throttling, and no printed part
softens. Perform a gentle rattle check and repeat the leak/impedance check after
five service cycles.

Record results; do not change the repository status to physically validated
without the measurements.

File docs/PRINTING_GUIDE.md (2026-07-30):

# Printing Guide

`VERIFIED_DIGITALLY` for part geometry, stored 3MF units, and bounding boxes.
Actual print time, material use, shrinkage, warping, and airtightness are
`REQUIRES_PHYSICAL_VALIDATION`.

## Complete-part warning

You must print **both** the custom Ultra parts and the official Squircle upper
stack. The six mandatory official files are in
`OFFICIAL_PARTS/REQUIRED_SINGLE_MATERIAL/`; they are included in the release
and listed in the table below.

Do **not** print the official original speaker chamber, original speaker plate,
or original anti-slip ring. `main_cabinet.3mf`, the Ultra driver/radiator
hardware, `base_skirt.3mf`, and `anti_slip_ring.3mf` replace those parts.

O07 and O08 are optional multi-material inserts. If using them, load O05, O07,
and O08 together in the slicer and omit O06. For an ordinary single-material
printer, use O05 plus O06 and ignore the optional folder.

## Minimum printer volume

- Largest footprint: `shell_base`, 188.0 x
  188.0 mm in its documented orientation.
- Tallest part: `main_cabinet`, 182.8 mm.
- Configured usable travel: 220 x 200 x
  250 mm, leaving 32.0 mm and
  12.0 mm of edge margin.
- These figures are computed from the released B-reps every time this guide is
  generated, and the printability gate enforces them per axis against both
  in-plane rotations. Set your own measured travel in `config/default.yaml`
  under `printing.build_volume_*`.
- Side printing is unsupported: it places support contact on cosmetic surfaces.

## Authoritative slicer baseline

- ASA primary; PETG alternative. Do not mix materials within a bolted joint.
- 0.4 mm nozzle; 0.20 mm layer; 0.45 mm line width.
- Five walls; six top and six bottom layers; 35% gyroid.
- ASA: 250-260 C nozzle, 100-110 C bed, enclosed printer, low part cooling,
  draft shield if chamber is below 40 C.
- PETG: 235-250 C nozzle, 75-85 C bed, moderate cooling after layer three.
- Supports: disabled. The horizontal acoustic openings are self-progressing
  circular overhangs; inspect their upper arcs and never place support on a
  gasket seat.
- Seam: rear (+Y) for cabinet/shell/shroud; away from all gasket lands.
- Elephant-foot compensation: set in the slicer from your coupon, not by
  sanding the part.

## Print order and exact orientation

| Group | Filename | Qty | Material | Face/orientation | Supports | Brim | Difficulty | Calibration |
|---|---|---|---|---|---|---|---|---|
| cosmetic | anti_slip_ring.3mf | 1 | TPU 95A | flat | none | none | 2/5 | yes |
| cosmetic | shell_base.3mf | 1 | ASA | inverted, cut face on the bed | none | 3 mm | 2/5 | yes |
| cosmetic | shell_grille.3mf | 1 | ASA | upright, lower cut face on bed | none | 3 mm | 2/5 | yes |
| cosmetic | shell_crown.3mf | 1 | ASA | upright, flat top uppermost | none | 3 mm | 2/5 | yes |
| cosmetic | shell_base_fabric.3mf | 1 | ASA | inverted, cut face on the bed | none | 3 mm | 2/5 | yes |
| cosmetic | shell_grille_fabric.3mf | 1 | ASA | upright, lower cut face on bed | none | 3 mm | 2/5 | yes |
| cosmetic | shell_crown_fabric.3mf | 1 | ASA | upright, flat top uppermost | none | 3 mm | 2/5 | yes |
| structural | main_cabinet.3mf | 1 | ASA | upright, acoustic floor on bed | none | 10 mm | 4/5 | yes |
| structural | pressure_divider.3mf | 1 | ASA | flat, acoustic face on bed | none | none | 2/5 | yes |
| structural | mic_isolation_bushing.3mf | 4 | TPU 95A | flange face on bed | none | none | 2/5 | yes |
| structural | active_driver_clamp_ring.3mf | 1 | ASA | lip face on bed | none | none | 2/5 | yes |
| structural | passive_radiator_clamp_ring.3mf | 2 | ASA | lip face on bed | none | none | 2/5 | yes |
| calibration | cable_gland.3mf | 1 | TPU 95A | body end on bed | none | 5 mm | 2/5 | first |
| service tool | leak_test_adapter.3mf | 1 | TPU 95A | flange on bed; temporary service tool, not installed in service | none | none | 2/5 | yes |
| structural | base_skirt.3mf | 1 | ASA | service opening on bed | none | none | 2/5 | yes |
| structural | bottom_service_plate.3mf | 1 | ASA | exterior face on bed | none | none | 2/5 | yes |
| structural | ballast_cartridge.3mf | 1 | ASA | tray floor on bed | none | none | 2/5 | yes |
| structural | ballast_cartridge_lid.3mf | 1 | ASA | tongue face on bed | none | none | 2/5 | yes |
| calibration | coupon_official_interface.3mf | 1 | ASA | largest flat face on bed | none | 5 mm | 2/5 | first |
| calibration | coupon_active_driver.3mf | 1 | ASA | largest flat face on bed | none | 5 mm | 2/5 | first |
| calibration | coupon_passive_radiator.3mf | 1 | ASA | largest flat face on bed | none | 5 mm | 2/5 | first |
| calibration | coupon_heat_set_insert.3mf | 1 | ASA | largest flat face on bed | none | 5 mm | 2/5 | first |
| calibration | coupon_gasket_base.3mf | 1 | ASA | largest flat face on bed | none | 5 mm | 2/5 | first |
| calibration | coupon_gasket_cap.3mf | 1 | ASA | largest flat face on bed | none | 5 mm | 2/5 | first |
| calibration | coupon_cable_passage.3mf | 1 | ASA | largest flat face on bed | none | 5 mm | 2/5 | first |
| official required | OFFICIAL_PARTS/REQUIRED_SINGLE_MATERIAL/official_mid_plate.stl | 1 | ASA (PETG alternative) | lowest native-Z face on bed, as illustrated | none | none | 2/5 | after calibration |
| official required | OFFICIAL_PARTS/REQUIRED_SINGLE_MATERIAL/official_mid_plate_threads.stl | 1 | ASA (PETG alternative) | lowest native-Z face on bed, as illustrated | none | none | 2/5 | after calibration |
| official required | OFFICIAL_PARTS/REQUIRED_SINGLE_MATERIAL/official_pcb_spacer.stl | 1 | ASA (PETG alternative) | lowest native-Z face on bed, as illustrated | none | none | 2/5 | after calibration |
| official required | OFFICIAL_PARTS/REQUIRED_SINGLE_MATERIAL/official_lock_ring.stl | 1 | ASA (PETG alternative) | lowest native-Z face on bed, as illustrated | none | none | 2/5 | after calibration |
| official required | OFFICIAL_PARTS/REQUIRED_SINGLE_MATERIAL/official_top_plate.stl | 1 | ASA (PETG alternative) | lowest native-Z face on bed, as illustrated | none | none | 2/5 | after calibration |
| official required | OFFICIAL_PARTS/REQUIRED_SINGLE_MATERIAL/official_top_plate_snap_in_diffuser_ring.stl | 1 | ASA (PETG alternative) | lowest native-Z face on bed, as illustrated | none | none | 2/5 | after calibration |

The 3MF files already store millimetres and the documented orientation.

## CAD-derived orientation sheets

anti_slip_ring print orientation

shell_base print orientation

shell_grille print orientation

shell_crown print orientation

shell_base_fabric print orientation

shell_grille_fabric print orientation

shell_crown_fabric print orientation

main_cabinet print orientation

pressure_divider print orientation

mic_isolation_bushing print orientation

active_driver_clamp_ring print orientation

passive_radiator_clamp_ring print orientation

cable_gland print orientation

leak_test_adapter print orientation

base_skirt print orientation

bottom_service_plate print orientation

ballast_cartridge print orientation

ballast_cartridge_lid print orientation

coupon_official_interface print orientation

coupon_active_driver print orientation

coupon_passive_radiator print orientation

coupon_heat_set_insert print orientation

coupon_gasket_base print orientation

coupon_gasket_cap print orientation

coupon_cable_passage print orientation

## Official Squircle orientation sheets

official_mid_plate print orientation

official_mid_plate_threads print orientation

official_pcb_spacer print orientation

official_lock_ring print orientation

official_top_plate print orientation

official_top_plate_snap_in_diffuser_ring print orientation

official_top_plate_mm_buttons print orientation

official_top_plate_mm_diffuser_ring print orientation

## Inspection before continuing

- Cabinet and divider: continuous, glossy-enough gasket lands; no seam gap,
  crack, under-extrusion, or insert bore opened into the chamber.
- Shell: all slots open, four retention bridges intact, no warp at either rim.
- Clamp rings: flat within 0.20 mm on a surface plate; lip clean and continuous.
- Ballast cartridge: lid holes align; both plates lie flat; four bosses sound.
- TPU parts: no tear, string in a wire bore, or layer split.

Approximate filament and time vary too much by slicer and machine to be
verified digitally. Your slicer estimate is authoritative for planning; record
it before starting each full-size print.

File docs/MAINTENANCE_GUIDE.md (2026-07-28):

# Maintenance and Service Guide

Disconnect power and wait five minutes before service. Work on a soft mat.

## Access order

- Electronics: remove official top/lock ring as documented by
  FutureProofHomes, disconnect JST-XH, remove F01, then F02 and the shroud.
- Driver/radiators: remove anti-slip ring, F09, outer shell, then the relevant
  F04/F05 clamp ring. Replace the opened G02/G03 gasket.
- Divider/cable gland: remove the upper stack and shroud, then F03. Replace G01
  whenever the divider is lifted.
- Ballast: remove anti-slip ring and F08 bottom plate; withdraw cartridge.
  Remove F06 lid screws while the cartridge is supported.

Never cut a wire for service; unplug or release its terminal. Never reuse a
torn, permanently flattened, or contaminated gasket. Never lever a clamp ring
against a cone.

After service, repeat polarity, gross leak, low-level sweep, buttons, LEDs,
microphones, Wi-Fi, and thermal spot checks. Store spare G01-G04 seals flat,
dark, and clean. Vacuum shell slots with a soft brush; do not use solvents on
ASA.

Service disassembly direction

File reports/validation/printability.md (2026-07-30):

# Printability

- Overall status: `PASS`
- Evidence: `VERIFIED_DIGITALLY`
- Method: print-oriented bounding box of every exported part against a per-axis build volume, testing both in-plane rotations
- Physical gate (`REQUIRES_PHYSICAL_VALIDATION`): Slice each 3MF and confirm no support material touches a gasket land, seat face or insert bore; then print the coupon set.

The machine-readable source of this report is the adjacent JSON file. All unmeasured real-world performance remains `REQUIRES_PHYSICAL_VALIDATION`.

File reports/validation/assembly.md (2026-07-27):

# Assembly

- Overall status: `PASS`
- Evidence: `VERIFIED_DIGITALLY`
- Method: directed dependency graph over the documented assembly steps
- Physical gate (`REQUIRES_PHYSICAL_VALIDATION`): Perform one full assembly and disassembly on printed parts.

The machine-readable source of this report is the adjacent JSON file. All unmeasured real-world performance remains `REQUIRES_PHYSICAL_VALIDATION`.

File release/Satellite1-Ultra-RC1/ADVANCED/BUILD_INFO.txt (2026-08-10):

Satellite1 Ultra RC1
Generated from source commit 508add3e53b5287dd0edd0e8756aace97065ffa0

Status: DIGITAL_PROTOTYPE_READY. No physical unit has been built and measured.
Fit, sealing, acoustic performance, thermal margin, Wi-Fi, microphones, LEDs,
buttons and wake-word performance are all REQUIRES_PHYSICAL_VALIDATION.

Supported hardware: FutureProofHomes Satellite1 Batch 1, Core rev4.1 with
HAT rev4.1 / R2024.12.06. Satellite1.1 / Batch 2 is not supported.

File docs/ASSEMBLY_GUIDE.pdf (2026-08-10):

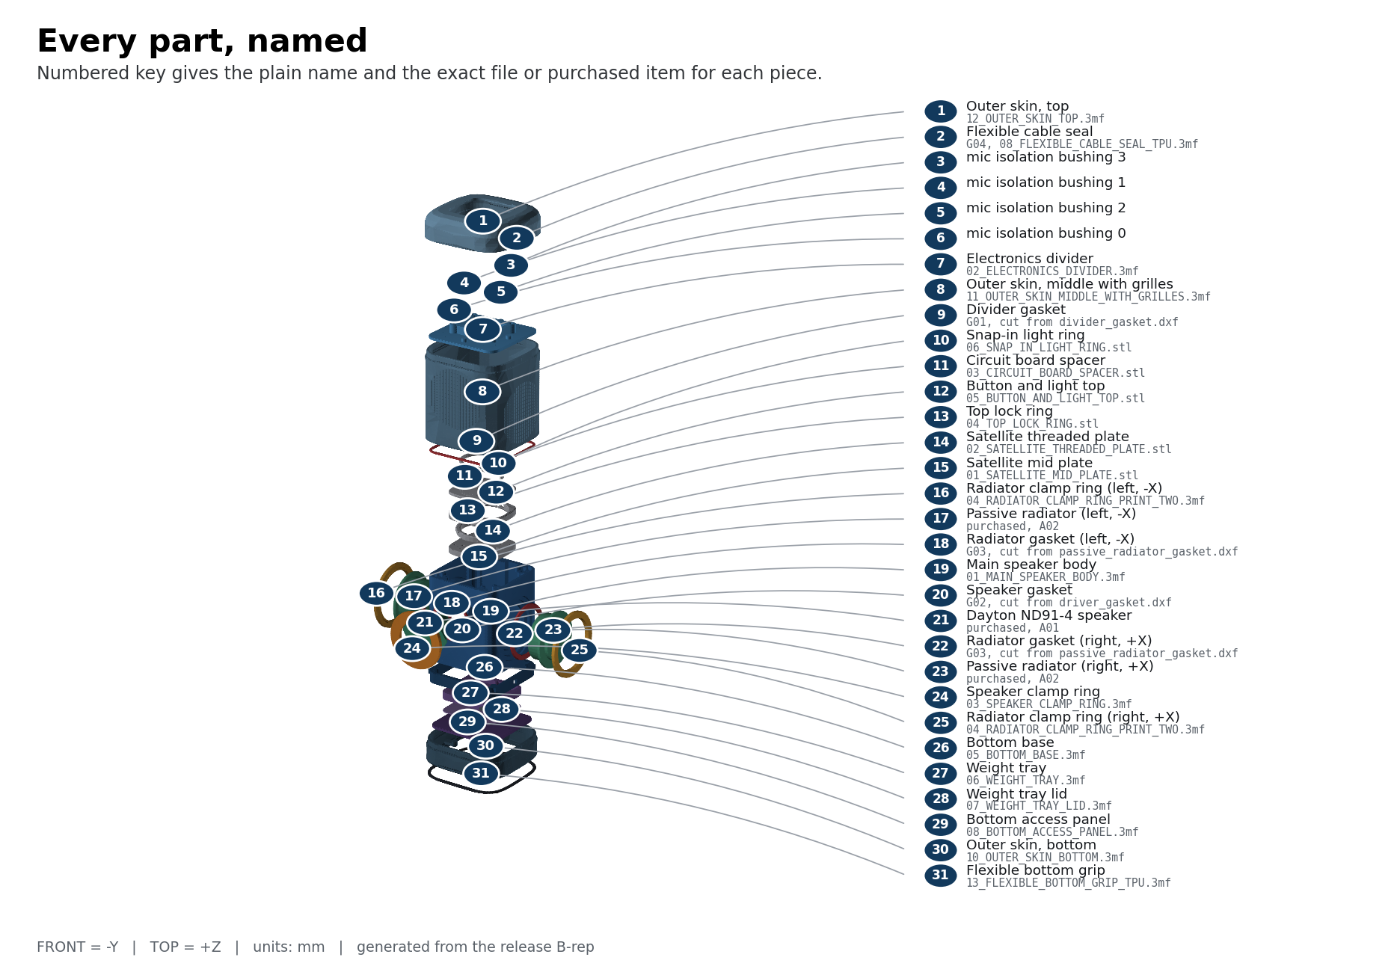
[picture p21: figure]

Satellite1 Ultra RC1 — DIGITAL_PROTOTYPE_READY | Page 1

# Illustrated Assembly Guide

Front is -Y, rear is +Y, left/right radiators are -X/+X, and +Z points toward the microphones. All torque values are ENGINEERING_ESTIMATE until the selected insert/process is pull-tested.

Exploded part identification

# Exploded-view part key

Exact part name | Qty | Material
anti_slip_ring | 1 | TPU 95A
shell_base | 1 | ASA
shell_grille | 1 | ASA
shell_crown | 1 | ASA
shell_base_fabric | 1 | ASA
shell_grille_fabric | 1 | ASA
shell_crown_fabric | 1 | ASA
main_cabinet | 1 | ASA
pressure_divider | 1 | ASA
mic_isolation_bushing | 4 | TPU 95A
active_driver_clamp_ring | 1 | ASA
passive_radiator_clamp_ring | 2 | ASA
divider_gasket | 1 | 2 mm closed-cell EPDM

Exact part name | Qty | Material
driver_gasket | 1 | 2 mm closed-cell EPDM
passive_radiator_gasket | 2 | 2 mm closed-cell EPDM
cable_gland | 1 | TPU 95A
base_skirt | 1 | ASA
bottom_service_plate | 1 | ASA
ballast_cartridge | 1 | ASA
ballast_cartridge_lid | 1 | ASA
official_mid_plate | 1 | ASA (PETG alternative)
official_mid_plate_threads | 1 | ASA (PETG alternative)
official_pcb_spacer | 1 | ASA (PETG alternative)
official_lock_ring | 1 | ASA (PETG alternative)
official_top_plate | 1 | ASA (PETG alternative)
official_top_plate_snap_in_diffuser_ring | 1 | ASA (PETG alternative)

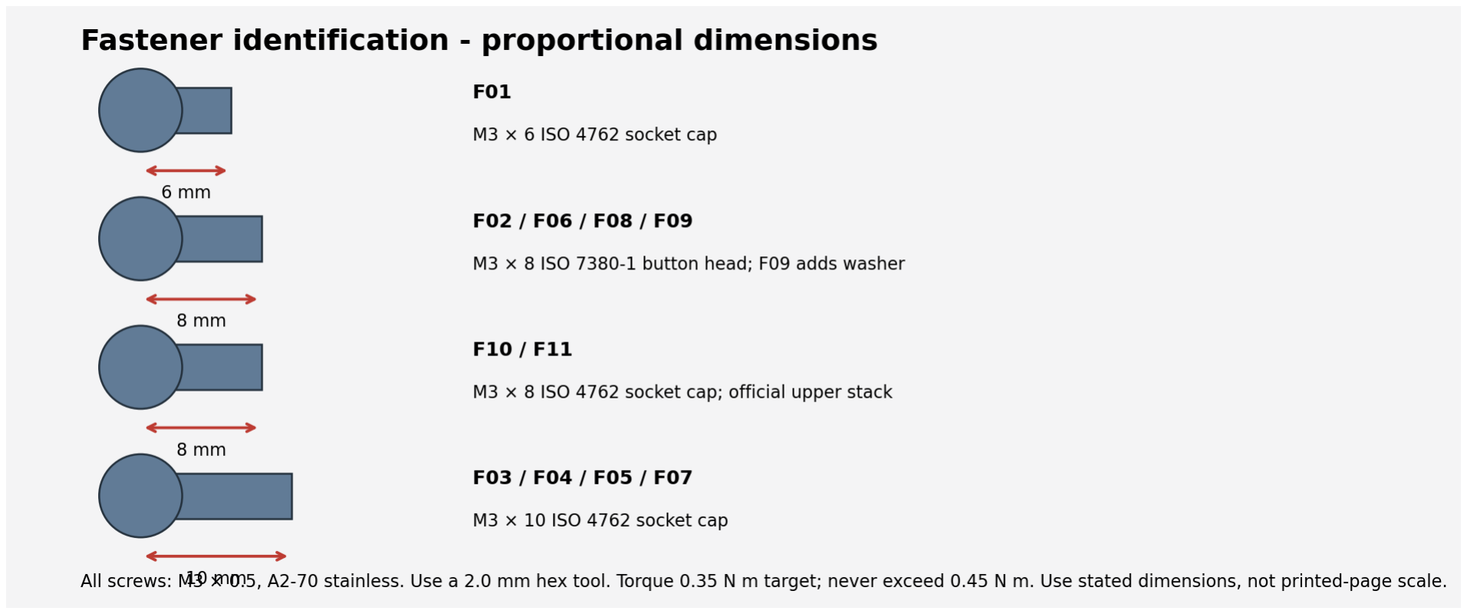
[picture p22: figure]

Fastener identification

# Step 1: Identify and inspect the hardware

- Parts: Batch 1 Core rev4.1 and HAT rev4.1; O01 official_mid_plate; O02 official_mid_plate_threads; O03 official_pcb_spacer; O04 official_lock_ring; O05 official_top_plate; O06 official_top_plate_snap_in_diffuser_ring
- Fasteners: none
- Tools: bright light; calipers
- Gasket/seal: none
- Action: Confirm the board revision labels. Reject Batch 2 / Satellite1.1. Check off all six required official filenames in OFFICIAL_PARTS/REQUIRED_SINGLE_MATERIAL and every required custom 3MF in the Printing Guide. Inspect every sealing face and remove strings without rounding an edge.
- Pass: Correct Batch 1 hardware and every required printed part are present; no crack, warp, blocked bore, or damaged gasket land.
- Warning: Do not force or approximately place the Core. Its exact stack placement requires the physical official hardware.

Step 1 - Identify and inspect the hardware

# Step 2: Install and cold-check all M3 inserts

- Parts: main_cabinet, pressure_divider, base_skirt, ballast_cartridge, skin segments
- Fasteners: H01 inserts
- Tools: temperature-controlled iron; M3 insert tip; square
- Gasket/seal: none
- Action: At 250-270 C, press each insert into its labeled blind bore until flush and square. Let every insert cool for five minutes. Thread an M3 screw by hand for three turns.
- Pass: No insert spins, tilts, protrudes, or blocks before three turns.
- Warning: Do not torque a hot insert. Fumes and the iron can burn; ventilate and use eye protection.

Step 2 - Install and cold-check all M3 inserts

# Step 3: Wire and clamp the active driver

- Parts: main_cabinet, Dayton ND91-4, driver_gasket, active_driver_clamp_ring, JST-XH lead
- Fasteners: F04, 4 screws
- Tools: 2.0 mm hex; crimper or soldering iron; polarity tester
- Gasket/seal: G02
- Action: Peel the thin foam ring off the back of the driver's flange and throw it away; it is stuck on with tape, and G02 replaces it. Leaving both in place stacks two seals and neither compresses predictably. Mark the red conductor positive. Connect red to the terminal marked + and black to -. Look into the driver opening before you fit anything: at the top, in line with the topmost corner of the recess, the wall is notched wider. The driver's terminals sit in line with one of its four corner tabs and stand proud enough that the basket will not pass the opening anywhere else, so rotate the driver until its terminals point straight up into that notch. It only goes in one way round, and that is also the way the wire needs to leave to reach the cable passage in the divider above. Center G02, seat the driver from the -Y/front side, fit the clamp ring, and tighten F04 in two diagonal passes to 0.35 N m; never exceed 0.45 N m.
- Pass: Ring bottoms evenly; G02 is continuous all the way round and covers all four unused driver mounting holes; cone moves outward on a brief 1.5 V positive polarity pulse.
- Warning: Use only a brief low-voltage polarity pulse. Never connect a loose driver to the powered HAT.

Step 3 - Wire and clamp the active driver

# Step 4: Mass-match and clamp both passive radiators

- Parts: 2 passive radiators, 2 passive_radiator_gaskets, 2 clamp rings, matched tuning masses
- Fasteners: F05, 8 screws total
- Tools: 0.01 g scale; 2.0 mm hex
- Gasket/seal: G03, one per side
- Action: Trim and weigh two identical tuning masses to the value in reports/acoustics/summary.json, matching them within 0.02 g. Apply one centred on each radiator mass post. Install radiators on +/-X with matching orientation, then tighten each F05 crosswise to 0.35 N m; never exceed 0.45 N m.
- Pass: Added masses match within 0.02 g; both rings bottom evenly; surrounds move freely and do not touch the shell keep-out.
- Warning: Unequal mass defeats reaction-force cancellation. Do not press on either cone.

Step 4 - Mass-match and clamp both passive radiators

# Step 5: Route the cable, close the divider, and leak-check

- Parts: pressure_divider, divider_gasket, leak_test_adapter, cable_gland
- Fasteners: F03, 8 screws
- Tools: 2.0 mm hex; hand bulb; 0-500 Pa gauge; leak-detection solution
- Gasket/seal: G01; temporary adapter then G04
- Action: Pass both conductors through the divider. Fit the temporary adapter over them, place G01 without twists, and tighten F03 in a star pattern to 0.35 N m. Apply only 100-250 Pa with a hand bulb. Brush leak solution on external gasket seams; no bubbles are allowed. Vent, pull the adapter upward, and install G04 with its flange toward the electronics bay.
- Pass: No growing bubbles, abnormal diaphragm displacement, or audible leak; final gland cannot rotate or lift by finger force.
- Warning: Never use shop air, never exceed 250 Pa, and keep liquid away from electronics. This is a gross-leak screen, not an acoustic-Q measurement.

Step 5 - Route the cable, close the divider, and leak-check

# Step 6: Install the base and retained ballast

- Parts: base_skirt, ballast_cartridge, 2 steel plates, ballast lid, bottom_service_plate
- Fasteners: F06, F07, F08
- Tools: 2.0 mm hex; scale
- Gasket/seal: none
- Action: Attach the base skirt with F07. Place both deburred dry plates flat in the cartridge; there must be no rocking. Install the lid with F06, insert the cartridge from below, and capture it with the bottom service plate using F08.
- Pass: Cartridge mass matches the steel stack listed in BOM.csv; no plate moves when shaken gently; all four lid screws engage at least 3 mm.
- Warning: The steel stack is heavy. Keep fingers clear and do not operate the unit without the retained lid and service plate.

Step 6 - Install the base and retained ballast

# Step 7: Stack the three outer skin segments

- Parts: shell_base, shell_grille, shell_crown; lower assembly
- Fasteners: F09, 4 screws with nylon washers; F02, 4 screws into the divider
- Tools: 2.0 mm hex
- Gasket/seal: none
- Action: Work bottom to top. Slide shell_base up over the cabinet with FRONT at -Y, invert on a soft mat, and install F09 through the bottom service plate into its four bosses. Stand the unit back up. Press shell_grille down onto the exposed lap until its outer face meets the segment below; the four crush ribs give a firm, even resistance and the joint closes on 0.15 mm of interference, so it should need hand pressure and stay put. Press shell_crown on the same way, then bolt it down onto the divider's four bosses with F02. Check that all three grille windows line up with the driver and both radiators.
- Pass: Both seams show an even hairline shadow line all round with no step you can catch a fingernail on; no segment rocks or rattles when the body is tapped; at least 2 mm clearance from every clamp ring and surround; no wire visible through a window.
- Warning: Do not force a segment on if it binds — lift it off and check for a stringing artefact on the lap or a crush rib that printed proud. Never flex a segment over an obstruction. The crown must be bolted to the divider before the official stack goes on, because its tabs sit underneath.

Step 7 - Stack the three outer skin segments

# Step 8: Fit the mic isolators and the official Batch 1 upper stack

- Parts: mic_isolation_bushing x4; O01-O06 official prints; Batch 1 HAT/Core
- Fasteners: F01 (M3 x d4 shoulder screws, 16 mm shoulder), F10, F11; 4 of each
- Tools: 2.0 mm hex; ESD-safe bench
- Gasket/seal: none; electronics bay is outside the acoustic chamber
- Action: Press one TPU isolation bushing into each of the four divider counterbores, flange up. Seat O01 on the four bushing flanges — it must rest on elastomer, not on printed plastic. Install F01 and tighten until each shoulder bottoms firmly on the counterbore floor; the screw head then stops 0.3 mm above the plate and the plate stays floating on the TPU. Snap O06 into O05 (or use both O07/O08 during a multi-material O05 print; never install O06 and O08 together). Align O03's taller standoffs with the I/O side and locate the HAT. Install the Core/HAT using the official Batch 1 sequence. Align the logos and I/O on O04/O05, engage the snaps, and rotate the lock ring. Align O02's four nubs with O01 and keep I/O toward rear/+Y. Connect the keyed JST-XH speaker plug before closure.
- Pass: The official top sits flush with the surrounding flat top — you should feel a hairline, not a step or a lip. The upper stack has a barely perceptible give when pressed, which is the isolation working. USB-C remains reachable; cable has service slack and cannot enter a moving-part envelope; buttons click and diffuser/LED apertures remain clear.
- Warning: F01 must be M3 x d4 shoulder screws, not ordinary M3 screws. An ordinary screw clamps in parallel with the elastomer at roughly 35 times its stiffness, so the TPU carries under 3% of the load path and the isolation does nothing at all. If the plate feels rock solid, you have the wrong screws. Core placement is REQUIRES_PHYSICAL_VALIDATION: follow the official Batch 1 instructions and stop at any collision.

Step 8 - Fit the mic isolators and the official Batch 1 upper stack

# Step 9: Fit the anti-slip ring and complete inspection

- Parts: anti_slip_ring; complete assembly
- Fasteners: none
- Tools: hands; flashlight
- Gasket/seal: inspect G01-G04
- Action: Stretch the TPU ring evenly around the bottom rim. Set the unit upright and inspect all seams, fastener heads, slots, cable exits, buttons, and moving components.
- Pass: Unit stands without rocking; no rattle is heard during gentle handling; every fastener is present and every seal is continuously compressed.
- Warning: Do not power the unit until the commissioning checklist is ready.

Step 9 - Fit the anti-slip ring and complete inspection

Source commit 508add3e53b5. No physical validation has been performed.

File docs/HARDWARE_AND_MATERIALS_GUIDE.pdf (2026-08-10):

Satellite1 Ultra RC1 — DIGITAL_PROTOTYPE_READY | Page 1

# Hardware and Materials Guide

Use Batch 1 only. The public Batch 1 pair is Core rev4.1 plus HAT rev4.1 / R2024.12.06. If the board or packaging says Satellite1.1, rev5.1 Core, rev6.1 HAT, or requires an external Wi-Fi antenna, stop: that hardware is unsupported.

ID | Category | Item | Exact specification | Qty | Required | Where to buy (US)
A01 | active driver | Dayton Audio ND91-4 | 4 ohm full-range driver; manufacturer model ND91-4 | 1 | yes | https://www.parts-express.com/Da yton-Audio-ND91 -4-3-1-2-Aluminu m-Cone-Full-Ran ge-Driver-4-290-224
A02 | passive radiator | Dayton Audio DSA115-PR | 4 inch passive radiator with M5 mass post | 2 | yes | https://www.parts-express.com/Da yton-Audio-DSA1 15-PR-4-Designe r-Series-Aluminu m-Cone-Passive-Radiator-295-544
E01 | official electronics | FutureProofHom es Satellite1 Batch 1 development kit | Core rev4.1 + HAT rev4.1 / R2024.12.06; not Satellite1.1 | 1 | yes | https://futureproofhomes.net/products/satellite1-kit
H01 | insert | CNC Kitchen M3 x 5.7 heat-set insert | M3x0.5 internal thread, 5.7 mm length, 4.6 mm maximum OD | 48 | yes; includes four spares | https://www.amazon.com/s?k=CN C+Kitchen+M3+h eat+set+insert+M 3x5.7
H02 | speaker cable | 2-pin JST-XH 2.54 mm speaker lead | 22 AWG stranded red/black, each insulated conductor OD <=1.8 mm, 350 mm minimum | 1 | yes | https://www.amazon.com/s?k=JS T-XH+2.54mm+2 +pin+speaker+pi gtail

ID | Category | Item | Exact specification
Qty | Required | Where to buy
(US)
H03 | speaker terminals | solder the leads directly to the driver's terminal lugs | The ND91-4 ships with flat solder lugs, each pierced by an oblong hole: thread the conductor through, crimp it closed, then flow solder, so the joint is mechanically captive rather than relying on solder for strength. Dress the wire toward the driver axis, never outward, and heat-shrink each joint. Radial bulk here is the binding constraint: the terminals are the widest thing that must pass the 76.65 mm bore, they clear it only through the notch, and the leads have to be attached before the driver goes in because the chamber is sealed after.
2 joints | recommended | https://www.ama zon.com/s?k=3m m+heat+shrink+t ubing+assortmen t
H04 | speaker terminals

2.8 mm fully
insulated female
quick-disconnect
s

Alternative to
H03, and the
weaker one. A
disconnect body
plus its sleeve
stands 2 to 3 mm
proud of the lug
on the side that
has the least
room, and it is a
rattle source
inside a sealed
chamber. It also
buys nothing:
reaching this joint
means pulling
the driver
anyway. If used,
verify the blade
width against the
lug first,
measured across
the flat face and
not along it, and
confirm the fit on
the speaker-fit
coupon before
committing to the
cabinet print.
2 | optional | https://www.ama zon.com/s?k=2.8 mm+fully+insulat ed+female+quick +disconnect

B01 | ballast | mild-steel plate | 100 x 92 x 6 mm, edges deburred, dry, light oil removed | 2 | yes | https://www.onlinemetals.com/en/buy/steel/0-25-mi ld-steel-plate-a36 -hot-rolled/pid/11 56
B02 | radiator tuning | M5 washers plus self-adhesive lead-free strip for final trim | 8.00 g per radiator, the two sets matched within 0.02 g, applied centred on the M5 mass post. Stack M5 washers for the bulk -- about 13 of them at roughly 0.6 g each -- then trim self-adhesive lead-free strip for the last fraction of a gram. Weigh both radiators' finished stacks and match them, rather than trusting counts | 2 matched sets | yes; final mass requires physical tuning | https://www.amazon.com/s?k=M5 +flat+washer+sta inless+assortme nt
G00 | gasket stock | closed-cell EPDM foam sheet | 2.0 mm nominal, soft, smooth skin, ASTM D1056 2A1 or equivalent | one 300 x 300 mm sheet | yes | https://www.amazon.com/s?k=2m m+closed+cell+E PDM+foam+shee t+adhesive
D01 | optional acoustic material | polyester acoustic batting | not installed in RC1; reserve for measurement-led development only | 0 | no | https://www.parts-express.com/search?keywords=acoustic%20polyf ill
O01 | official printed part | official_mid_plate | ASA (PETG alternative); exact file OFFICI AL_PARTS/REQ UIRED_SINGLE _MATERIAL/offic ial_mid_plate.stl; preserved official STL | 1 | yes | printed by you
O02 | official printed part | official_mid_plate _threads | ASA (PETG alternative); exact file OFFICI AL_PARTS/REQ UIRED_SINGLE _MATERIAL/offic ial_mid_plate_thr eads.stl; preserved official STL | 1 | yes | printed by you
O03 | official printed part | official_pcb_spac er | ASA (PETG alternative); exact file OFFICI AL_PARTS/REQ UIRED_SINGLE _MATERIAL/offic ial_pcb_spacer.st l; preserved official STL | 1 | yes | printed by you

O04 | official printed part | official_lock_ring | ASA (PETG alternative); exact file OFFICI AL_PARTS/REQ UIRED_SINGLE _MATERIAL/offic ial_lock_ring.stl; preserved official STL | 1 | yes | printed by you
O05 | official printed part | official_top_plate | ASA (PETG alternative); exact file OFFICI AL_PARTS/REQ UIRED_SINGLE _MATERIAL/offic ial_top_plate.stl; preserved official STL | 1 | yes | printed by you
O06 | official printed part | official_top_plate _snap_in_diffuse r_ring | ASA (PETG alternative); exact file OFFICI AL_PARTS/REQ UIRED_SINGLE _MATERIAL/offic ial_top_plate_sn ap_in_diffuser_ri ng.stl; preserved official STL | 1 | yes | printed by you
O07 | official printed part | official_top_plate _mm_buttons | ASA (PETG alternative); exact file OFFICI AL_PARTS/OPTI ONAL_MULTI_M ATERIAL/official _top_plate_mm_ buttons.stl; preserved official STL | 1 | optional alternative | printed by you
O08 | official printed part | official_top_plate _mm_diffuser_rin g | ASA (PETG alternative); exact file OFFICI AL_PARTS/OPTI ONAL_MULTI_M ATERIAL/official _top_plate_mm_ diffuser_ring.stl; preserved official STL | 1 | optional alternative | printed by you
F01 | fastener | M3 x 16 shoulder screw | M3 x d4 shoulder screw, A2-70 stainless, M3x0.5 | 4 | yes | https://www.mcmaster.com/screws/socket-head-screws/thread-size~m3/
F02 | fastener | M3 x 8 button head screw | ISO 7380-1, A2-70 stainless, M3x0.5 | 4 | yes | https://www.mcmaster.com/screws/socket-head-screws/thread-size~m3/
F03 | fastener | M3 x 8 socket cap screw | ISO 4762, A2-70 stainless, M3x0.5 | 8 | yes | https://www.mcmaster.com/screws/socket-head-screws/thread-size~m3/

F04 | fastener | M3 x 10 socket cap screw | ISO 4762, A2-70 stainless, M3x0.5 | 4 | yes | https://www.mcmaster.com/screws/socket-head-screws/thread-size~m3/
F05 | fastener | M3 x 10 socket cap screw | ISO 4762, A2-70 stainless, M3x0.5 | 8 | yes | https://www.mcmaster.com/screws/socket-head-screws/thread-size~m3/
F06 | fastener | M3 x 6 button head screw | ISO 7380-1, A2-70 stainless, M3x0.5 | 4 | yes | https://www.mcmaster.com/screws/socket-head-screws/thread-size~m3/
F07 | fastener | M3 x 10 socket cap screw | ISO 4762, A2-70 stainless, M3x0.5 | 4 | yes | https://www.mcmaster.com/screws/socket-head-screws/thread-size~m3/
F08 | fastener | M3 x 8 button head screw | ISO 7380-1, A2-70 stainless, M3x0.5 | 4 | yes | https://www.mcmaster.com/screws/socket-head-screws/thread-size~m3/
F09 | fastener | M3 x 8 button head screw | ISO 7380-1, A2-70 stainless, M3x0.5 | 4 | yes | https://www.mcmaster.com/screws/socket-head-screws/thread-size~m3/
F10 | fastener | M3 x 8 socket cap screw | ISO 4762, A2-70 stainless, M3x0.5 | 4 | yes | https://www.mcmaster.com/screws/socket-head-screws/thread-size~m3/
F11 | fastener | M3 x 8 socket cap screw | ISO 4762, A2-70 stainless, M3x0.5 | 4 | yes | https://www.mcmaster.com/screws/socket-head-screws/thread-size~m3/

All purchasing availability and prices must be checked by the builder. Manufacturer geometry and electrical parameters are DERIVED_FROM_MANUFACTURER_DRAWING; supplier availability is an ENGINEERING_ESTIMATE.

No structural glue is used. No damping material is installed in RC1. Gaskets are replaceable mechanically compressed EPDM, and the cable seal is TPU 95A.

Source commit 508add3e53b5. No physical validation has been performed.

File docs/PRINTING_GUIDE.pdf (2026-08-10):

Satellite1 Ultra RC1 — DIGITAL_PROTOTYPE_READY | Page 1

# Printing Guide

VERIFIED_DIGITALLY for part geometry, stored 3MF units, and bounding boxes. Actual print time, material use, shrinkage, warping, and airtightness are REQUIRES_PHYSICAL_VALIDATION.

# Complete-part warning

You must print both the custom Ultra parts and the official Squircle upper stack. The six mandatory official files are in OFFICIAL_PARTS/REQUIRED_SINGLE_MATERIAL/; they are included in the release and listed in the table below.

Do not print the official original speaker chamber, original speaker plate, or original anti-slip ring. main_cabinet.3mf, the Ultra driver/radiator hardware, base_skirt.3mf, and anti_slip_ring.3mf replace those parts.

O07 and O08 are optional multi-material inserts. If using them, load O05, O07, and O08 together in the slicer and omit O06. For an ordinary single-material printer, use O05 plus O06 and ignore the optional folder.

# Minimum printer volume

- Largest footprint: shell_base, 188.0 x 188.0 mm in its documented orientation.
- Tallest part: main_cabinet, 182.8 mm.
- Configured usable travel: 220 x 200 x 250 mm, leaving 32.0 mm and 12.0 mm of edge margin.
- These figures are computed from the released B-reps every time this guide is generated, and the printability gate enforces them per axis against both in-plane rotations. Set your own measured travel in config/default.yaml under printing.build_volume_*.
- Side printing is unsupported: it places support contact on cosmetic surfaces.

# Authoritative slicer baseline

- ASA primary; PETG alternative. Do not mix materials within a bolted joint.
- 0.4 mm nozzle; 0.20 mm layer; 0.45 mm line width.
- Five walls; six top and six bottom layers; 35% gyroid.
- ASA: 250-260 C nozzle, 100-110 C bed, enclosed printer, low part cooling, draft shield if chamber is below 40 C.
- PETG: 235-250 C nozzle, 75-85 C bed, moderate cooling after layer three.
- Supports: disabled. The horizontal acoustic openings are self-progressing circular overhangs; inspect their upper arcs and never place support on a gasket seat.
- Seam: rear (+Y) for cabinet/shell/shroud; away from all gasket lands.
- Elephant-foot compensation: set in the slicer from your coupon, not by sanding the part.

# Print order and exact orientation

Group | Filename | Qty | Material | Face/orienta tion | Supports | Brim | Difficulty | Calibration
cosmetic | anti_slip_rin g.3mf | 1 | TPU 95A | flat | none | none | 2/5 | yes
cosmetic | shell_base.3 mf | 1 | ASA | inverted, cut face on the bed | none | 3 mm | 2/5 | yes

Group | Filename | Qty | Material | Face/orienta tion | Supports | Brim | Difficulty | Calibration
cosmetic | shell_grille.3 mf | 1 | ASA | upright, lower cut face on bed | none | 3 mm | 2/5 | yes
cosmetic | shell_crown. 3mf | 1 | ASA | upright, flat top uppermost | none | 3 mm | 2/5 | yes
cosmetic | shell_base_f abric.3mf | 1 | ASA | inverted, cut face on the bed | none | 3 mm | 2/5 | yes
cosmetic | shell_grille_f abric.3mf | 1 | ASA | upright, lower cut face on bed | none | 3 mm | 2/5 | yes
cosmetic | shell_crown _fabric.3mf | 1 | ASA | upright, flat top uppermost | none | 3 mm | 2/5 | yes
structural | main_cabine t.3mf | 1 | ASA | upright, acoustic floor on bed | none | 10 mm | 4/5 | yes
structural | pressure_di vider.3mf | 1 | ASA | flat, acoustic face on bed | none | none | 2/5 | yes
structural | mic_isolatio n_bushing.3 mf | 4 | TPU 95A | flange face on bed | none | none | 2/5 | yes
structural | active_driver _clamp_ring .3mf | 1 | ASA | lip face on bed | none | none | 2/5 | yes
structural | passive_radi ator_clamp_ ring.3mf | 2 | ASA | lip face on bed | none | none | 2/5 | yes
calibration | cable_gland. 3mf | 1 | TPU 95A | body end on bed | none | 5 mm | 2/5 | first
service tool | leak_test_ad apter.3mf | 1 | TPU 95A | flange on bed; temporary service tool, not installed in service | none | none | 2/5 | yes
structural | base_skirt.3 mf | 1 | ASA | service opening on bed | none | none | 2/5 | yes
structural | bottom_serv ice_plate.3m f | 1 | ASA | exterior face on bed | none | none | 2/5 | yes
structural | ballast_cartri dge.3mf | 1 | ASA | tray floor on bed | none | none | 2/5 | yes
structural | ballast_cartri dge_lid.3mf | 1 | ASA | tongue face on bed | none | none | 2/5 | yes
calibration | coupon_offic ial_interface. 3mf | 1 | ASA | largest flat face on bed | none | 5 mm | 2/5 | first
calibration | coupon_acti ve_driver.3 mf | 1 | ASA | largest flat face on bed | none | 5 mm | 2/5 | first
calibration | coupon_pas sive_radiato r.3mf | 1 | ASA | largest flat face on bed | none | 5 mm | 2/5 | first
calibration | coupon_hea t_set_insert. 3mf | 1 | ASA | largest flat face on bed | none | 5 mm | 2/5 | first

Group | Filename | Qty | Material | Face/orienta tion | Supports | Brim | Difficulty | Calibration
calibration | coupon_gas ket_base.3 mf | 1 | ASA | largest flat face on bed | none | 5 mm | 2/5 | first
calibration | coupon_gas ket_cap.3mf | 1 | ASA | largest flat face on bed | none | 5 mm | 2/5 | first
calibration | coupon_cabl e_passage. 3mf | 1 | ASA | largest flat face on bed | none | 5 mm | 2/5 | first
official required | OFFICIAL_ PARTS/RE QUIRED_SI NGLE_MAT ERIAL/offici al_mid_plate .stl | 1 | ASA (PETG alternative) | lowest native-Z face on bed, as illustrated | none | none | 2/5 | after calibration
official required | OFFICIAL_ PARTS/RE QUIRED_SI NGLE_MAT ERIAL/offici al_mid_plate _threads.stl | 1 | ASA (PETG alternative) | lowest native-Z face on bed, as illustrated | none | none | 2/5 | after calibration
official required | OFFICIAL_ PARTS/RE QUIRED_SI NGLE_MAT ERIAL/offici al_pcb_spac er.stl | 1 | ASA (PETG alternative) | lowest native-Z face on bed, as illustrated | none | none | 2/5 | after calibration
official required | OFFICIAL_ PARTS/RE QUIRED_SI NGLE_MAT ERIAL/offici al_lock_ring. stl | 1 | ASA (PETG alternative) | lowest native-Z face on bed, as illustrated | none | none | 2/5 | after calibration
official required | OFFICIAL_ PARTS/RE QUIRED_SI NGLE_MAT ERIAL/offici al_top_plate .stl | 1 | ASA (PETG alternative) | lowest native-Z face on bed, as illustrated | none | none | 2/5 | after calibration
official required | OFFICIAL_ PARTS/RE QUIRED_SI NGLE_MAT ERIAL/offici al_top_plate _snap_in_dif fuser_ring.st l | 1 | ASA (PETG alternative) | lowest native-Z face on bed, as illustrated | none | none | 2/5 | after calibration

The 3MF files already store millimetres and the documented orientation.

# CAD-derived orientation sheets

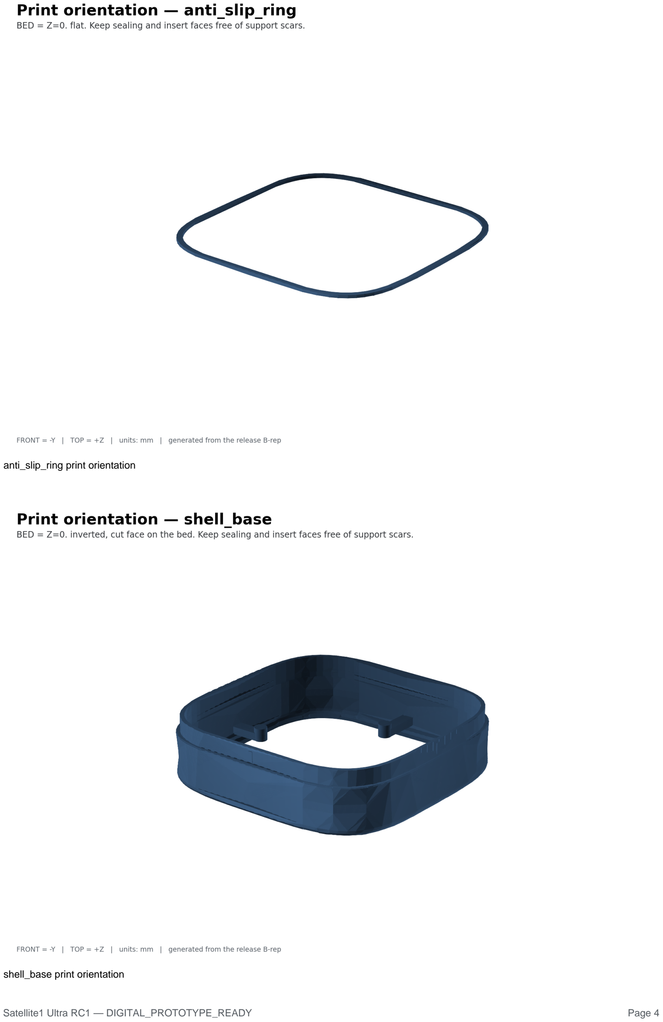
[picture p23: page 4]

anti_slip_ring print orientation

shell_base print orientation

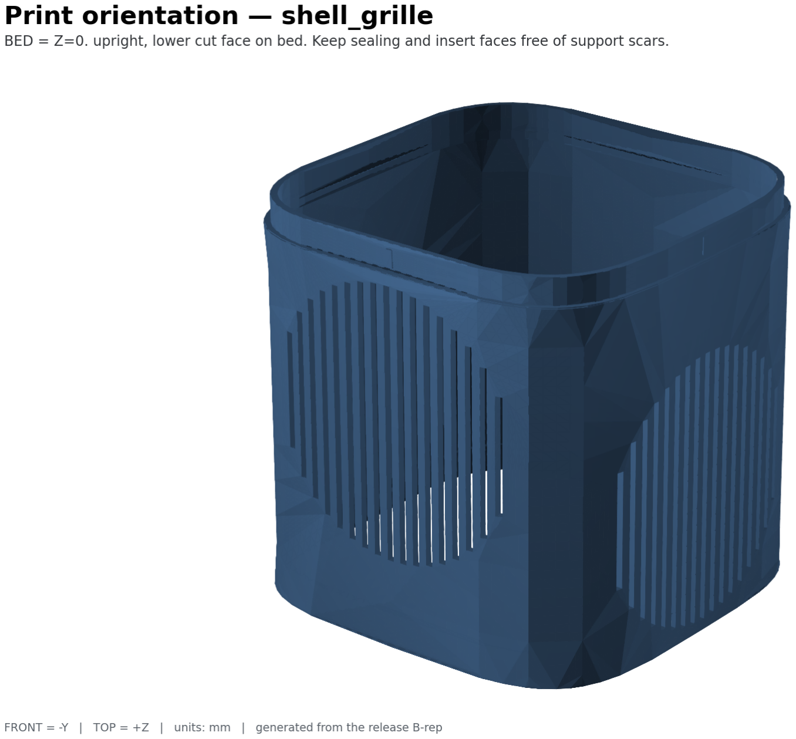
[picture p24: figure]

shell_grille print orientation

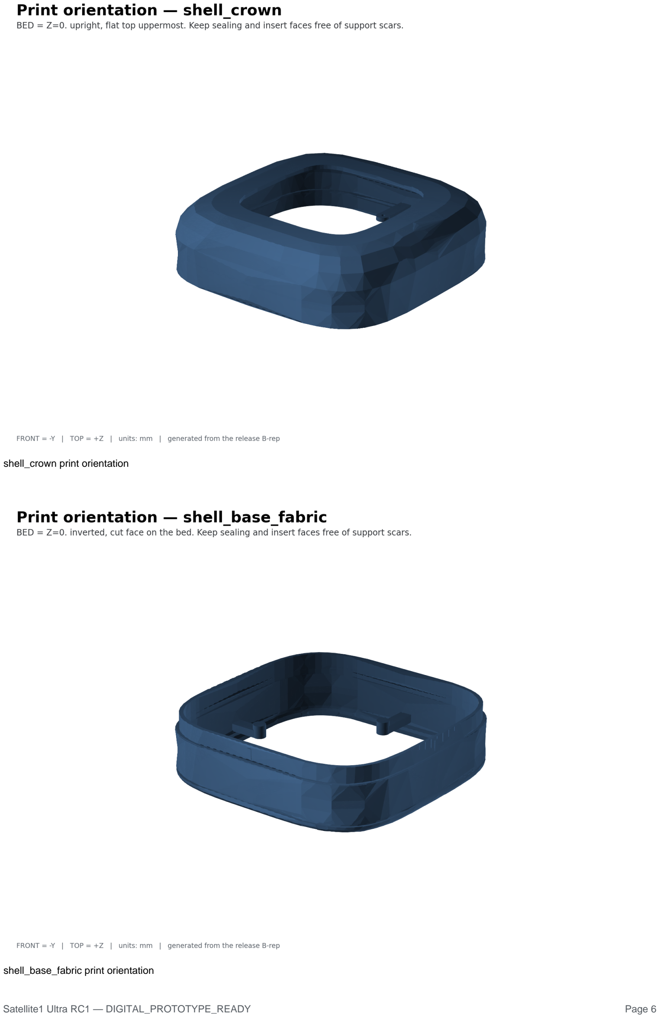
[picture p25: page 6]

shell_crown print orientation

shell_base_fabric print orientation

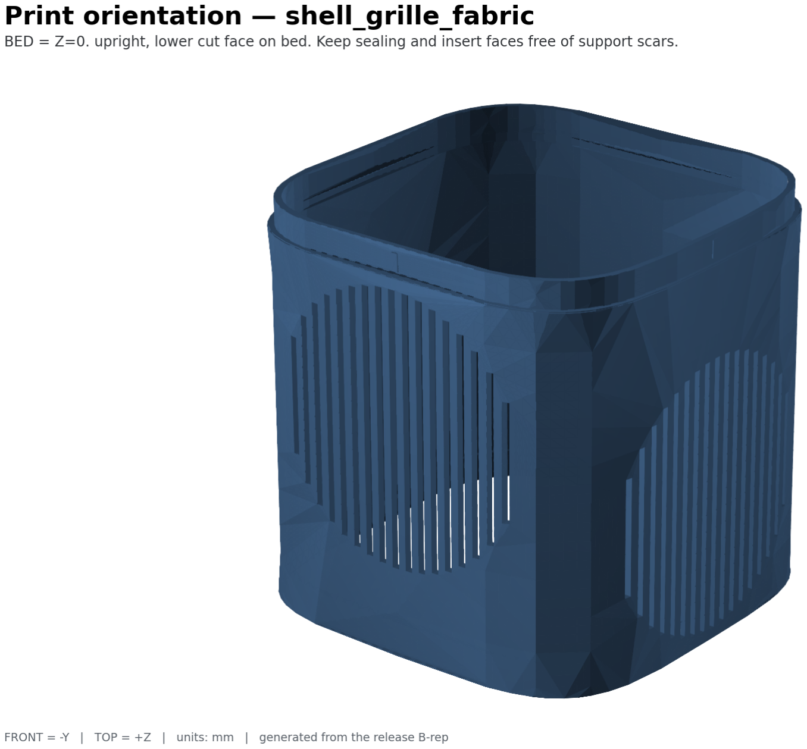
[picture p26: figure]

shell_grille_fabric print orientation

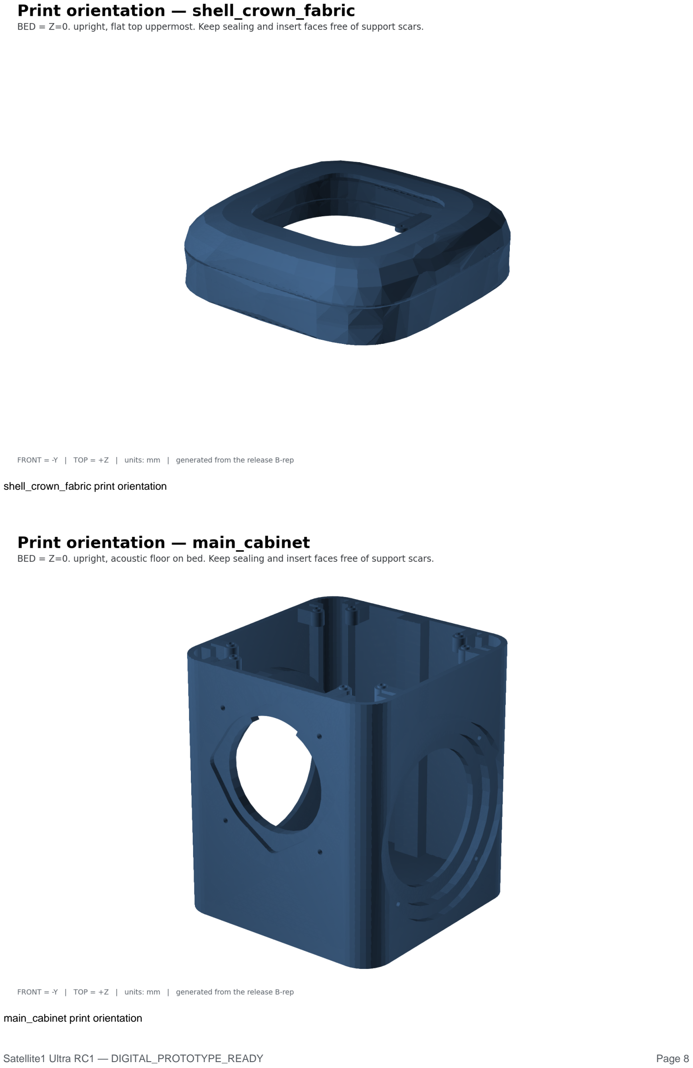
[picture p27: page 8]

shell_crown_fabric print orientation

main_cabinet print orientation

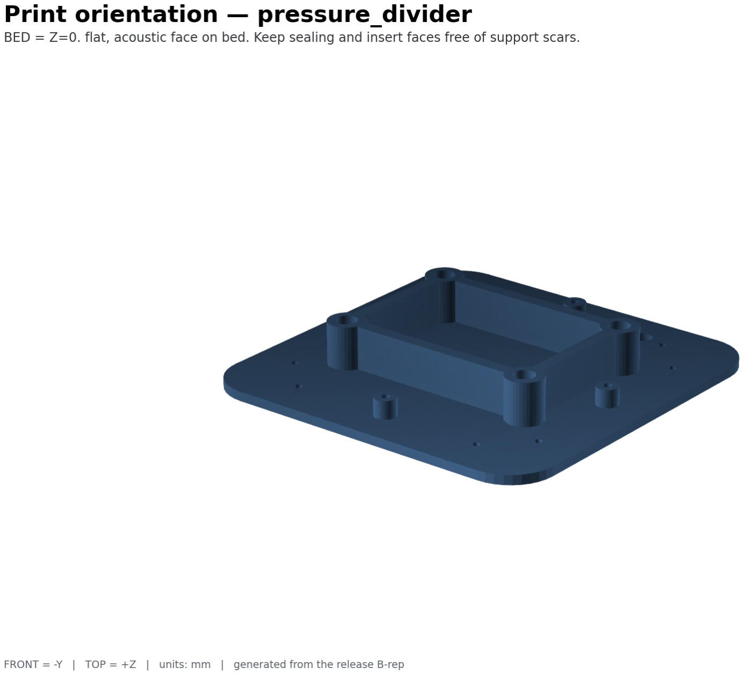
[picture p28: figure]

pressure_divider print orientation

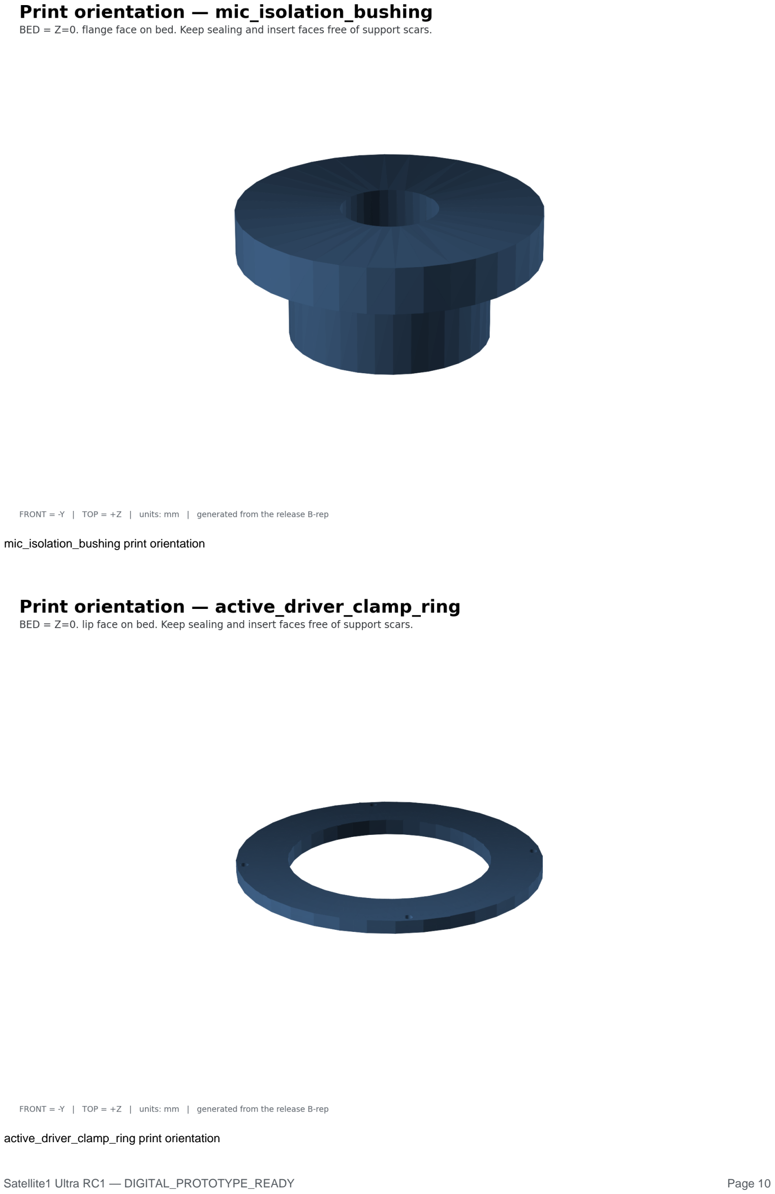
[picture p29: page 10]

mic_isolation_bushing print orientation

active_driver_clamp_ring print orientation

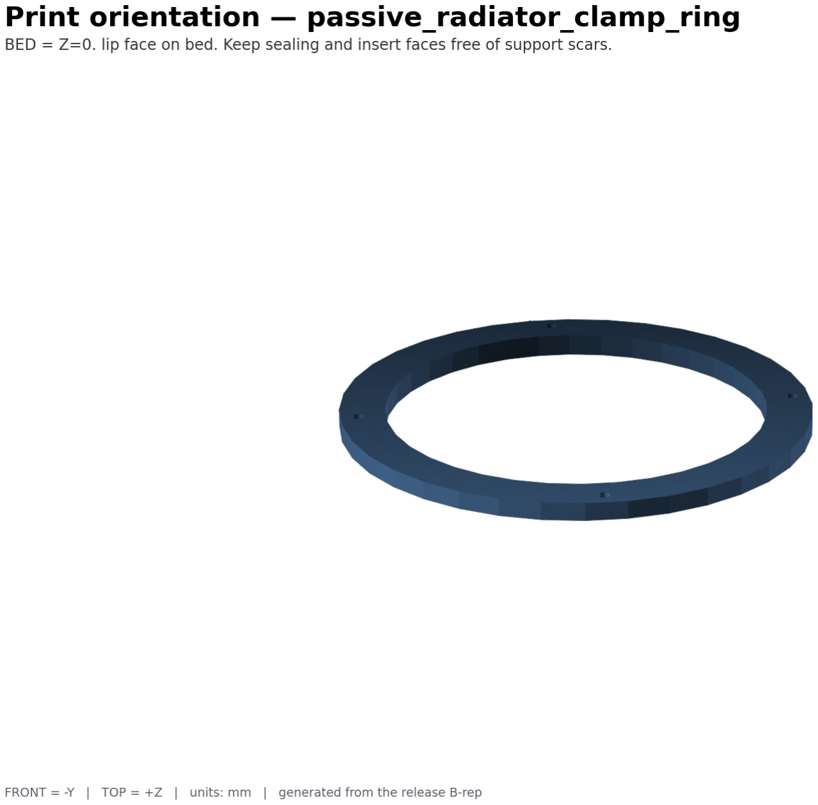
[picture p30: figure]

passive_radiator_clamp_ring print orientation

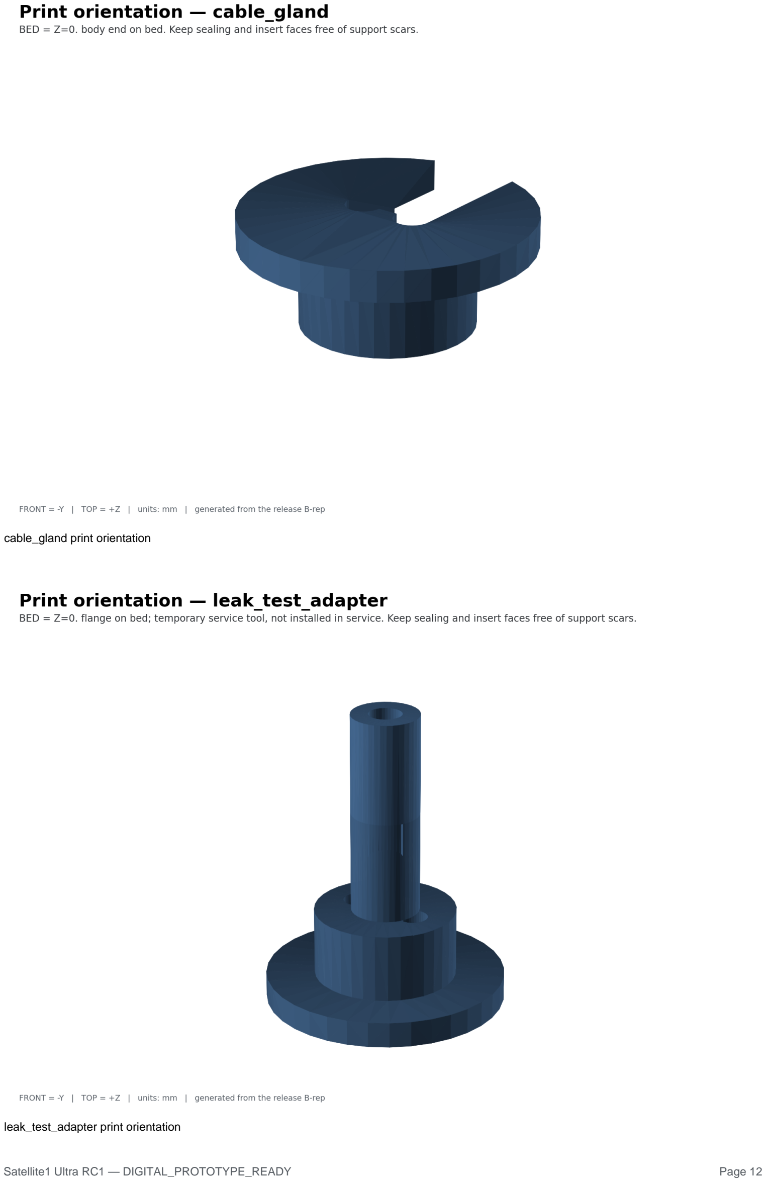
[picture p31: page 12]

cable_gland print orientation

leak_test_adapter print orientation

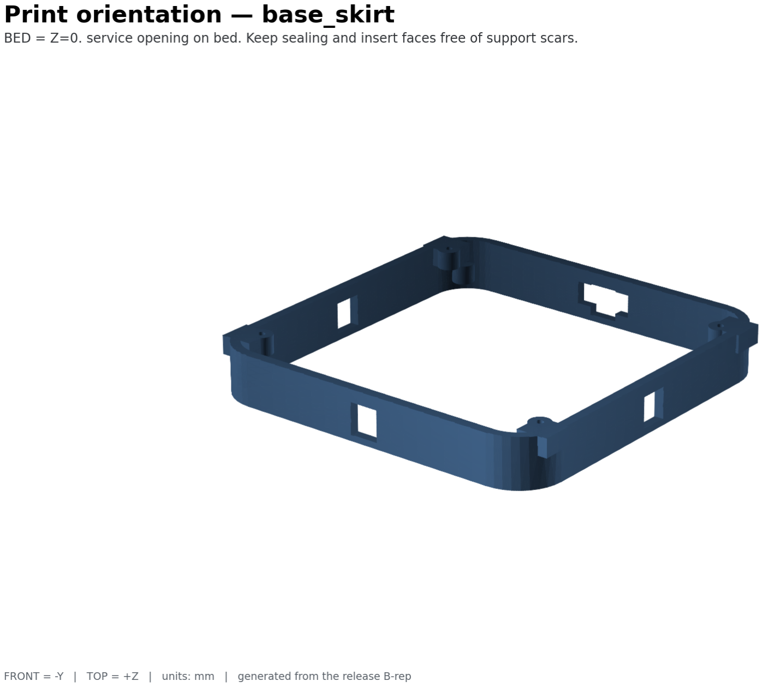
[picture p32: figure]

base_skirt print orientation

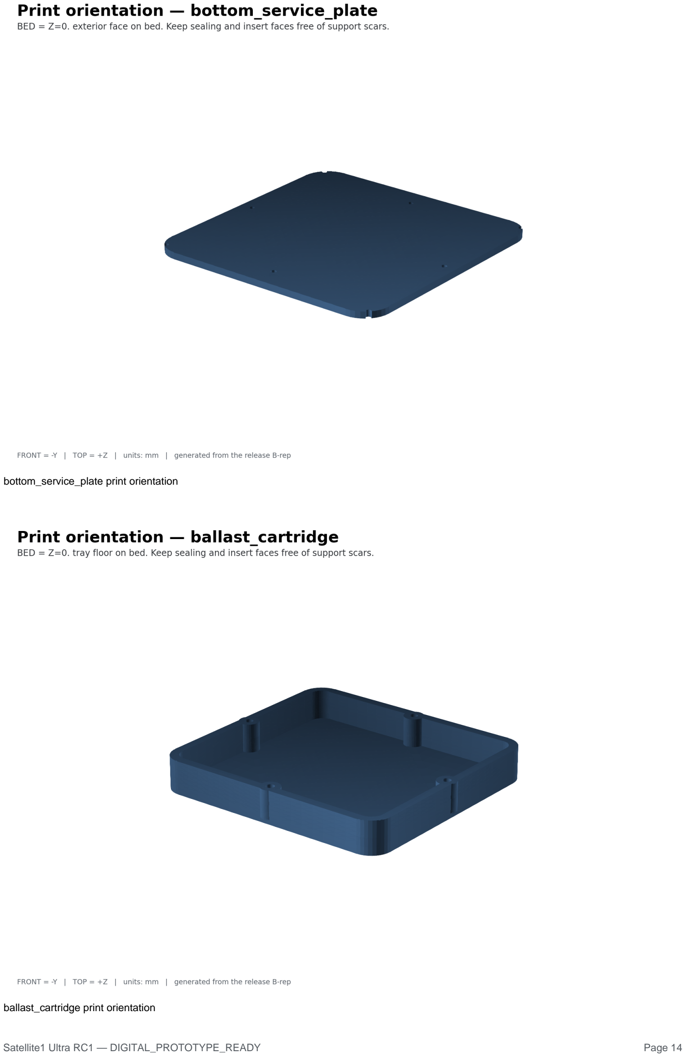
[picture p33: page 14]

bottom_service_plate print orientation

ballast_cartridge print orientation

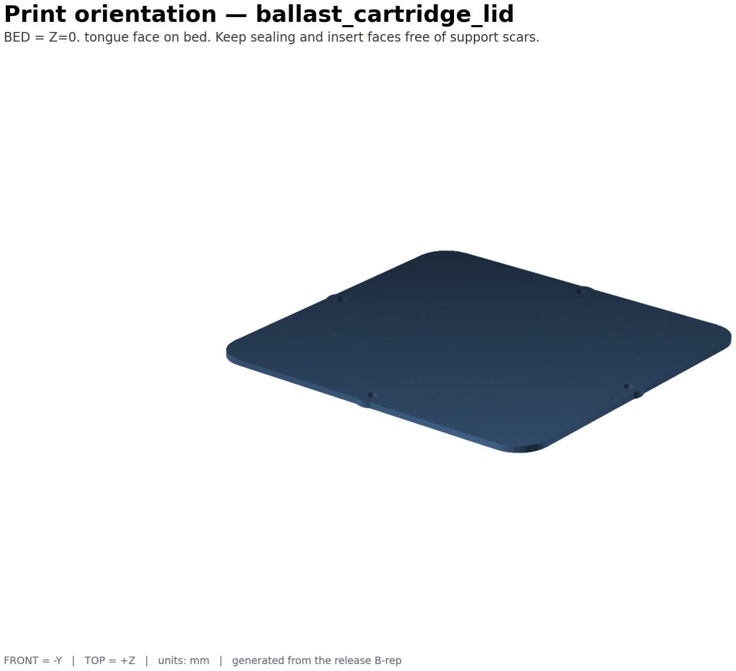
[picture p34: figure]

ballast_cartridge_lid print orientation

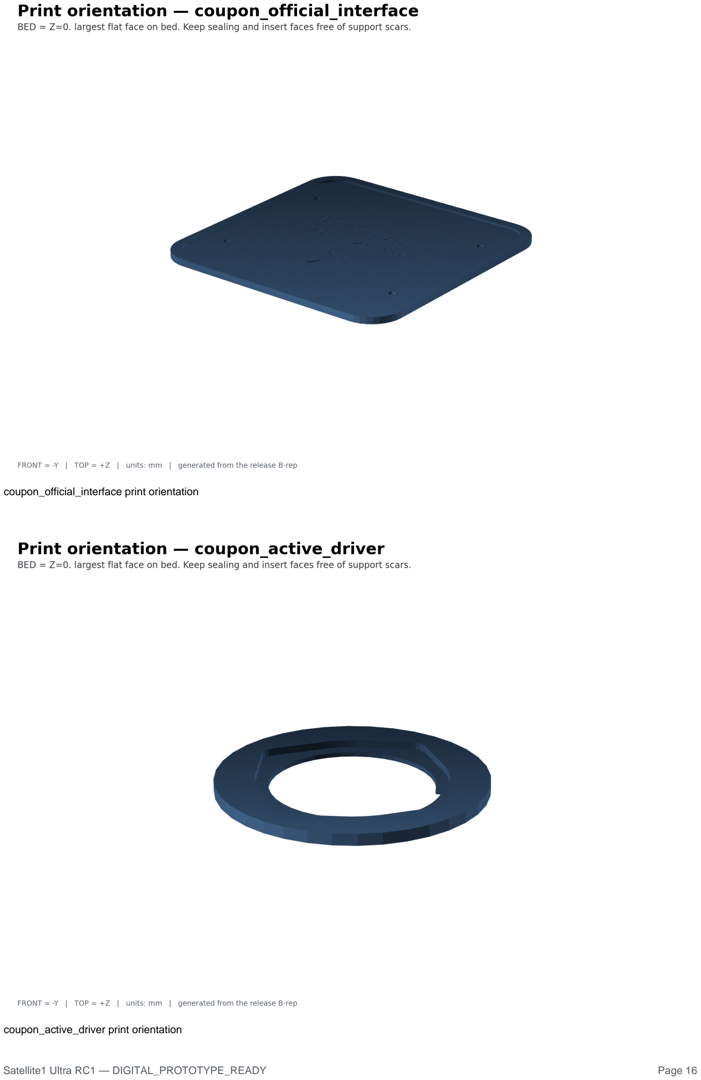
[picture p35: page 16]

coupon_official_interface print orientation

coupon_active_driver print orientation

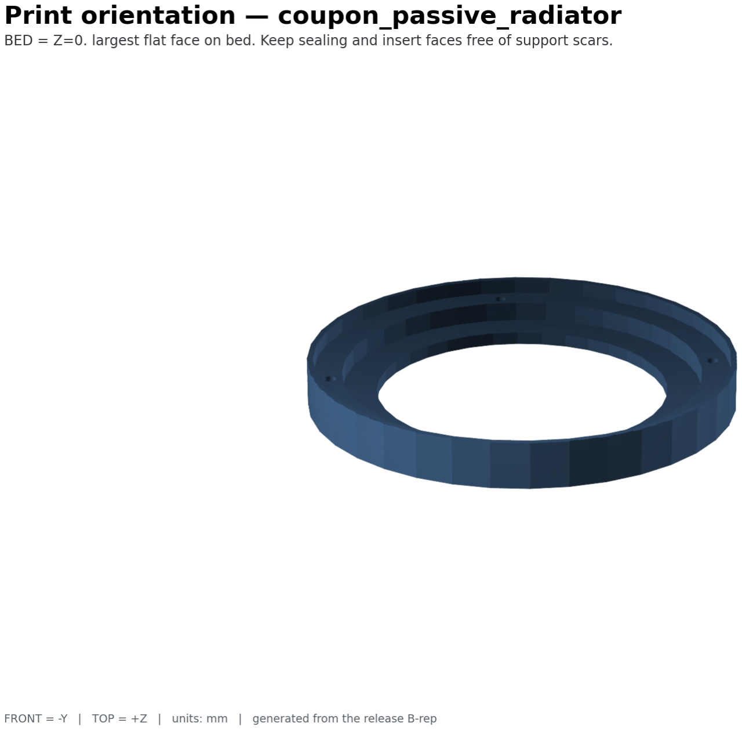
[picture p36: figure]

coupon_passive_radiator print orientation

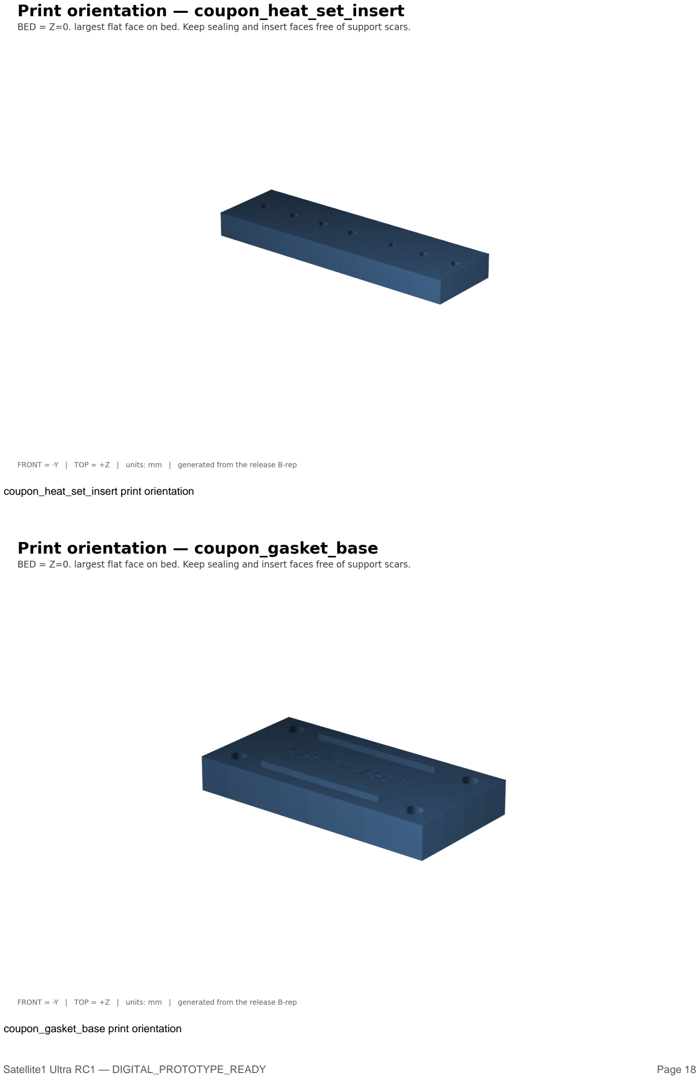
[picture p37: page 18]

coupon_heat_set_insert print orientation

coupon_gasket_base print orientation

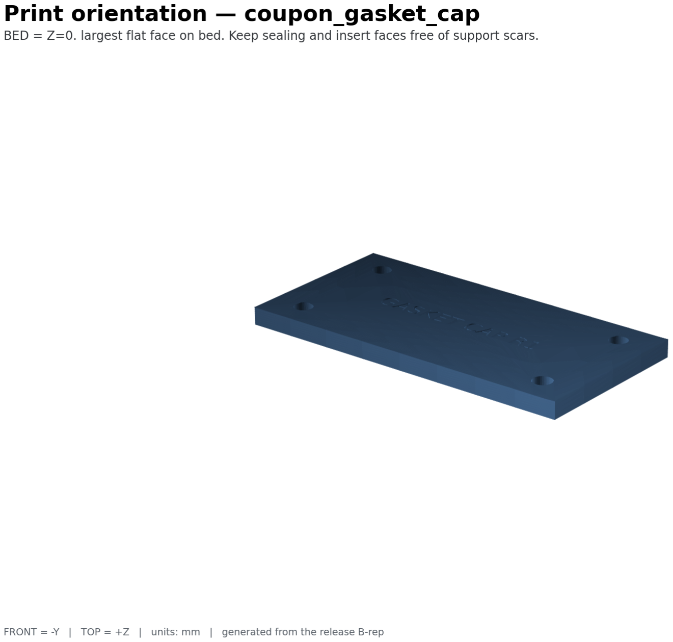
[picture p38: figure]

coupon_gasket_cap print orientation

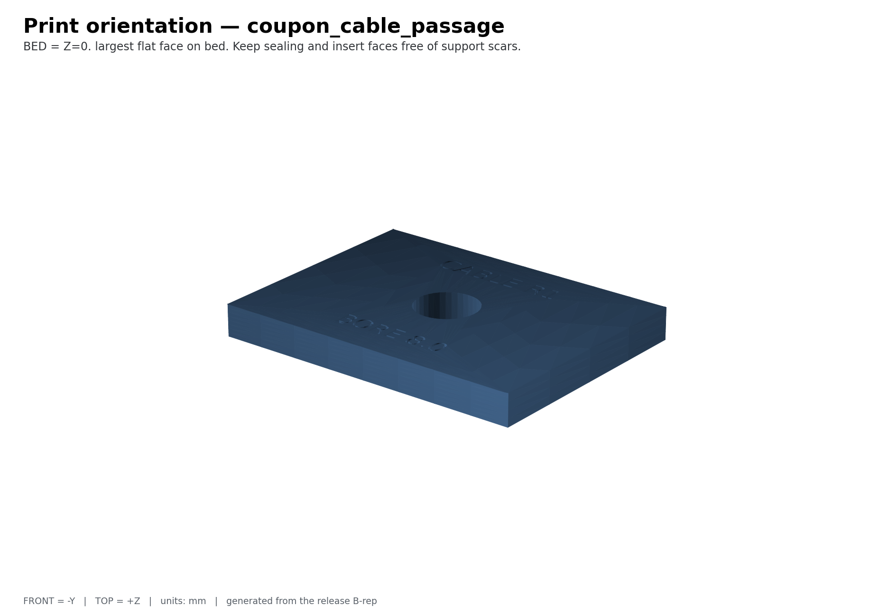
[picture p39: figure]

coupon_cable_passage print orientation

# Official Squircle orientation sheets

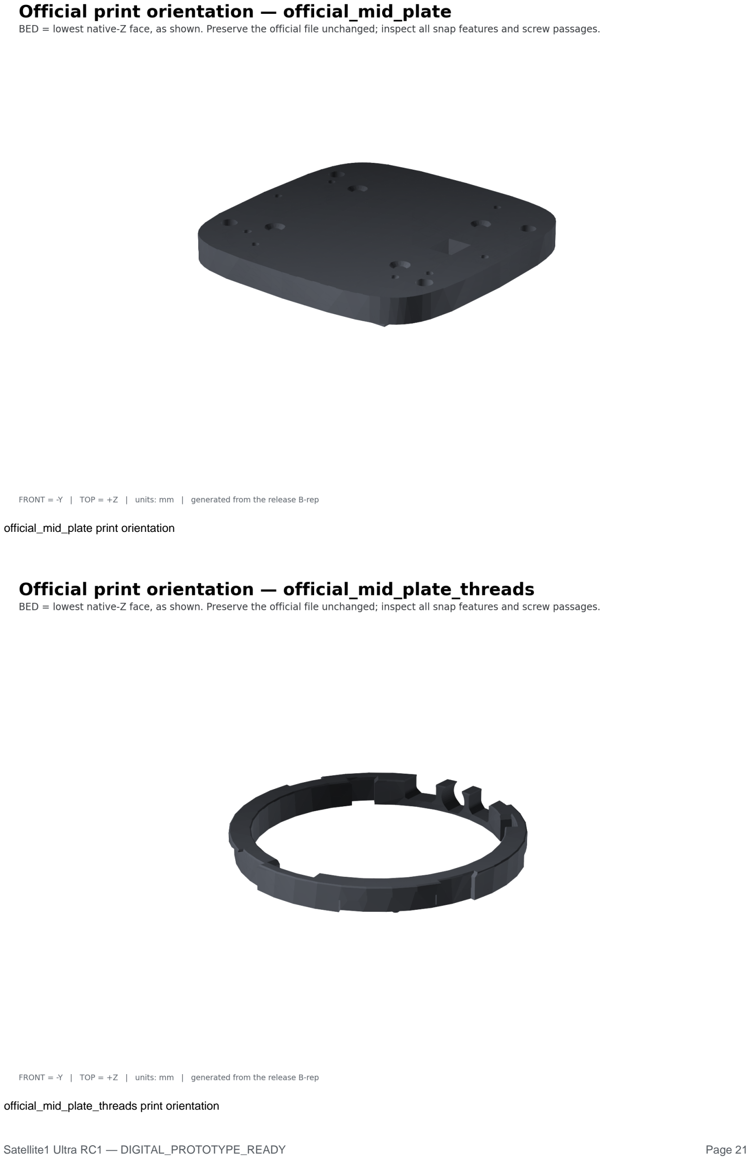
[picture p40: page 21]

official_mid_plate print orientation

official_mid_plate_threads print orientation

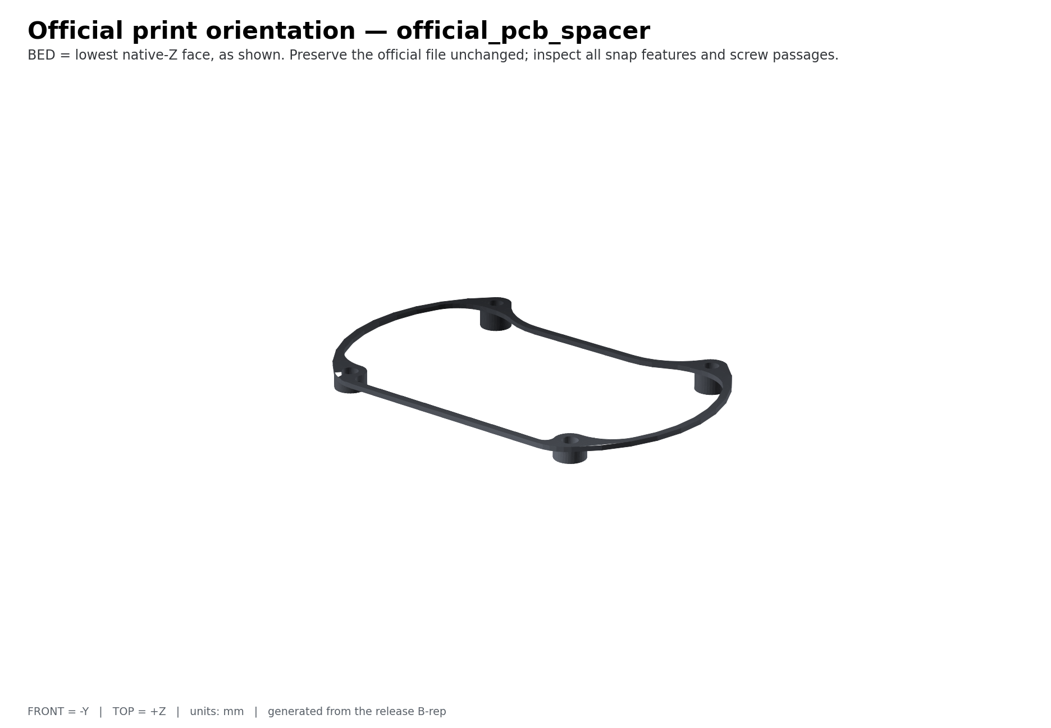
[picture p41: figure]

official_pcb_spacer print orientation

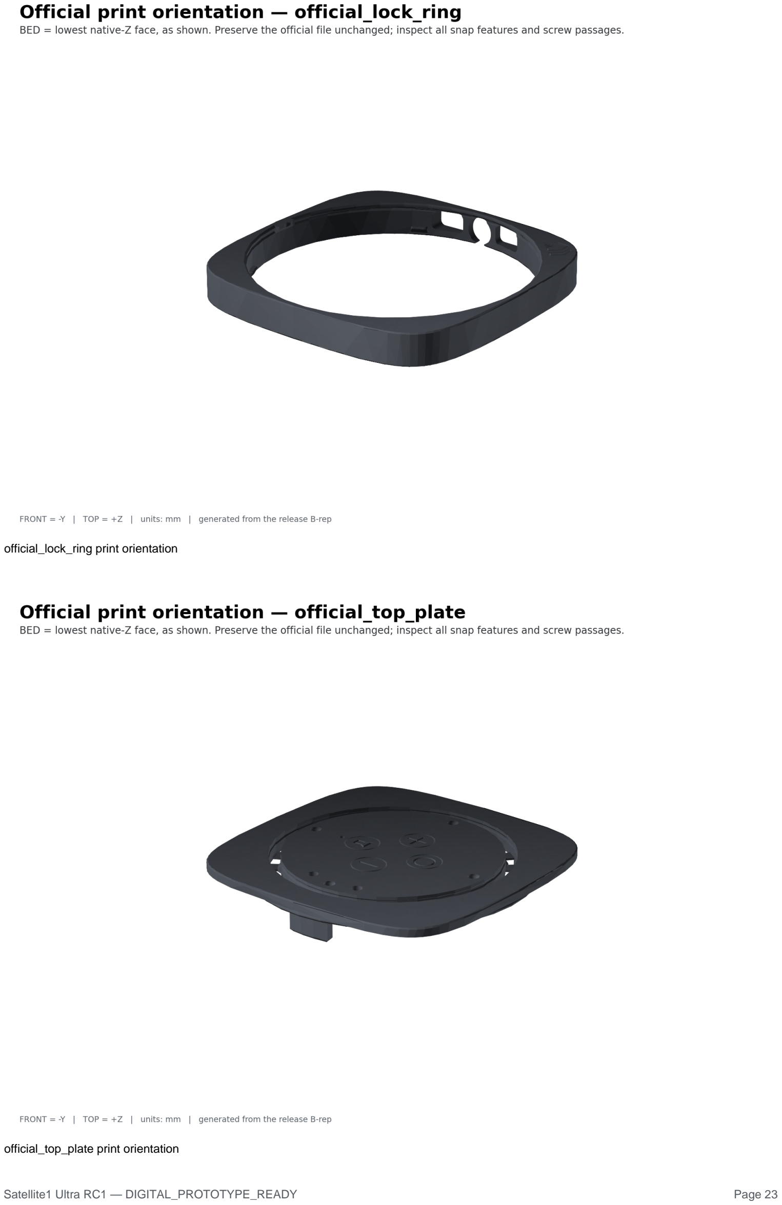
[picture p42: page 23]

official_lock_ring print orientation

official_top_plate print orientation

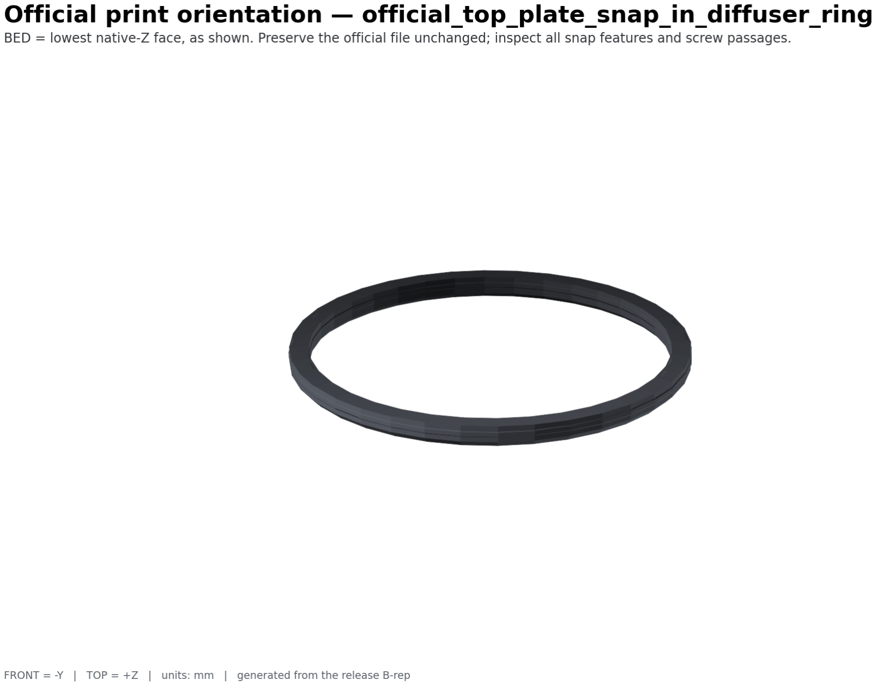
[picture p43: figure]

official_top_plate_snap_in_diffuser_ring print orientation

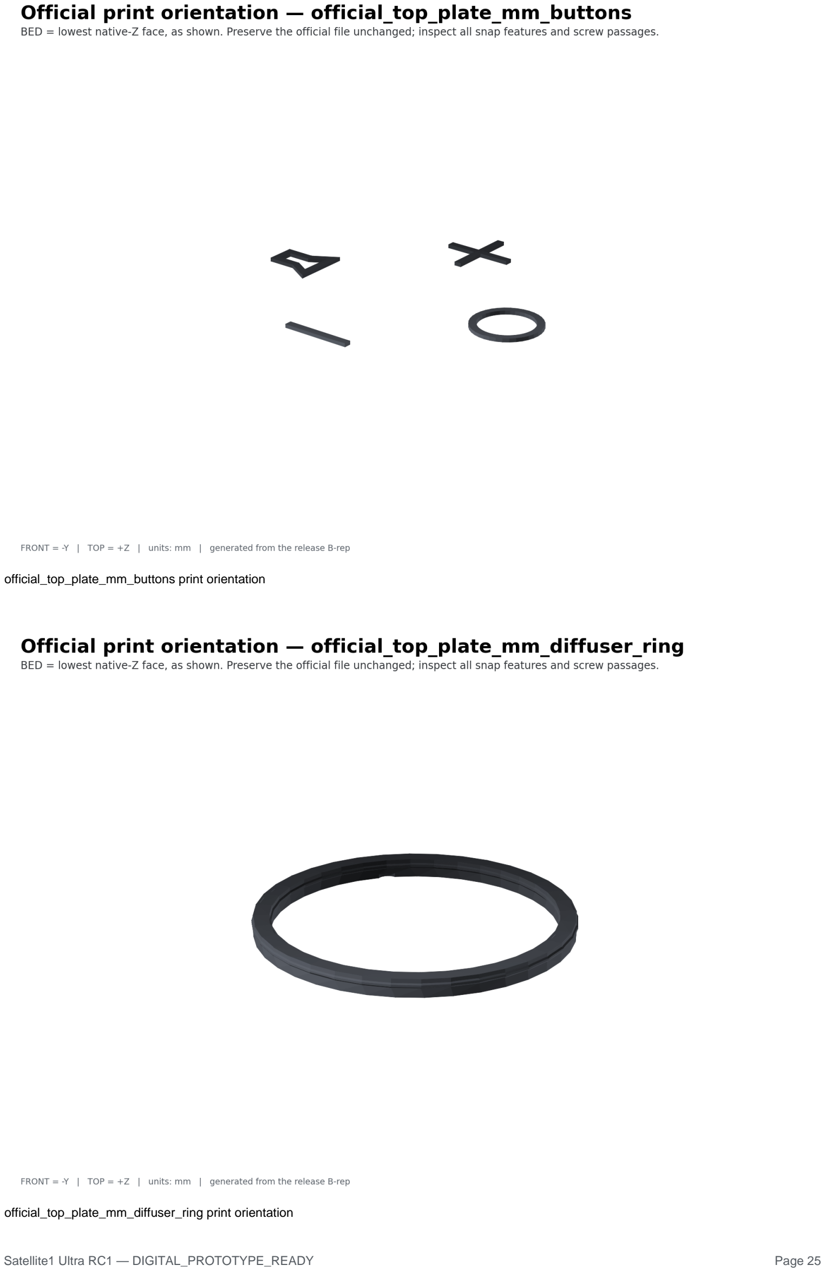
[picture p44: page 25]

official_top_plate_mm_buttons print orientation

official_top_plate_mm_diffuser_ring print orientation

# Inspection before continuing

- Cabinet and divider: continuous, glossy-enough gasket lands; no seam gap, crack, under-extrusion, or insert bore opened into the chamber.
- Shell: all slots open, four retention bridges intact, no warp at either rim.
- Clamp rings: flat within 0.20 mm on a surface plate; lip clean and continuous.
- Ballast cartridge: lid holes align; both plates lie flat; four bosses sound.
- TPU parts: no tear, string in a wire bore, or layer split.

Approximate filament and time vary too much by slicer and machine to be verified digitally. Your slicer estimate is authoritative for planning; record it before starting each full-size print.

Source commit 508add3e53b5. No physical validation has been performed.

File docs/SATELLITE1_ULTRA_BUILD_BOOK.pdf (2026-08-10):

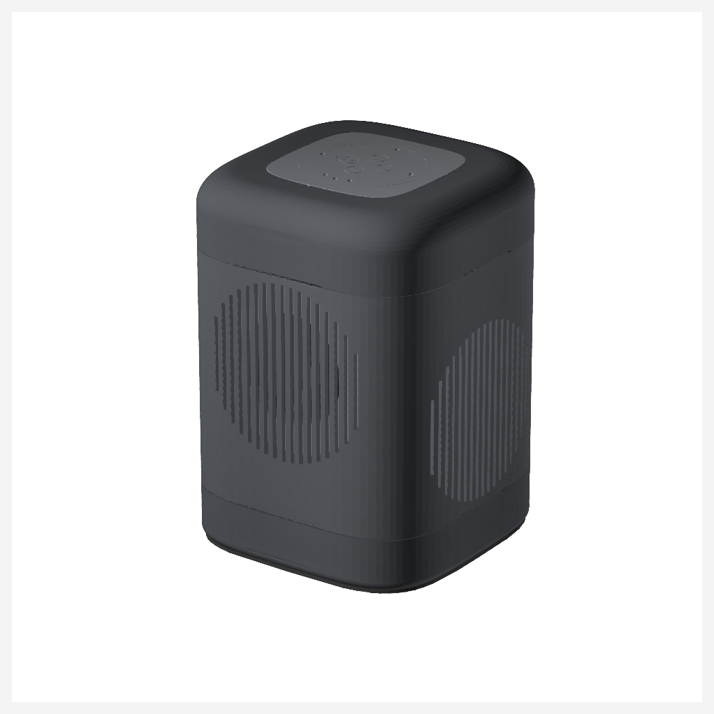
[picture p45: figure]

Satellite1 Ultra RC1 — DIGITAL_PROTOTYPE_READY | Page 1

# The Satellite1 Ultra Build Book

DO NOT PRINT THE FULL ENCLOSURE YET. PRINT AND MEASURE THE 8 SMALL CALIBRATION PIECES FIRST.

This is the only document you need to follow from start to finish. Work through the phases in order. Every other guide in this package is reference material that this book points you to at the moment you need it.

You are building a serviceable passive-radiator speaker enclosure around the FutureProofHomes Satellite1 Batch 1 development kit: Core rev4.1 and HAT rev4.1 / R2024.12.06. Satellite1.1 / Batch 2 does not fit and is not supported.

Expected difficulty is 4 out of 5. Nothing here is glued; every joint is a screw into a brass insert, so you can open the unit again later.

The finished Satellite1 Ultra, assembled

# The whole build at a glance

Phase | What you do | Roughly how long
1 | Check your printer and buy the parts | ordering time
2 | Print 8 small calibration pieces | 4-6 hours
3 | Measure them and correct the files | 1 hour
4 | Print 12 Ultra parts and 6 Satellite top parts | 3-5 days
5 | Cut 3 foam gaskets from the templates | 30 minutes
6 | Lay out and check every part | 30 minutes
7 | Assemble, in 9 numbered steps | 3-4 hours
8 | Test before you use it normally | 2 hours

# Status you should know before you start

Every gate in this repository is a digital check: geometry, clearances, volumes, exports, and documents. No physical unit has been built and measured. Fit, sealing, acoustic output, thermals, Wi-Fi, microphones, buttons, LEDs, and wake-word behaviour are all REQUIRES_PHYSICAL_VALIDATION. Your calibration, leak, and commissioning checks in phases 3 and 8 are part of the build, not optional extras.

# Phase 1 — Check your printer and buy the parts

# Your printer must actually fit the parts

The largest footprint belongs to shell_base at 188 x 188 mm. The tallest part is main_cabinet at 183 mm. Against the configured usable travel of 220 x 200 x 250 mm that leaves 32 mm and 12 mm of edge margin.

The outer skin is deliberately split into three stacked segments so no single print is enormous. That keeps every part comfortably inside a common bed and means a failed print costs you one segment, not the whole body.

- Purge lines, bed clips, and firmware exclusion zones all steal usable travel. Measure what your machine really reaches, then set printing.build_volume_x, _y and _z in config/default.yaml to what you measured. The printability gate reads those numbers and tests both in-plane rotations of every part, so it will actually fail if something does not fit.
- Printing a skin segment on its side is not supported: it puts support contact on the cosmetic surface.

You also need an enclosed printer, a 0.4 mm nozzle, and dry filament.

# Materials

- ASA for every rigid part. PETG is a documented alternative.
- TPU 95A for the two flexible parts: the cable seal and the bottom grip.
- PLA+ is only acceptable for a display mock-up, never a finished unit.

# Tools

Digital calipers reading 0.01 mm, a scale reading 0.01 g, a 2.0 mm hex driver, a temperature-controlled soldering iron with an M3 heat-set-insert tip, wire strippers and a crimper or soldering iron, ESD protection, a hand bulb with a 0-500 Pa gauge, and leak-detection solution.

# What to buy

Buy every item marked required in BOM.csv. The essentials are:

- One FutureProofHomes Satellite1 Batch 1 kit (E01).
- One Dayton Audio ND91-4 speaker (A01).
- Two Dayton Audio DSA115-PR passive radiators (A02).
- M3 heat-set inserts, with four spares (H01).
- Every M3 screw in FASTENERS.csv.
- One 300 x 300 mm sheet of 2.0 mm closed-cell EPDM foam (G00).
- Two mild-steel ballast plates (B01).
- Two matched sets of self-adhesive tuning mass for the radiators (B02).
- One 2-pin JST-XH speaker lead (H02).

HARDWARE_AND_MATERIALS_GUIDE.pdf gives the full specification for each line.

Do not print the official original speaker chamber, speaker plate, or anti-slip ring. The Ultra parts replace all three.

# Phase 2 — Print the 8 calibration pieces

These are small. They exist so you discover your printer's real dimensional behaviour before you spend days of filament on the big parts.

Open PRINT_THESE_FILES/1_CALIBRATION_FIRST and print every file, one at a time, using the exact settings you will use for the enclosure:

File | Print this many | Material
01_MEASURE_YOUR_PRINTER.3mf | 1 | ASA
02_CHECK_SCREWS_AND_INSERTS.3mf | 1 | ASA
03_CHECK_SPEAKER_FIT.3mf | 1 | ASA
04_CHECK_RADIATOR_FIT.3mf | 1 | ASA
05_GASKET_TEST_BASE.3mf | 1 | ASA
06_GASKET_TEST_TOP.3mf | 1 | ASA
07_CHECK_CABLE_HOLE.3mf | 1 | ASA
08_FLEXIBLE_CABLE_SEAL_TPU.3mf | 1 | TPU 95A

Baseline settings: 0.4 mm nozzle, 0.20 mm layers, five walls, six top and six bottom layers, 35% gyroid infill, no supports, 5 mm brim on the rigid pieces. ASA runs 250-260 C nozzle and 100-110 C bed with the enclosure closed. PETG runs 235-250 C nozzle and 75-85 C bed.

# Phase 3 — Measure the pieces and correct the files

This is the step that makes the big parts fit. CALIBRATION_GUIDE.pdf shows exactly where each caliper jaw goes; the images below name each check.

Where to measure the Satellite top fit piece

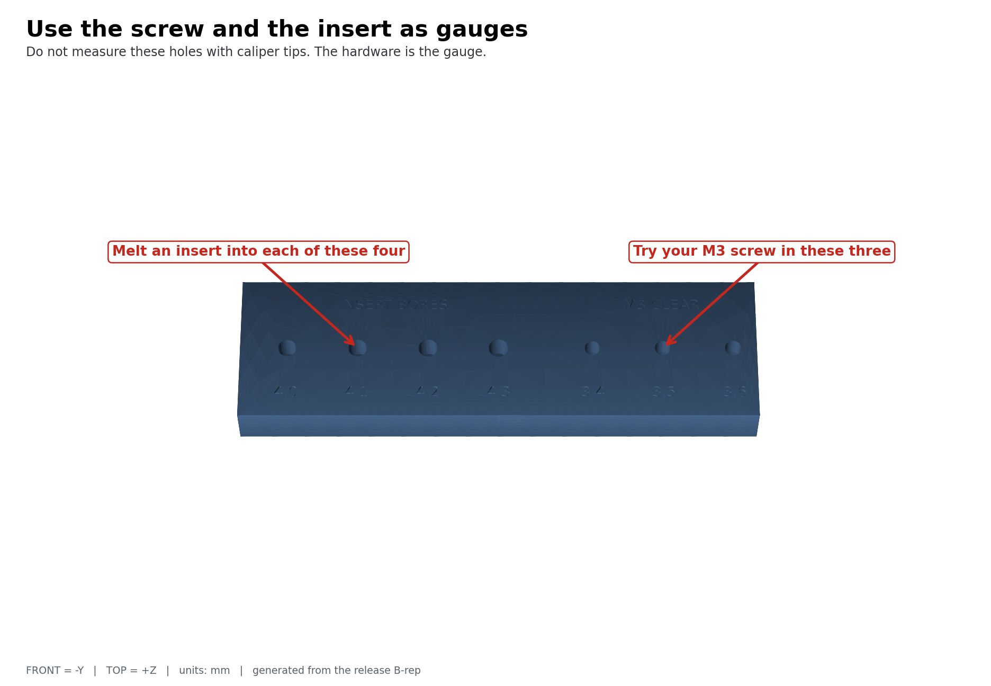
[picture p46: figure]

Using the screw and insert as go/no-go gauges

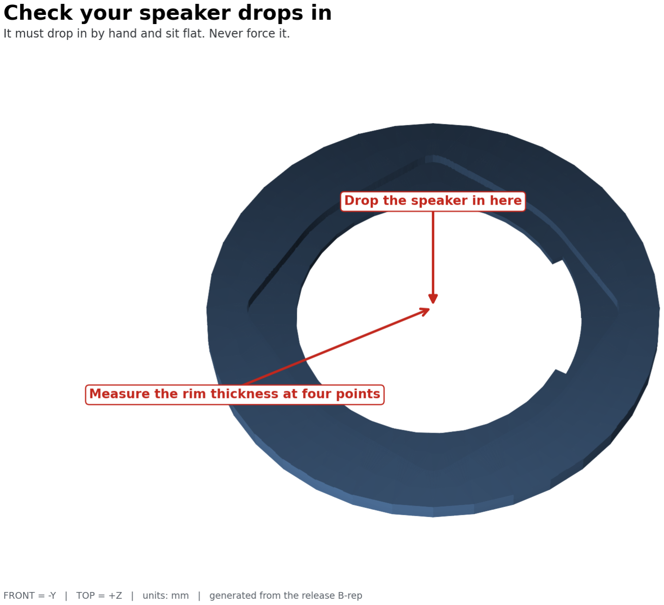
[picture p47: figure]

Checking the speaker seats by hand

Checking a radiator seats by hand

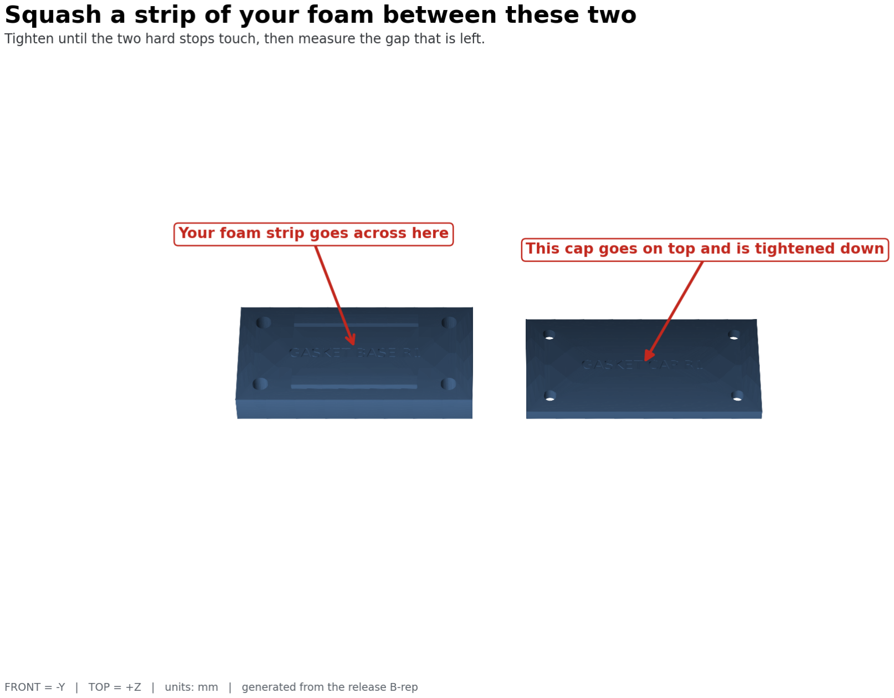
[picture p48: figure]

Squeezing the foam between the two gasket pieces

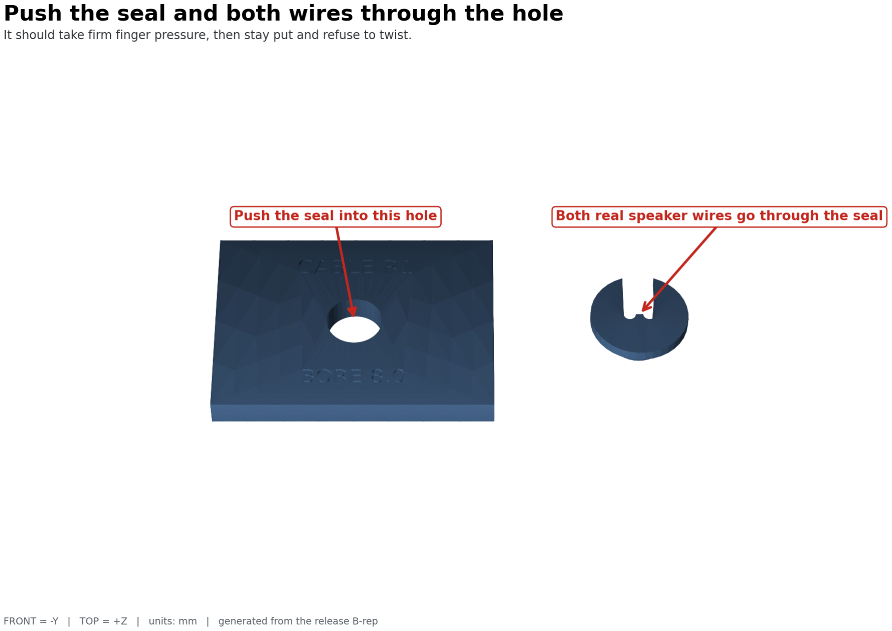
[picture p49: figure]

Fitting the two real wires through the cable seal

# The eight checks

Check | What you do | It passes when
XY scale | Inside caliper jaws across the engraved 110.60 mm recess, at three heights | 110.40-110.80 mm after correction
Z scale | Outside jaws across a clean 3.00 mm edge, at four corners | 2.90-3.10 mm
Screw clearance | Try a clean M3 screw in the 3.4, 3.5 and 3.6 mm holes | smallest hole the screw falls through without force
Insert bore | Install identical inserts into the 4.0-4.3 mm blind bores | square and flush, no crack, no spin
Speaker fit | Seat the real ND91-4 in its test ring | drops in by hand, flange lies flat, play under 0.30 mm
Radiator fit | Seat one real passive radiator in its test ring | drops in by hand, flange lies flat, play under 0.30 mm
Gasket squeeze | Clamp a strip of your actual foam until both hard stops touch | 15%-45% compression, no light path, foam not cut
Cable seal | Push the two real conductors and the TPU seal into the test hole | moderate finger force, seal cannot rotate or lift

Do not measure a 3-4 mm hole with caliper tips. The screw and the insert are the gauges.

# Enter your numbers

You have three ways to turn those measurements into corrected files. All three produce the same physical_calibration.yaml.

1. In your browser (easiest). Open the calibration wizard page listed in the project README, type in what you measured, and it computes and downloads the file for you. Nothing to install.
2. On GitHub. Paste the file contents into the "Calibrated build" workflow and GitHub rebuilds the whole corrected package for you to download.
3. On your own computer. Run python scripts/calibrate.py, which asks the same questions and then runs make calibrated-release.

Reprint every calibration piece affected by a correction you entered, and re-check it. Continue only when all eight checks pass on corrected pieces.

If a piece fails, do not sand it and do not "make it work". Correct the number, regenerate, and reprint. Sanding a sealing face destroys the seal.

# Phase 4 — Print every enclosure part

Now print the real parts. Open PRINT_THESE_FILES/2_ULTRA_ENCLOSURE_PARTS and print every file:

File | Print this many | Material
01_MAIN_SPEAKER_BODY.3mf | 1 | ASA
02_ELECTRONICS_DIVIDER.3mf | 1 | ASA
03_SPEAKER_CLAMP_RING.3mf | 1 | ASA
04_RADIATOR_CLAMP_RING_PRINT_TW O.3mf | 2 | ASA
05_BOTTOM_BASE.3mf | 1 | ASA
06_WEIGHT_TRAY.3mf | 1 | ASA
07_WEIGHT_TRAY_LID.3mf | 1 | ASA
08_BOTTOM_ACCESS_PANEL.3mf | 1 | ASA
09_MIC_ISOLATORS_TPU_PRINT_FOUR.3 mf | 4 | TPU 95A
10_OUTER_SKIN_BOTTOM.3mf | 1 | ASA
11_OUTER_SKIN_MIDDLE_WITH_GRILLES .3mf | 1 | ASA
12_OUTER_SKIN_TOP.3mf | 1 | ASA
13_FLEXIBLE_BOTTOM_GRIP_TPU.3mf | 1 | TPU 95A
14_LEAK_TEST_TOOL.3mf | 1 | ASA

Note that the radiator clamp ring is the only part you print twice.

The grille skin segment, positioned on the bed

Then open PRINT_THESE_FILES/3_SQUIRCLE_TOP_PARTS and print all six official Satellite top parts. These are not optional; they complete the normal Satellite top:

File | Print this many | Material
01_SATELLITE_MID_PLATE.stl | 1 | ASA
02_SATELLITE_THREADED_PLATE.stl | 1 | ASA
03_CIRCUIT_BOARD_SPACER.stl | 1 | ASA
04_TOP_LOCK_RING.stl | 1 | ASA
05_BUTTON_AND_LIGHT_TOP.stl | 1 | ASA
06_SNAP_IN_LIGHT_RING.stl | 1 | ASA

PRINTING_GUIDE.pdf holds the full slicer baseline, the per-part orientation sheets, and the inspection checklist. Check each part as it comes off the bed: gasket lands must be continuous and unbroken, shell slots must all be open, clamp rings must be flat within 0.20 mm, and no insert bore may have opened into the chamber.

# Phase 5 — Cut the three foam gaskets

The gaskets are not printed. You cut them from your 2.0 mm EPDM sheet using the 1:1 templates in
GASKET_TEMPLATES/. Print each template at exactly 100% scale (no "fit to page"), check the printed size against the sheet, then cut with a sharp knife or a cutting plotter.
ID | Seal | How many | Material | Template
G01 | divider_gasket | 1 | 2.0 mm closed-cell EPDM, soft, smooth skin | GASKET_TEMPLATES/d ivider_gasket.dxf

ID | Seal | How many | Material | Template
G02 | driver_gasket | 1 | 2.0 mm closed-cell EPDM, soft, smooth skin | GASKET_TEMPLATES/d river_gasket.dxf
G03 | passive_radiator_gasket | 2 | 2.0 mm closed-cell EPDM, soft, smooth skin | GASKET_TEMPLATES/p assive_radiator_gasket.d xf

The fourth seal, G04, is the flexible cable seal you already printed in TPU as 08_FLEXIBLE_CABLE_SEAL_TPU.3mf.

Each gasket must be one continuous piece. Do not splice, join, or stretch a gasket to fit.

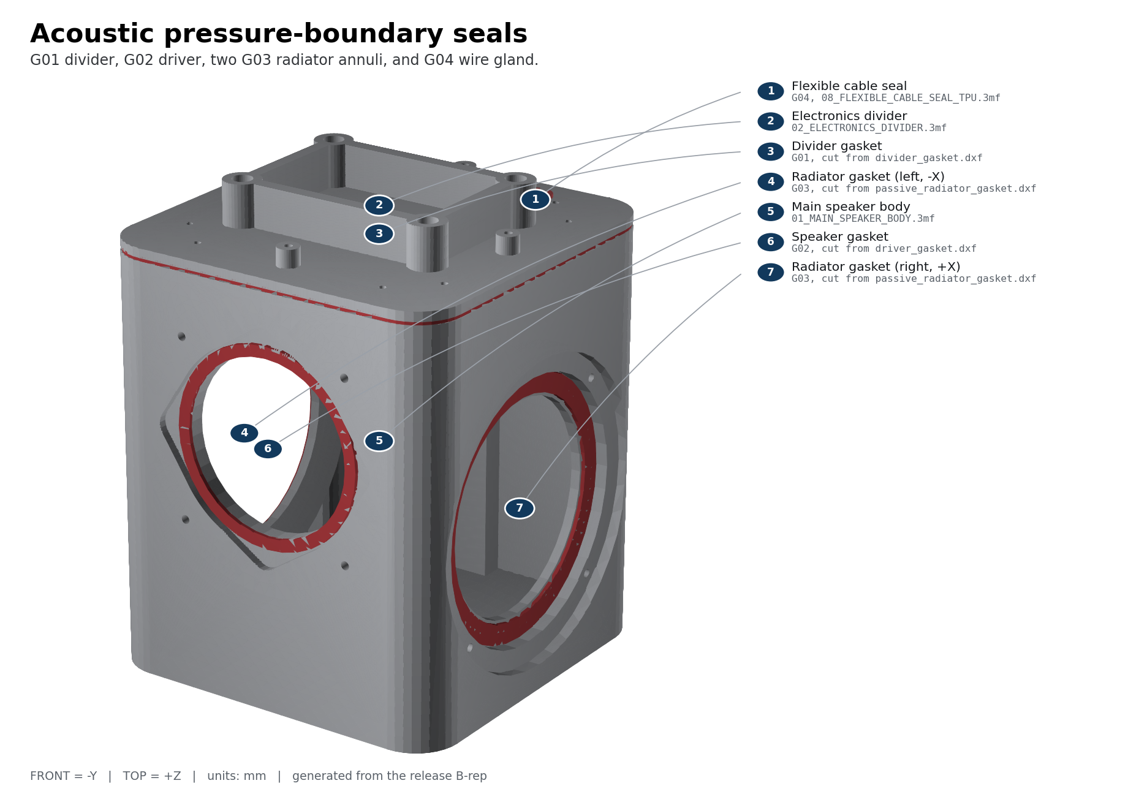
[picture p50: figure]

Where each of the four seals sits

# Phase 6 — Lay out and check every part

Put everything on a clean table and account for it before you start. The diagram below names every single piece and tells you which file it came from or which item you purchased.

Every part in the build, with its file name

Check that you have all of it:

- All 12 printed Ultra parts, with two radiator clamp rings.
- All 6 printed Satellite top parts.
- One Dayton Audio ND91-4 speaker and two Dayton Audio DSA115-PR radiators.
- Three cut foam gaskets and one printed TPU cable seal.
- Every screw and insert in FASTENERS.csv.
- Two steel ballast plates, deburred and dry.
- Two matched radiator tuning masses, each weighed to 8.00 g within 0.02 g.
- One red/black speaker lead with the correct plug.

The screws all look similar, so identify them by length before you begin:


Screw lengths and where each one is used

Do not begin assembly with a missing part.

# Phase 7 — Assemble

Nine steps, in this order. Each one shows what to install, which screws to use, which seal it captures, and how to tell it is right.

Tighten every screw into a printed part gently, using the short arm of the 2 mm hex key: 0.35 N m is the target and 0.45 N m is the absolute maximum. Stop as soon as the parts meet evenly. Do not keep turning "for luck".

### Step 1 of 9 — Identify and inspect the hardware

Build step 1: Identify and inspect the hardware

You need: Batch 1 Core rev4.1 and HAT rev4.1; O01 official_mid_plate; O02 official_mid_plate_threads; O03 official_pcb_spacer; O04 official_lock_ring; O05 official_top_plate; O06 official_top_plate_snap_in_diffuser_ring

Screws: none Seal: none Tools: bright light; calipers

Do this: Confirm the board revision labels. Reject Batch 2 / Satellite1.1. Check off all six required official filenames in OFFICIAL_PARTS/REQUIRED_SINGLE_MATERIAL and every required custom 3MF in the Printing Guide. Inspect every sealing face and remove strings without rounding an edge.

It is right when: Correct Batch 1 hardware and every required printed part are present; no crack, warp, blocked bore, or damaged gasket land.

Careful: Do not force or approximately place the Core. Its exact stack placement requires the physical official hardware.

### Step 2 of 9 — Install and cold-check all M3 inserts

Build step 2: Install and cold-check all M3 inserts

You need: main_cabinet, pressure_divider, base_skirt, ballast_cartridge, skin segments

Screws: H01 inserts Seal: none Tools: temperature-controlled iron; M3 insert tip; square

Do this: At 250-270 C, press each insert into its labeled blind bore until flush and square. Let every insert cool for five minutes. Thread an M3 screw by hand for three turns.

It is right when: No insert spins, tilts, protrudes, or blocks before three turns.

Careful: Do not torque a hot insert. Fumes and the iron can burn; ventilate and use eye protection.

### Step 3 of 9 — Wire and clamp the active driver

Build step 3: Wire and clamp the active driver

You need: main_cabinet, Dayton ND91-4, driver_gasket, active_driver_clamp_ring, JST-XH lead

Screws: F04, 4 screws Seal: G02 Tools: 2.0 mm hex; crimper or soldering iron; polarity tester

Do this: Peel the thin foam ring off the back of the driver's flange and throw it away; it is stuck on with tape, and G02 replaces it. Leaving both in place stacks two seals and neither compresses predictably. Mark the red conductor positive. Connect red to the terminal marked + and black to -. Look into the driver opening before you fit anything: at the top, in line with the topmost corner of the recess, the wall is notched wider. The driver's terminals sit in line with one of its four corner tabs and stand proud enough that the basket will not pass the opening anywhere else, so rotate the driver until its terminals point straight up into that notch. It only goes in one way round, and that is also the way the wire needs to leave to reach the cable passage in the divider above. Center G02, seat the driver from the -Y/front side, fit the clamp ring, and tighten F04 in two diagonal passes to 0.35 N m; never exceed 0.45 N m.

It is right when: Ring bottoms evenly; G02 is continuous all the way round and covers all four unused driver mounting holes; cone moves outward on a brief 1.5 V positive polarity pulse.

Careful: Use only a brief low-voltage polarity pulse. Never connect a loose driver to the powered HAT.

### Step 4 of 9 — Mass-match and clamp both passive radiators

Build step 4: Mass-match and clamp both passive radiators

You need: 2 passive radiators, 2 passive_radiator_gaskets, 2 clamp rings, matched tuning masses

Screws: F05, 8 screws total Seal: G03, one per side Tools: 0.01 g scale; 2.0 mm hex

Do this: Trim and weigh two identical tuning masses to the value in reports/acoustics/summary.json, matching them within 0.02 g. Apply one centred on each radiator mass post. Install radiators on +/-X with matching orientation, then tighten each F05 crosswise to 0.35 N m; never exceed 0.45 N m.

It is right when: Added masses match within 0.02 g; both rings bottom evenly; surrounds move freely and do not touch the shell keep-out.

Careful: Unequal mass defeats reaction-force cancellation. Do not press on either cone.

### Step 5 of 9 — Route the cable, close the divider, and leak-check

Build step 5: Route the cable, close the divider, and leak-check

You need: pressure_divider, divider_gasket, leak_test_adapter, cable_gland

Screws: F03, 8 screws Seal: G01; temporary adapter then G04 Tools: 2.0 mm hex; hand bulb; 0-500 Pa gauge; leak-detection solution

Do this: Pass both conductors through the divider. Fit the temporary adapter over them, place G01 without twists, and tighten F03 in a star pattern to 0.35 N m. Apply only 100-250 Pa with a hand bulb. Brush leak solution on external gasket seams; no bubbles are allowed. Vent, pull the adapter upward, and install G04 with its flange toward the electronics bay.

It is right when: No growing bubbles, abnormal diaphragm displacement, or audible leak; final gland cannot rotate or lift by finger force.

Careful: Never use shop air, never exceed 250 Pa, and keep liquid away from electronics. This is a gross-leak screen, not an acoustic-Q measurement.

### Step 6 of 9 — Install the base and retained ballast

Build step 6: Install the base and retained ballast

You need: base_skirt, ballast_cartridge, 2 steel plates, ballast lid, bottom_service_plate

Screws: F06, F07, F08 Seal: none Tools: 2.0 mm hex; scale

Do this: Attach the base skirt with F07. Place both deburred dry plates flat in the cartridge; there must be no rocking. Install the lid with F06, insert the cartridge from below, and capture it with the bottom service plate using F08.

It is right when: Cartridge mass matches the steel stack listed in BOM.csv; no plate moves when shaken gently; all four lid screws engage at least 3 mm.

Careful: The steel stack is heavy. Keep fingers clear and do not operate the unit without the retained lid and service plate.

### Step 7 of 9 — Stack the three outer skin segments

Build step 7: Stack the three outer skin segments

You need: shell_base, shell_grille, shell_crown; lower assembly

Screws: F09, 4 screws with nylon washers; F02, 4 screws into the divider Seal: none Tools: 2.0 mm hex

Do this: Work bottom to top. Slide shell_base up over the cabinet with FRONT at -Y, invert on a soft mat, and install F09 through the bottom service plate into its four bosses. Stand the unit back up. Press shell_grille down onto the exposed lap until its outer face meets the segment below; the four crush ribs give a firm, even resistance and the joint closes on 0.15 mm of interference, so it should need hand pressure and stay put. Press shell_crown on the same way, then bolt it down onto the divider's four bosses with F02. Check that all three grille windows line up with the driver and both radiators.

It is right when: Both seams show an even hairline shadow line all round with no step you can catch a fingernail on; no segment rocks or rattles when the body is tapped; at least 2 mm clearance from every clamp ring and surround; no wire visible through a window.

Careful: Do not force a segment on if it binds — lift it off and check for a stringing artefact on the lap or a crush rib that printed proud. Never flex a segment over an obstruction. The crown must be bolted to the divider before the official stack goes on, because its tabs sit underneath.

### Step 8 of 9 — Fit the mic isolators and the official Batch 1 upper stack

Build step 8: Fit the mic isolators and the official Batch 1 upper stack

You need: mic_isolation_bushing x4; O01-O06 official prints; Batch 1 HAT/Core

Screws: F01 (M3 x d4 shoulder screws, 16 mm shoulder), F10, F11; 4 of each Seal: none; electronics bay is outside the acoustic chamber Tools: 2.0 mm hex; ESD-safe bench

Do this: Press one TPU isolation bushing into each of the four divider counterbores, flange up. Seat O01 on the four bushing flanges — it must rest on elastomer, not on printed plastic. Install F01 and tighten until each shoulder bottoms firmly on the counterbore floor; the screw head then stops 0.3 mm above the plate and the plate stays floating on the TPU. Snap O06 into O05 (or use both O07/O08 during a multi-material O05 print; never install O06 and O08 together). Align O03's taller standoffs with the I/O side and locate the HAT. Install the Core/HAT using the official Batch 1 sequence. Align the logos and I/O on O04/O05, engage the snaps, and rotate the lock ring. Align O02's four nubs with O01 and keep I/O toward rear/+Y. Connect the keyed JST-XH speaker plug before closure.

It is right when: The official top sits flush with the surrounding flat top — you should feel a hairline, not a step or a lip. The upper stack has a barely perceptible give when pressed, which is the isolation working. USB-C remains reachable; cable has service slack and cannot enter a moving-part envelope; buttons click and diffuser/LED apertures remain clear.

Careful: F01 must be M3 x d4 shoulder screws, not ordinary M3 screws. An ordinary screw clamps in parallel with the elastomer at roughly 35 times its stiffness, so the TPU carries under 3% of the load path and the isolation does nothing at all. If the plate feels rock solid, you have the wrong screws. Core placement is REQUIRES_PHYSICAL_VALIDATION: follow the official Batch 1 instructions and stop at any collision.

### Step 9 of 9 — Fit the anti-slip ring and complete inspection

Build step 9: Fit the anti-slip ring and complete inspection

You need: anti_slip_ring; complete assembly

Screws: none Seal: inspect G01-G04 Tools: hands; flashlight

Do this: Stretch the TPU ring evenly around the bottom rim. Set the unit upright and inspect all seams, fastener heads, slots, cable exits, buttons, and moving components.

It is right when: Unit stands without rocking; no rattle is heard during gentle handling; every fastener is present and every seal is continuously compressed.

Careful: Do not power the unit until the commissioning checklist is ready.

# Phase 8 — Test before you use it

Complete every check in TESTING_AND_COMMISSIONING_GUIDE.pdf. The short version:

- The gentle 100-250 Pa leak screen shows no growing bubble at any seal.
- The speaker cone moves outward on a brief positive polarity pulse.
- Both radiators move freely and never scrape.
- Every button clicks once and returns.
- Every LED segment lights evenly.
- All four microphones work.
- USB-C plugs in and out without touching the shell.
- Wi-Fi connects, and you have recorded the signal beside a bare kit.

- There is no buzz, rattle, air whistle, overheating, or softened plastic.

Never use shop air on this enclosure, and never exceed 250 Pa.

Stop using the unit if any check fails. Fix the cause and repeat the test.

# Optional — Wrapping the body in speaker cloth

Entirely optional, and purely cosmetic: the enclosure is finished and airtight without it. Cloth hides every print seam and layer line, so the body reads as one continuous surface. The grille windows stay acoustically open underneath.

Decide before you print. The wrap needs the *_FOR_FABRIC skin files, which are the same three segments with a concealed retention channel inside each roll. The standard files have no channel, because on a bare printed finish it reads as a horizontal line — exactly what this design exists to remove. You cannot add the channel later without reprinting.

# What to buy

- About 0.5 m of acoustically transparent speaker grille cloth. Stretch knit intended for loudspeakers is right; upholstery fabric, canvas and blackout linings are not.
- The breath test: hold a single layer over your mouth and breathe out hard. If you feel noticeable resistance, it will audibly dull the treble. Anything you can breathe through freely is fine.
- A small tube of contact adhesive. Not superglue, which wicks and stiffens.

# Steps

1. Print the fabric variants. From PRINT_THESE_FILES/2_ULTRA_PARTS, use 10F, 11F and 12F in place of 10, 11 and
12. Everything else is unchanged.
2. Assemble the three segments first, exactly as in phase 7, and bolt them down. Wrapping before assembly puts a fabric edge inside a lap joint, which will hold the seam open.
3. Cut a rectangle about 30 mm taller than the body and long enough to go right round plus 25 mm of overlap. Cut with the stretch running around the body, not up it.
4. Find the overlap seam position. Put it on the rear (+Y) face, which has no grille window. It is the only part of the wrap you will be able to see.
5. Tension it evenly. Work from the seam outward in both directions, keeping the weave straight. A squircle shows tension variation at the corners far more than a cylinder does, so check the weave stays square as it passes each corner rather than pulling into a curve.
6. Tuck the top edge into the channel under the top roll with a blunt plastic tool. Do the whole perimeter before committing any adhesive.
7. Tuck the bottom edge into the lower channel the same way, keeping the vertical tension while you work.
8. Glue last, and only inside the channel. A thin bead in the channel only. Keep adhesive away from the grille windows: it stiffens the cloth locally and changes its acoustic transparency, which you cannot undo.
9. Trim the overlap flush at the rear seam once the adhesive has set.

# Checks

- The weave runs straight and square across all four faces, with no diagonal pull at the corners.

- All three grille windows are still visibly open cloth, with no adhesive bleed and no stretched-thin patches.
- The cloth still passes the breath test after wrapping. If tension has closed it up over a window, it is too tight.
- The anti-slip ring still seats on the base without trapping a fabric edge.

# Phase 9 — Opening it again later

Disconnect power and wait five minutes. MAINTENANCE_GUIDE.pdf gives the safe removal order for each subassembly.

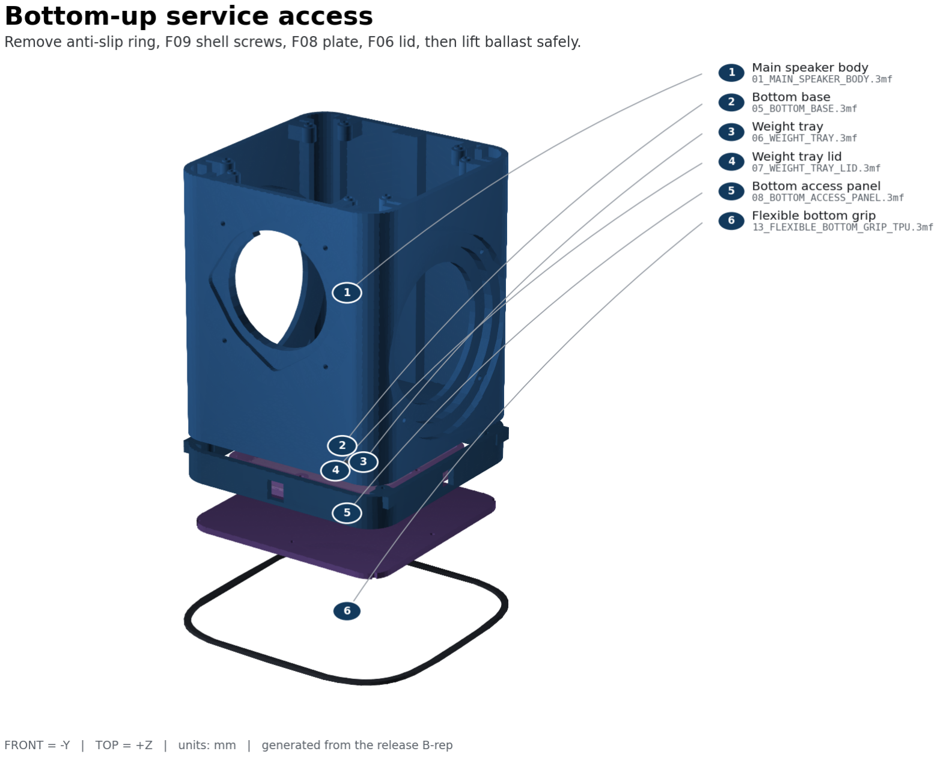
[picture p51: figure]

The order things come apart in

Replace any gasket you disturb. Never cut a wire to get a part out, and never reuse a torn or permanently flattened seal.

# If something goes wrong

Symptom | Most likely cause | What to do
Calibration piece is warped | chamber too cool, or bed not clean | fix the printer and reprint; never compensate for a warped part
Every hole is too small | over-extrusion or elephant-foot compensation | fix flow and first-layer compensation before adding a CAD offset
Insert cracks the boss | bore too small or iron too hot | choose a larger bore or reduce dwell; never add torque
Speaker will not sit flat | print strings, or cutout too small | remove strings only; correct the cutout and reprint the coupon
Cable seal leaks or spins | conductor too thick, or wet TPU | confirm conductor OD is 1.8 mm or less, dry the TPU, reprint

Symptom | Most likely cause | What to do
Shell will not slide on | clamp ring or surround contact | stop immediately; find the contact rather than forcing the shell
Bubbles during the leak check | gasket twisted, pinched, or a screw left loose | vent, reopen, replace the gasket, and reseat evenly
One radiator moves more than the other | unequal tuning mass | reweigh both stacks; they must match within 0.02 g

# What is still unproven

The geometry, exports, schedules, and documents in this release pass their digital gates. No completed physical unit has been measured. That means your own calibration, leak, acoustic, thermal, Wi-Fi, and microphone checks are the first real evidence this design works. Record what you find.

ENGINEERING_APPENDIX.md lists every open risk, its consequence, and how to close it.

Source commit 508add3e53b5. No physical validation has been performed.

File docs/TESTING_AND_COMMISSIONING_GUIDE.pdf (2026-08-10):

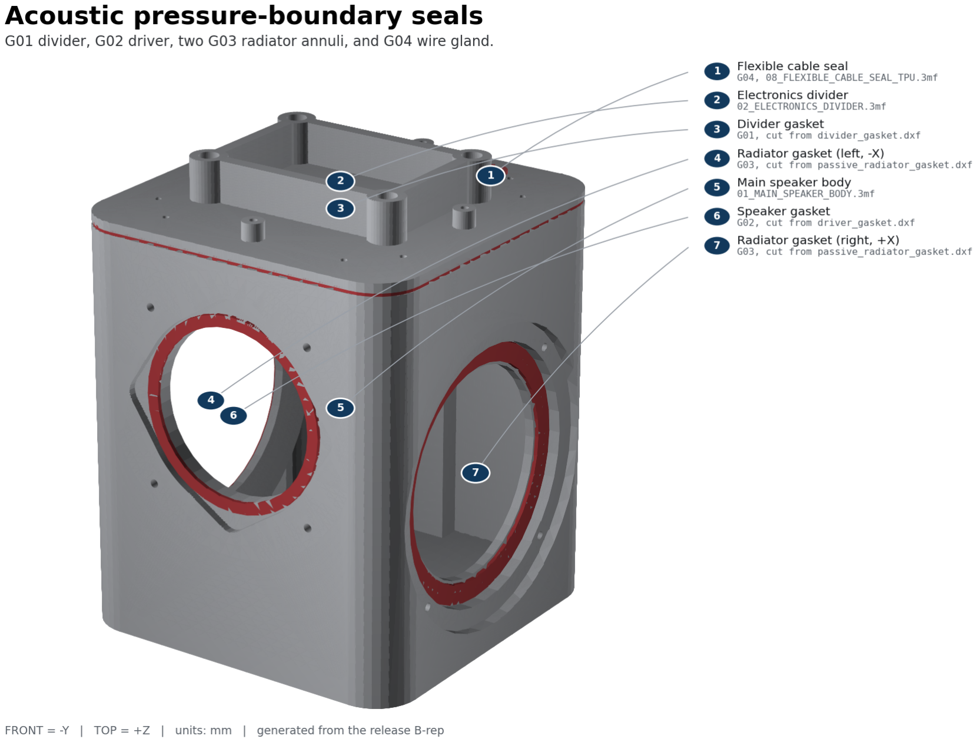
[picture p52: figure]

Satellite1 Ultra RC1 — DIGITAL_PROTOTYPE_READY | Page 1

# Testing and Commissioning Guide

Every result in this guide requires a physical unit and is REQUIRES_PHYSICAL_VALIDATION.

Seal locations

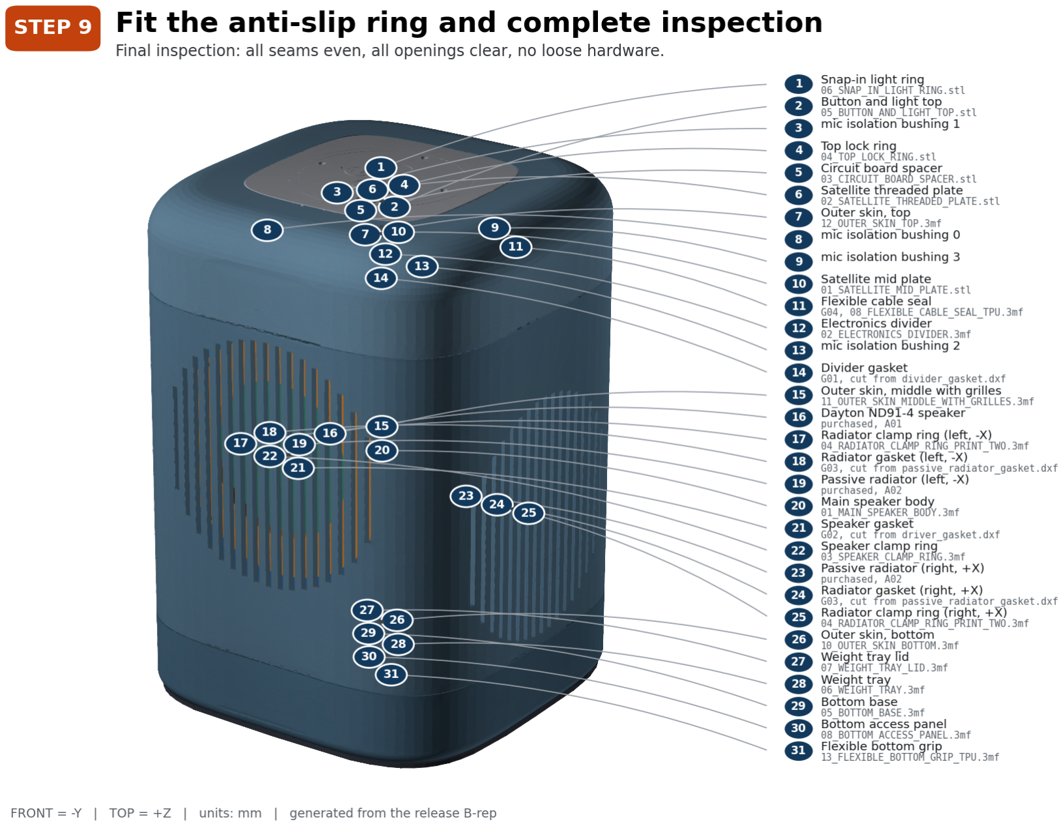
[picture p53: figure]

Final assembled inspection

# Before power

1. Verify red driver lead to + and black to -.
2. Confirm both radiators carry equal added mass: model target 8.00 g each.
3. Confirm every screw ID and quantity against FASTENERS.csv.
4. Confirm G01-G04 are continuous and no wire touches a moving component.
5. Perform the 100-250 Pa gross-leak screen during assembly. Never use shop air.

# Controlled first power

Use a current-limited supported USB-C supply and the official Batch 1 firmware. Start muted, then at minimum volume.

- LEDs: all segments visible and even.
- Buttons: each click registers once and returns freely.
- USB-C: plug inserts/removes without shell contact.
- Wi-Fi: connect and record RSSI beside a bare Batch 1 control.
- Microphones: verify all four channels, then run 50 wake-word trials at 1, 3, and 5 m on-axis and 45 degrees.
- Audio: play a polarity pulse, then a 100-500 Hz sweep at low level. Stop for rub, buzz, air noise, or asymmetric radiator motion.

# Acoustic commissioning

Measure impedance magnitude and phase from 20 Hz to 20 kHz at low level. The two low-frequency peaks should bracket tuning; the minimum between them is the real Fb. Model targets are 60.0 Hz Fb, 4.39 ohm minimum impedance, and 59.0 Hz f3. They are ENGINEERING_ESTIMATE, not pass/fail measurements.

Start DSP with the modelled 51.0 Hz fourth-order high-pass and no positive bass boost. Final EQ, limiter, and tuning mass require measured response and excursion.

# Thermal and reliability

Instrument Core SoC, amplifier area, and electronics-bay air. Test 60 minutes idle and 60 minutes pink noise at 25 C, then repeat at 35 C. Pass only if every supplier limit retains 15 C margin, there is no throttling, and no printed part softens. Perform a gentle rattle check and repeat the leak/impedance check after five service cycles.

Record results; do not change the repository status to physically validated without the measurements.

Source commit 508add3e53b5. No physical validation has been performed.

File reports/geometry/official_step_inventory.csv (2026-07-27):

path | occt_valid | solid_count | shell_count | solid_volume_mm3 | xmin_mm | ymin_mm | zmin_mm | x_size_mm | y_size_mm | z_size_mm_or_error
reference-assets/official/Satellite1-Enclosures/DIY Enclosures/Cylindrical Enclosures/Geometry Files/STEP/General Parts/(Optional) Dev Kit UFO Base for No Speaker.step | True | 1 | 1 | 22136.036796 | -46.200000 | -45.200000 | -11.800000 | 92.400000 | 92.400000 | 9.800000
reference-assets/official/Satellite1-Enclosures/DIY Enclosures/Cylindrical Enclosures/Geometry Files/STEP/General Parts/1.5mm Wire Cover.step | True | 1 | 1 | 918.021320 | -1.500000 | -1.400000 | -10.450000 | 14.000001 | 8.900000 | 11.950000
reference-assets/official/Satellite1-Enclosures/DIY Enclosures/Cylindrical Enclosures/Geometry Files/STEP/General Parts/1mm Wire Cover.step | True | 1 | 1 | 943.482598 | -1.500000 | -1.400000 | -10.450000 | 14.000001 | 8.900000 | 11.950000
reference-assets/official/Satellite1-Enclosures/DIY Enclosures/Cylindrical Enclosures/Geometry Files/STEP/General Parts/2mm Wire Cover.step | True | 1 | 1 | 882.802532 | -1.500000 | -1.400000 | -10.450000 | 14.000001 | 8.900000 | 11.950000
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

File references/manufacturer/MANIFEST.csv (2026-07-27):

file | source_url | retrieval_date | sha256 | evidence_label
Dayton_DMA105-PR_spec.pdf | https://www.daytonaudio.com/images/resources/295-590--dayton-audio-dma105-pr-spec-sheet.pdf | 2026-07-27 | 3b18854fdb81278b0b918290d016cd672995f7eac823b4e323ad1575ec30be9b | DERIVED_FROM_MANUFACTURER_DRAWING
Dayton_ND91-4_Klippel.pdf | https://www.daytonaudio.com/images/resources/290-226--nd91-4-klippel-data.pdf | 2026-07-27 | 1cb60e26f04f5ae39d34b1a5058cf32a7bc1f881f05a9f7edf5f929f67b8f3ca | DERIVED_FROM_MANUFACTURER_DRAWING
Dayton_ND91-4_spec_2026-02-26.pdf | https://www.daytonaudio.com/images/resources/290-226--dayton-audio-nd91-4-specifications.pdf | 2026-07-27 | 261aa33d48543b9b2386342f1f59647bfe833c379cd67a1e5e1580327956f8e9 | DERIVED_FROM_MANUFACTURER_DRAWING
SB_Acoustics_SB12PACR-00.pdf | https://sbacoustics.com/wp-content/uploads/2020/02/SB12PACR-00.pdf | 2026-07-27 | 4d1e099f7f267307920ceb65e4263aaf3481bd7354243470c7cfdbfd0fa37295 | DERIVED_FROM_MANUFACTURER_DRAWING
SB_Acoustics_SB12PFCR-00.pdf | https://sbacoustics.com/wp-content/uploads/2020/02/SB12PFCR-00.pdf | 2026-07-27 | 838affa3bac7a257dafc27bffca21b17e24f33c342400ea1c375064146b9a316 | DERIVED_FROM_MANUFACTURER_DRAWING
ScanSpeak_10F-4424G00_advanced.pdf | https://www.scan-speak.dk/datasheet/pdf/10f-4424g00.pdf | 2026-07-27 | 69a545f594f96e85bf94939ea6bd9cecb5b7fc81b81cd7eb0083a6a1d6c8b968 | DERIVED_FROM_MANUFACTURER_DRAWING
TI_TAS2780_revB.pdf | https://www.ti.com/lit/ds/symlink/tas2780.pdf | 2026-07-27 | f7df09c64b3de67db154fc83d55e7c95c883a8c39b946a6f6518eded0afd0270 | DERIVED_FROM_MANUFACTURER_DRAWING
Tectonic_TEBM65C20F-4_rev1.2.pdf | https://www.tectonicaudiolabs.com/wp-content/uploads/2022/10/TEBM65C20F-4-Rev-1.2.pdf | 2026-07-27 | 9627ff7ba6a29a706242bb57e4d9f810120a9350dc2d336af42445f6e8370d1c | DERIVED_FROM_MANUFACTURER_DRAWING

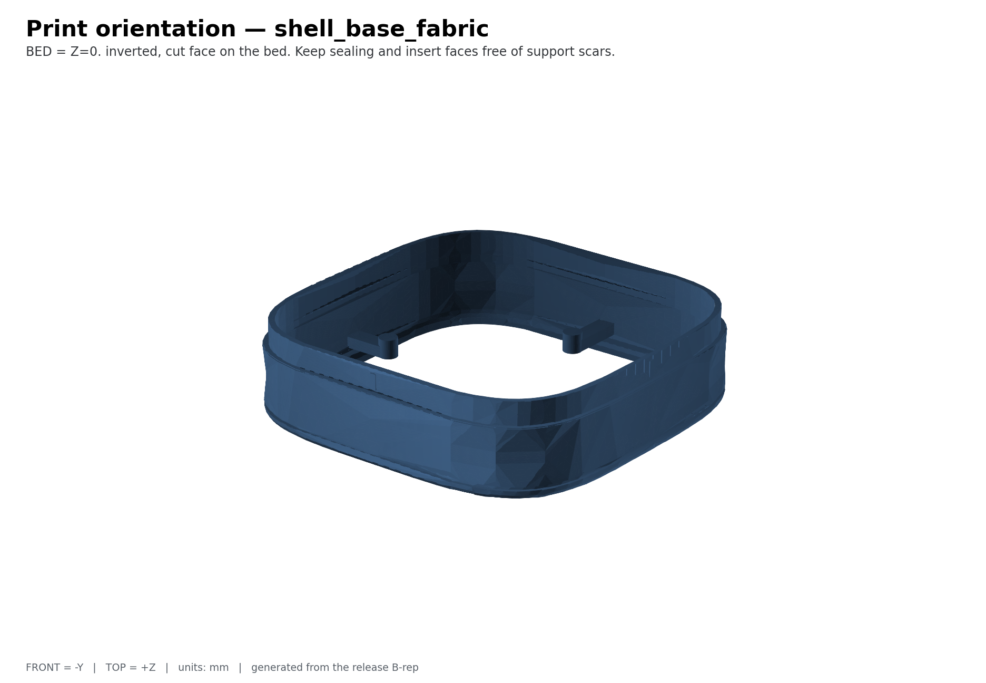
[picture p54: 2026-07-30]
release/Satellite1-Ultra-RC1/ADVANCED/IMAGES/print_orientation_shell_base_fabric.png

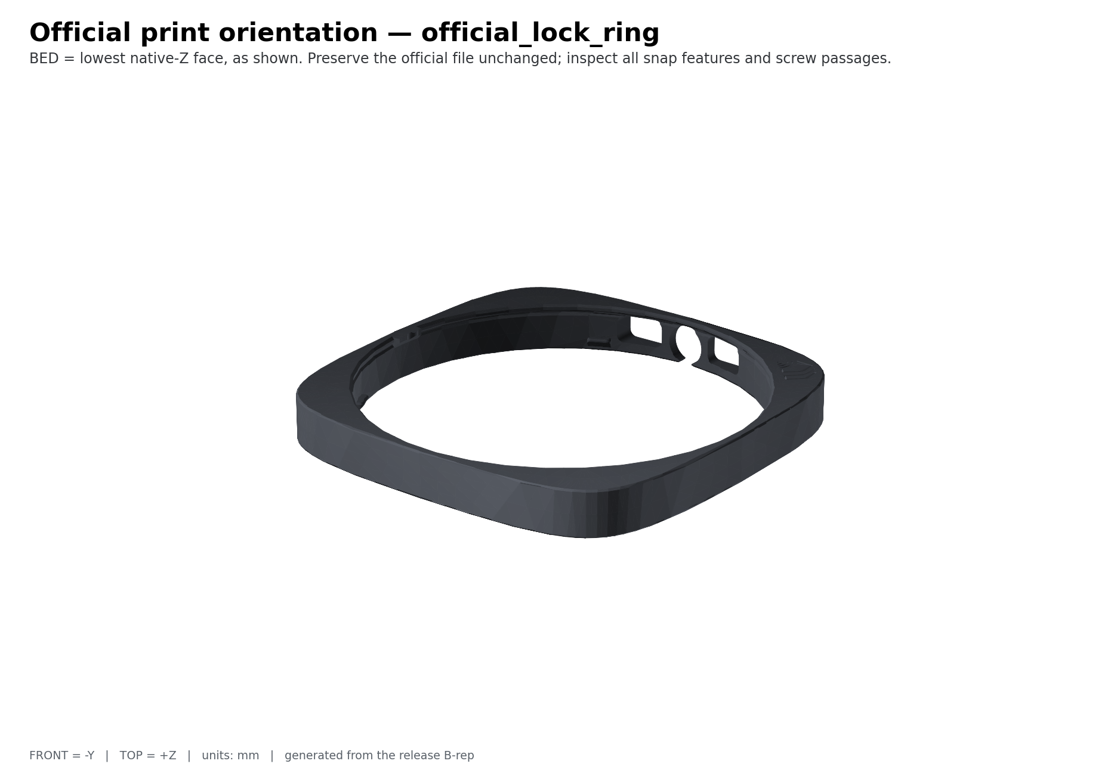
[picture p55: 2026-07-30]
release/Satellite1-Ultra-RC1/ADVANCED/IMAGES/print_orientation_official_lock_ring.png

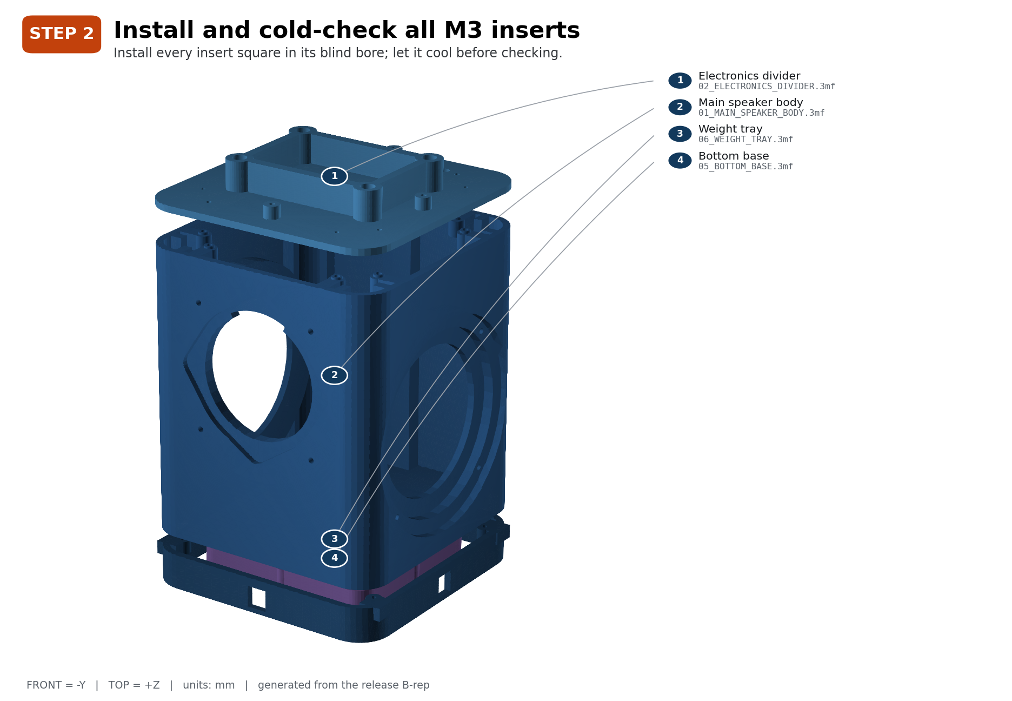
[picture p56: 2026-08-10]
reports/renders/assembly_stage_02_inserts.png

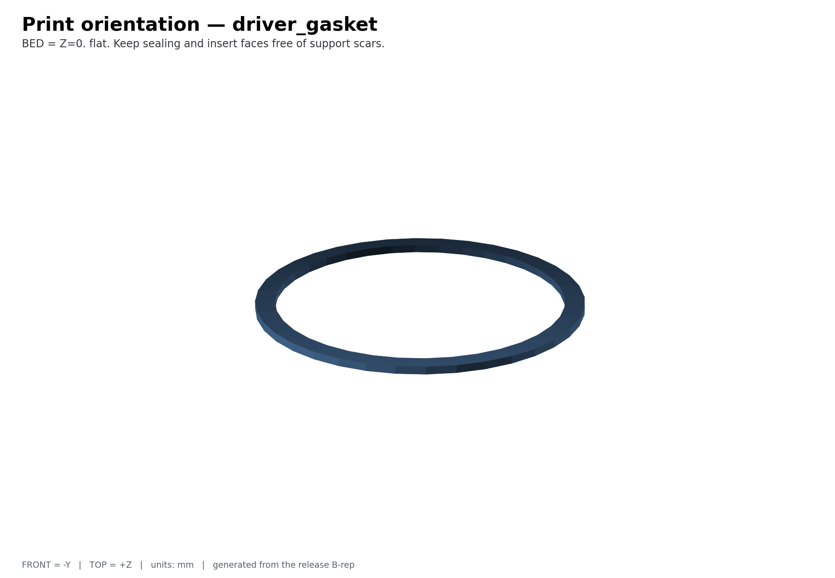
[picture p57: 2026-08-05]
release/Satellite1-Ultra-RC1/ADVANCED/IMAGES/print_orientation_driver_gasket.png

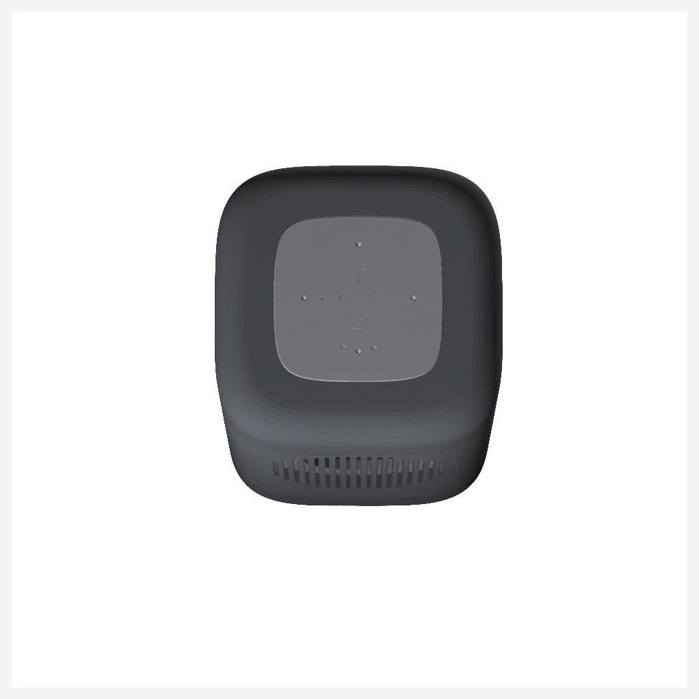
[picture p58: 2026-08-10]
release/Satellite1-Ultra-RC1/ADVANCED/IMAGES/assembly_top.png

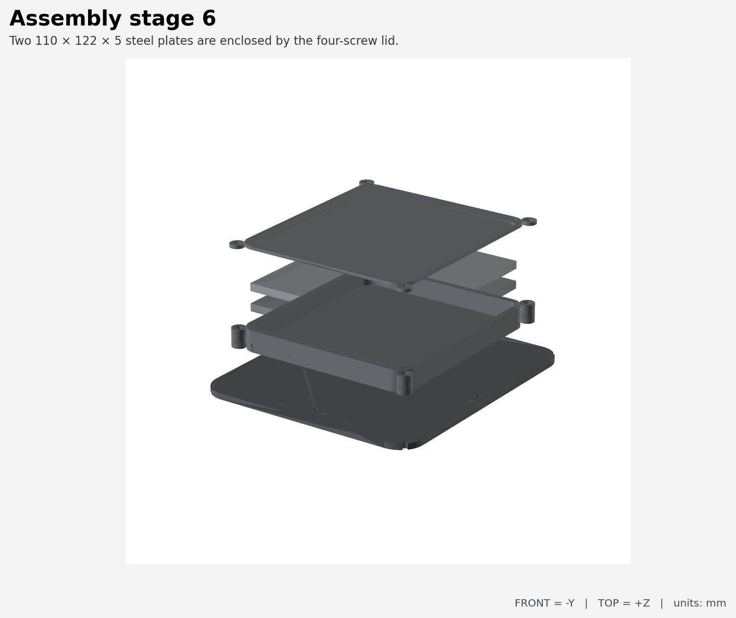
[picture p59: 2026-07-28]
reports/renders/assembly_stage_06_ballast.png

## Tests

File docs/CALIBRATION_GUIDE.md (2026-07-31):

# Mandatory Physical Calibration Guide

> **DO NOT PRINT THE FULL ENCLOSURE YET.**
> **PRINT AND COMPLETE THE CALIBRATION PARTS FIRST.**

Use the same material, nozzle, layer height, wall count, extrusion settings,
bed preparation, and chamber temperature that you will use for the enclosure.

## Print first

Print these exact files from `CALIBRATION_PARTS/`:

1. `coupon_official_interface.3mf`
2. `coupon_heat_set_insert.3mf`
3. `coupon_active_driver.3mf`
4. `coupon_passive_radiator.3mf`
5. `coupon_gasket_base.3mf`
6. `coupon_gasket_cap.3mf`
7. `coupon_cable_passage.3mf`
8. `cable_gland.3mf` in TPU 95A

ASA baseline: 0.4 mm nozzle, 0.20 mm layers, five walls, six top/bottom
layers, 35% gyroid, 100-110 C bed, 250-260 C nozzle, enclosure closed, no
supports, 5 mm brim. PETG alternative: 235-250 C nozzle, 75-85 C bed,
three-hour dry cycle if stringing is present.

## Measure and enter values

Use the engraved labels and `IMAGES/calibration_*.png`.

| Check | Where/how | Nominal | Pass | Input key |
|---|---|---:|---|---|
| XY scale | Inside jaws across `MEASURE XY 110.60` recess, three heights | 110.60 mm | 110.40-110.80 mm after correction | `xy_scale_correction_fraction = 110.60 / measured - 1` |
| Z scale | Outside jaws across clean 3.00 mm coupon edge, four corners | 3.00 mm | 2.90-3.10 mm | `z_scale_correction_fraction = 3.00 / measured - 1` |
| M3 clearance | Try a clean ISO M3 screw in labeled 3.4/3.5/3.6 holes | 3.4 mm | smallest hole that falls through without force | chosen diameter minus 3.4 |
| Insert bore | Install identical inserts in 4.0/4.1/4.2/4.3 blind bores | 4.2 mm | square, flush, no crack/spin at 0.35 N m | chosen diameter minus 4.2 |
| Driver fit | Seat the purchased ND91-4 in the labeled coupon | catalog interface | drops in by hand, <=0.30 mm radial play, flange lies flat | cutout correction and measured flange thickness |
| Radiator fit | Seat one passive radiator in the labeled coupon | catalog interface | drops in by hand, <=0.30 mm radial play, flange lies flat | cutout correction and measured flange thickness |
| Gasket | Tighten cap on a strip of the actual sheet until both stops contact | 2.00 to 1.50 mm | 15%-45% compression; no open light path | sheet thickness and compressed-thickness offset |
| Cable gland | Fit actual two 22 AWG conductors and gland in cable coupon | 8.0 mm passage | moderate finger force; gland cannot rotate or lift | cable-passage offset |

Do not use caliper tips to measure a 3-4 mm hole; the screw and insert are the
functional gauges. Enter only values you measured.

## CAD measurement illustrations

Official-interface XY and Z measurement

M3 screw and insert functional gauges

Active-driver coupon fit check

Passive-radiator coupon fit check

Gasket compression coupon stack

Cable passage and TPU gland check

## Edit one file

Copy `CALIBRATION_INPUT_TEMPLATE.yaml` to
`config/physical_calibration.yaml`, or run:

```text
python scripts/calibrate.py
```

The file exposes only user-facing corrections. Safe limits reject implausible
values before any full part is built.

## Regenerate

```text
make calibrated-release
```

Success ends with all validation, documentation, mutation, and package checks
passing. Output is in `release/Satellite1-Ultra-RC1/`.

Example successful finish:

```text
documentation PASS; 9 guides, 7 PDFs
release/Satellite1-Ultra-RC1 (all required files present)
```

Reprint every coupon affected by a nonzero correction. You are cleared for the
full enclosure only when all eight checks above pass on the corrected coupons.

## Common failures

- Warped official coupon: improve enclosure temperature, clean the bed, add the
  brim, and do not compensate a warped part.
- Every hole undersized: check flow and elephant-foot compensation before
  adding a large CAD offset.
- Insert cracks the boss: choose a larger coupon bore or reduce iron dwell; do
  not increase torque.
- Component will not sit flat: remove only print strings. Do not sand a sealing
  land; correct the cutout and reprint the coupon.
- Gland leaks or spins: verify conductor OD <=1.8 mm, dry TPU, then correct and
  reprint both the coupon and gland.

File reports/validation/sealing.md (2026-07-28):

# Sealing

- Overall status: `PASS`
- Evidence: `VERIFIED_DIGITALLY`
- Method: solid-fraction probes on the authoritative B-rep
- Physical gate (`REQUIRES_PHYSICAL_VALIDATION`): Use the temporary adapter for a 100-250 Pa gross leak screen with dilute soap solution, then confirm final sealing and tuning with an impedance sweep after installing the production cable gland.

The machine-readable source of this report is the adjacent JSON file. All unmeasured real-world performance remains `REQUIRES_PHYSICAL_VALIDATION`.

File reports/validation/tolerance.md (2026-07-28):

# Tolerance

- Overall status: `PASS`
- Evidence: `ENGINEERING_ESTIMATE`
- Physical gate (`REQUIRES_PHYSICAL_VALIDATION`): Pass the seven calibration parts and six documented checks before printing the full enclosure.

The machine-readable source of this report is the adjacent JSON file. All unmeasured real-world performance remains `REQUIRES_PHYSICAL_VALIDATION`.

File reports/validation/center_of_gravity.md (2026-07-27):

# Center Of Gravity

- Overall status: `PASS`
- Evidence: `ENGINEERING_ESTIMATE`
- Method: B-rep volume x material density, plus catalogued component masses
- Physical gate (`REQUIRES_PHYSICAL_VALIDATION`): Weigh the assembled prototype and perform controlled quasi-static tip and 3 g retention tests.

The machine-readable source of this report is the adjacent JSON file. All unmeasured real-world performance remains `REQUIRES_PHYSICAL_VALIDATION`.

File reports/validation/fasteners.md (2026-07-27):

# Fasteners

- Overall status: `PASS`
- Evidence: `VERIFIED_DIGITALLY`
- Method: computed stack, engagement and bottoming margin per joint
- Physical gate (`REQUIRES_PHYSICAL_VALIDATION`): Pull-test the selected insert/ASA/process coupon to 250 N minimum.

The machine-readable source of this report is the adjacent JSON file. All unmeasured real-world performance remains `REQUIRES_PHYSICAL_VALIDATION`.

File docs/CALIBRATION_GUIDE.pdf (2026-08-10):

Satellite1 Ultra RC1 — DIGITAL_PROTOTYPE_READY | Page 1

# Mandatory Physical Calibration Guide

DO NOT PRINT THE FULL ENCLOSURE YET. PRINT AND COMPLETE THE CALIBRATION PARTS FIRST.

Use the same material, nozzle, layer height, wall count, extrusion settings, bed preparation, and chamber temperature that you will use for the enclosure.

# Print first

Print these exact files from CALIBRATION_PARTS/:

1. coupon_official_interface.3mf
2. coupon_heat_set_insert.3mf
3. coupon_active_driver.3mf
4. coupon_passive_radiator.3mf
5. coupon_gasket_base.3mf
6. coupon_gasket_cap.3mf
7. coupon_cable_passage.3mf
8. cable_gland.3mf in TPU 95A

ASA baseline: 0.4 mm nozzle, 0.20 mm layers, five walls, six top/bottom layers, 35% gyroid, 100-110 C bed, 250-260 C nozzle, enclosure closed, no supports, 5 mm brim. PETG alternative: 235-250 C nozzle, 75-85 C bed, three-hour dry cycle if stringing is present.

# Measure and enter values

Use the engraved labels and IMAGES/calibration_*.png.

Check | Where/how | Nominal | Pass | Input key
XY scale | Inside jaws across `MEASURE XY 110.60` recess, three heights | 110.60 mm | 110.40-110.80 mm after correction | `xy_scale_correction_frac tion = 110.60 / measured - 1`
Z scale | Outside jaws across clean 3.00 mm coupon edge, four corners | 3.00 mm | 2.90-3.10 mm | `z_scale_correction_fracti on = 3.00 / measured - 1`
M3 clearance | Try a clean ISO M3 screw in labeled 3.4/3.5/3.6 holes | 3.4 mm | smallest hole that falls through without force | chosen diameter minus 3.4
Insert bore | Install identical inserts in 4.0/4.1/4.2/4.3 blind bores | 4.2 mm | square, flush, no crack/spin at 0.35 N m | chosen diameter minus 4.2
Driver fit | Seat the purchased ND91-4 in the labeled coupon | catalog interface | drops in by hand, <=0.30 mm radial play, flange lies flat | cutout correction and measured flange thickness
Radiator fit | Seat one passive radiator in the labeled coupon | catalog interface | drops in by hand, <=0.30 mm radial play, flange lies flat | cutout correction and measured flange thickness
Gasket | Tighten cap on a strip of the actual sheet until both stops contact | 2.00 to 1.50 mm | 15%-45% compression; no open light path | sheet thickness and compressed-thickness offset
Cable gland | Fit actual two 22 AWG conductors and gland in cable coupon | 8.0 mm passage | moderate finger force; gland cannot rotate or lift | cable-passage offset

Do not use caliper tips to measure a 3-4 mm hole; the screw and insert are the functional gauges. Enter only values you measured.

# CAD measurement illustrations

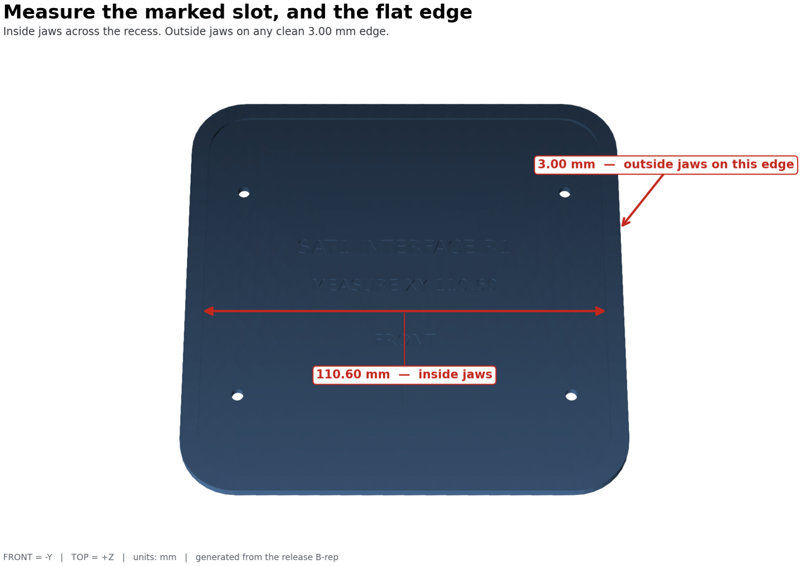
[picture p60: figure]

Official-interface XY and Z measurement

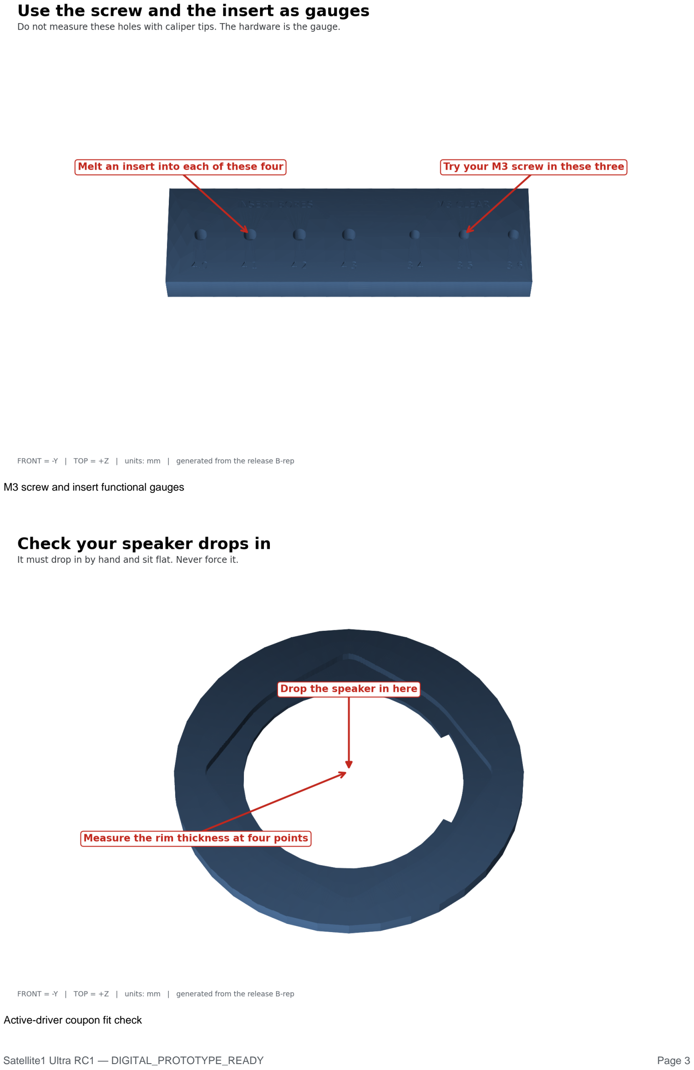
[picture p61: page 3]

M3 screw and insert functional gauges

Active-driver coupon fit check

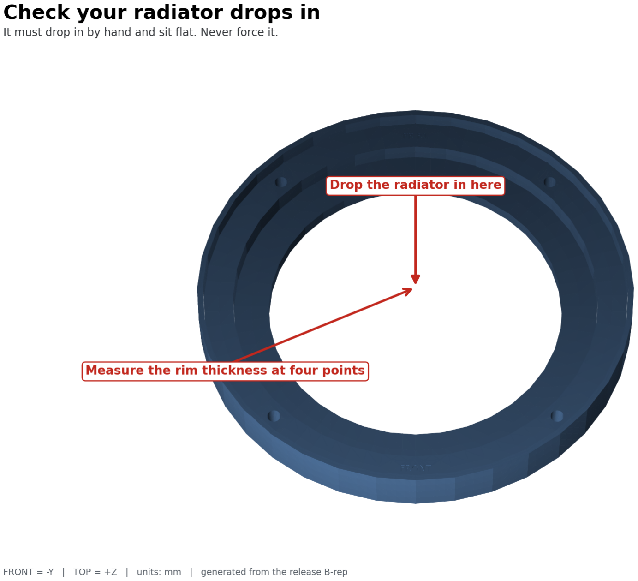
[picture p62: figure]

Passive-radiator coupon fit check

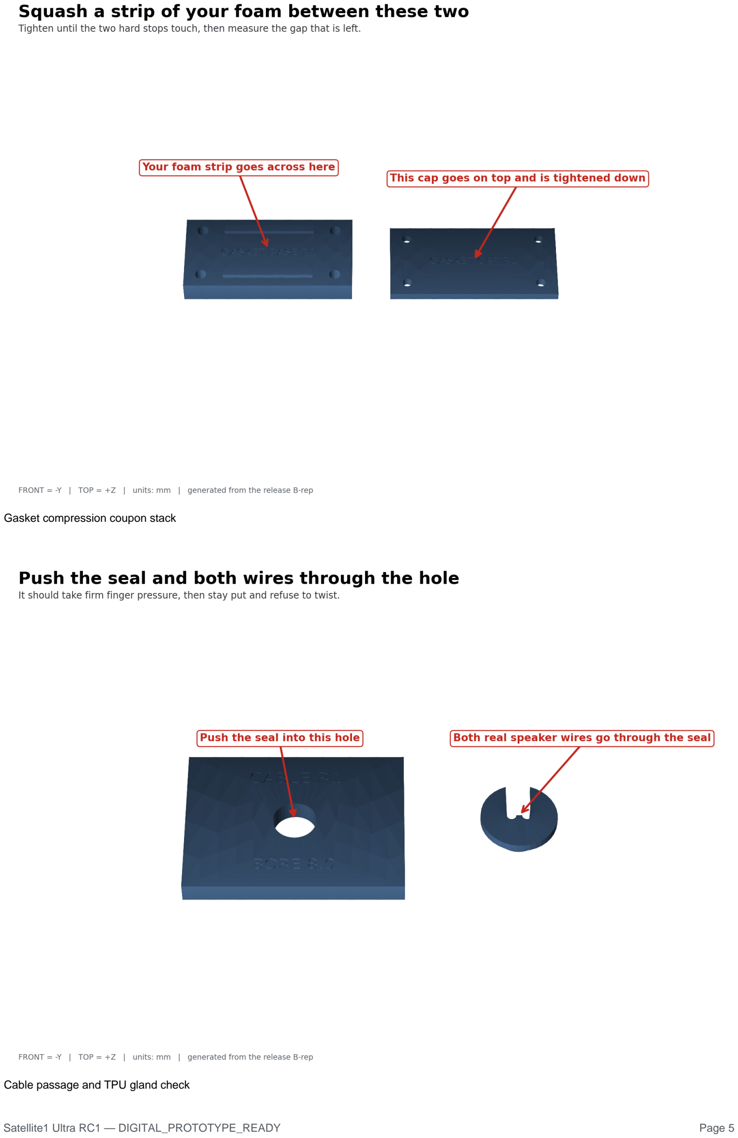
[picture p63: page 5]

Gasket compression coupon stack

Cable passage and TPU gland check

# Edit one file

Copy CALIBRATION_INPUT_TEMPLATE.yaml to config/physical_calibration.yaml, or run:

python scripts/calibrate.py

The file exposes only user-facing corrections. Safe limits reject implausible values before any full part is built.

# Regenerate

make calibrated-release

Success ends with all validation, documentation, mutation, and package checks passing. Output is in release/Satellite1-Ultra-RC1/.

Example successful finish:

documentation PASS; 9 guides, 7 PDFs
release/Satellite1-Ultra-RC1 (all required files present)

Reprint every coupon affected by a nonzero correction. You are cleared for the full enclosure only when all eight checks above pass on the corrected coupons.

# Common failures

- Warped official coupon: improve enclosure temperature, clean the bed, add the brim, and do not compensate a warped part.
- Every hole undersized: check flow and elephant-foot compensation before adding a large CAD offset.
- Insert cracks the boss: choose a larger coupon bore or reduce iron dwell; do not increase torque.
- Component will not sit flat: remove only print strings. Do not sand a sealing land; correct the cutout and reprint the coupon.
- Gland leaks or spins: verify conductor OD <=1.8 mm, dry TPU, then correct and reprint both the coupon and gland.

Source commit 508add3e53b5. No physical validation has been performed.

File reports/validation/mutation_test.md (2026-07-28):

# Mutation-test report

- Status: `PASS`
- Deliberate defects rejected: 18
- Failures/errors/skips: 0/0/0
- Evidence: `VERIFIED_DIGITALLY`

Each test injects a deliberate defect and passes only when the corresponding validation gate rejects it.

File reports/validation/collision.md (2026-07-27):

# Collision

- Overall status: `PASS`
- Evidence: `VERIFIED_DIGITALLY`
- Method: exact OCCT boolean intersection volume for every pair

The machine-readable source of this report is the adjacent JSON file. All unmeasured real-world performance remains `REQUIRES_PHYSICAL_VALIDATION`.

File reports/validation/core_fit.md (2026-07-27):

# Core Fit

- Overall status: `PASS`
- Evidence: `VERIFIED_DIGITALLY`
- Method: swept placement search for a Core-sized clearance box in the bay
- Physical gate (`REQUIRES_PHYSICAL_VALIDATION`): Confirm Core mounting against a physical development kit.

The machine-readable source of this report is the adjacent JSON file. All unmeasured real-world performance remains `REQUIRES_PHYSICAL_VALIDATION`.

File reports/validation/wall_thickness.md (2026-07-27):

# Wall Thickness

- Overall status: `PASS`
- Evidence: `VERIFIED_DIGITALLY`
- Method: parameter audit plus measured B-rep sections
- Physical gate (`REQUIRES_PHYSICAL_VALIDATION`): Section one sacrificial print and compare walls to slicer and caliper values.

The machine-readable source of this report is the adjacent JSON file. All unmeasured real-world performance remains `REQUIRES_PHYSICAL_VALIDATION`.

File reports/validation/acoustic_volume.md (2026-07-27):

# Acoustic Volume

- Overall status: `PASS`
- Evidence: `VERIFIED_DIGITALLY`

The machine-readable source of this report is the adjacent JSON file. All unmeasured real-world performance remains `REQUIRES_PHYSICAL_VALIDATION`.

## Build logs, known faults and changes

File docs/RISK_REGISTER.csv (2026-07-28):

id | severity | risk | consequence | mitigation | owner | state | evidence
R-01 | HIGH | Driver and radiator flange thicknesses are not dimensioned | The clamp hard stop can under-compress or over-compress a gasket. | Measure both purchased components, enter the values in config/physical_calibration.yaml, and pass both component coupons. | builder | OPEN | REQUIRES_PHYSICAL_VALIDATION
R-02 | HIGH | Core board placement is absent from the official assembled CAD | A source-only claim of exact Core placement would be unsupported. | The CAD reserves a Core-sized service volume. Confirm the official Core/HAT stack against the physical Batch 1 kit before closing the upper stack. | builder | OPEN | REQUIRES_PHYSICAL_VALIDATION
R-03 | HIGH | Low-frequency output is excursion limited | Full amplifier voltage below tuning can exceed driver or radiator travel. | Start with the documented fourth-order high-pass, verify polarity and tuning with an impedance sweep, then set DSP from measurements. | builder | OPEN | ENGINEERING_ESTIMATE
R-04 | MEDIUM | Printed walls and compressed seals have not been leak tested | A leak can remove the expected passive-radiator bass response. | Use the temporary leak-test adapter at 100-250 Pa, inspect every joint, and then confirm the final cable gland by impedance measurement. | builder | OPEN | REQUIRES_PHYSICAL_VALIDATION
R-05 | MEDIUM | Printer dimensional performance is unknown | Nominal CAD clearances may become interference or loose fits. | Complete all eight calibration checks and regenerate with make calibrated-release before any full-size print. | builder | OPEN | REQUIRES_PHYSICAL_VALIDATION
R-06 | MEDIUM | Wake-word, Wi-Fi, LED, and button performance are unmeasured | The final enclosure can affect radio and acoustic behavior even when openings clear. | Run the controlled bare-kit versus enclosed-kit commissioning tests. | builder | OPEN | REQUIRES_PHYSICAL_VALIDATION
R-07 | MEDIUM | Closed-shroud thermal behavior is unmeasured | The Core or amplifier may throttle or exceed a safe temperature margin. | Perform the documented 25 C and 35 C thermal soaks with instrumented hardware. | builder | OPEN | REQUIRES_PHYSICAL_VALIDATION
R-08 | LOW | Insert pullout strength depends on printer, material, and installation | An insert can rotate or pull free during service. | Select the coupon bore that installs square, torque-test it cold, and reserve the 250 N pull test for formal physical validation. | builder | OPEN | REQUIRES_PHYSICAL_VALIDATION
R-09 | LOW | Satellite1.1 / Batch 2 is not supported by this release | Its external Wi-Fi antenna and service interfaces are not accommodated. | Use only Batch 1 rev4.1 Core + rev4.1 HAT. Add a validated adapter before claiming Batch 2 compatibility. | maintainer | OPEN | DERIVED_FROM_OFFICIAL_CAD

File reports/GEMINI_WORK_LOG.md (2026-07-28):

# Gemini Work Log

- **2026-07-27**: Created `gemini/takeover` branch. Preserved uncommitted changes in reference assets. Initialized `GEMINI.md`, `GEMINI_TAKEOVER_AUDIT.md`, and this work log. Next step is regenerating all artifacts and evaluating `DIGITAL_PROTOTYPE_READY`.
- **2026-07-27**: Regenerated the full artifact set (`make release`). Validated that all 97 tests, validation gates, deep tests, and mutation tests passed successfully. Updated `PROJECT_STATUS.md` to `DIGITAL_PROTOTYPE_READY`. All files are committed. Awaiting physical validation from the user.

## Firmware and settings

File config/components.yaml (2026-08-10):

evidence_labels:
  manufacturer_data: DERIVED_FROM_MANUFACTURER_DRAWING
  scores: ENGINEERING_ESTIMATE
  prices_and_availability: ENGINEERING_ESTIMATE

selection:
  active_driver_primary: dayton_nd91_4
  active_driver_fallback: tectonic_tebm65c20f_4
  passive_radiator_primary: dayton_dsa115_pr
  passive_radiator_fallback: sb_acoustics_sb12pacr_00
  architecture: one_active_two_opposed_passive_radiators

active_drivers:
  dayton_nd91_4:
    manufacturer: Dayton Audio
    model: ND91-4
    nominal_impedance_ohm: 4.0
    minimum_impedance_ohm: 4.3
    re_ohm: 4.3
    le_mh: 0.83
    fs_hz: 74.0
    qms: 4.24
    qes: 0.45
    qts: 0.41
    vas_l: 1.4
    mms_g: 4.8
    cms_mm_per_n: 0.96
    rms_kg_per_s: 0.53
    bl_tm: 4.59
    sd_cm2: 30.4
    xmax_mm: 4.6
    rated_power_w: 30.0
    sensitivity_2v83_db: 85.6
    frequency_min_hz: 65.0
    frequency_max_hz: 17000.0
    # The frame is not a disc: a round sealing body with four mounting ears
    # standing proud of it.  Three diameters matter and they are different.
    outer_diameter_mm: 103.2          # across the ears; what the seat must clear
    flange_body_diameter_mm: 88.5     # across the flats; the sealing surface
    # Outline traced from the manufacturer's top-down product photograph, one
    # quadrant at 2.5 degree steps, normalised to the tab radius, forced
    # symmetric about 45 and low-pass filtered to the harmonics the frame's
    # four-fold symmetry allows, which removes about 0.27 mm of pixel jitter.  A circular body carrying four tabs: constant radius
    # through the middle of each edge, rising to the tabs that hold the
    # mounting holes.  Its own body/tab ratio is 0.8586 against 88.5/103.2 =
    # 0.8576 from the dimensioned drawing, agreeing to 0.12 percent, so the
    # shape comes from the photograph and the scale from the drawing.
    frame_profile:
      [1.0000, 0.9924, 0.9729, 0.9507, 0.9315, 0.9156, 0.9014, 0.8890,
       0.8791, 0.8716, 0.8655, 0.8608, 0.8583, 0.8578, 0.8579, 0.8577,
       0.8573, 0.8573, 0.8573, 0.8573, 0.8573, 0.8577, 0.8579, 0.8578,
       0.8583, 0.8608, 0.8655, 0.8716, 0.8791, 0.8890, 0.9014, 0.9156,
       0.9315, 0.9507, 0.9729, 0.9924, 1.0000]
    cutout_diameter_mm: 76.45         # published baffle cutout, 3.01 in
    bolt_circle_mm: 93.3
    mounting_hole_diameter_mm: 4.0
    mounting_holes: 4
    depth_mm: 62.9
    flange_thickness_mm: 1.0
    flange_thickness_evidence: MEASURED_ON_COMPONENT
    flange_thickness_note: Calipered on the project owner's driver, 2026-08-10, after seating it in coupon_active_driver. The stamped steel flange is 1.0 mm. The 3.0 mm previously carried here was an estimate and was three times the truth, which would have left the clamp ring 1.5 mm clear of the flange. The factory foam ring must be peeled off first; our own gasket replaces it, and leaving both stacks two seals.
    cutout_evidence: DERIVED_FROM_MANUFACTURER_DRAWING
    cutout_note: >-
      Was 88.5 mm, taken off the dimensioned drawing where 88.5 is a frame
      dimension, not the cutout.  That made the bore 3.6 mm WIDER than the
      85.09 mm sealing body, so the driver would have dropped through the
      baffle and the gasket would have touched nothing.  Parts Express and
      Dayton both publish Baffle Cutout Diameter 3.01 in = 76.45 mm, and
      Overall Outside Diameter 3.35 in = 85.09 mm for the round body;
      loudspeakerdatabase lists nominal 104 mm, matching the 103.2 mm
      across-ears figure on the drawing.  All three agree once each number is
      attached to the feature it actually describes.
    vd_cm3: 12.2
    displacement_l: 0.10
    price_usd: 36.99
    source: references/manufacturer/Dayton_ND91-4_spec_2026-02-26.pdf
    distortion_source: references/manufacturer/Dayton_ND91-4_Klippel.pdf
  scanspeak_10f_4424g00:
    manufacturer: Scan-Speak
    model: 10F/4424G00
    nominal_impedance_ohm: 4.0
    minimum_impedance_ohm: 3.4
    re_ohm: 3.22
    le_mh: 0.22
    fs_hz: 90.0
    qms: 2.0
    qes: 0.34
    qts: 0.29
    vas_l: 2.0
    mms_g: 3.1
    cms_mm_per_n: 0.72
    rms_kg_per_s: 0.80
    bl_tm: 4.10
    sd_cm2: 35.0
    xmax_mm: 3.0
    rated_power_w: 25.0
    sensitivity_2v83_db: 90.0
    frequency_min_hz: 80.0
    frequency_max_hz: 20000.0
    outer_diameter_mm: 100.0
    cutout_diameter_mm: 79.0
    bolt_circle_mm: 89.0
    mounting_hole_diameter_mm: 4.2
    mounting_holes: 4
    depth_mm: 48.0
    displacement_l: 0.08
    price_usd: 124.0
    source: https://www.scan-speak.dk/datasheet/pdf/10f-4424g00.pdf
  tectonic_tebm65c20f_4:
    manufacturer: Tectonic Audio Labs
    model: TEBM65C20F-4
    nominal_impedance_ohm: 4.0
    minimum_impedance_ohm: 3.4
    re_ohm: 3.4
    le_mh: 0.15
    fs_hz: 97.0
    qms: 3.0
    qes: 0.65
    qts: 0.53
    vas_l: 1.3
    mms_g: 3.8
    cms_mm_per_n: 0.71
    rms_kg_per_s: 0.77
    bl_tm: 3.0
    sd_cm2: 34.0
    xmax_mm: 3.0
    rated_power_w: 30.0
    sensitivity_2v83_db: 84.0
    frequency_min_hz: 60.0
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

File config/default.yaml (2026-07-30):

project:
  name: Satellite1 Ultra
  units: mm
  evidence_default: ENGINEERING_ESTIMATE

hardware:
  board_revision: public_batch_1
  official_interface: squircle_midplate_threaded

enclosure:
  # v2 is a square 160 mm cabinet inside a 184 mm superellipse body. The Z
  # layout is solved so the gross sealed prism reproduces v1's 3.966 L on the
  # narrower plan, so the footprint shrinks on both axes at no acoustic cost.
  outer_width: 160.0
  outer_depth: 160.0
  # Vestigial for the superellipse section, which is defined by its exponent
  # (geometry.SECTION_EXPONENT) rather than a corner radius. Retained only
  # because the coupon and validation probes still reference it.
  corner_radius: 20.0
  cable_passage_x: 34.0
  cable_passage_y: 64.0
  grille_width_margin: 28.0
  grille_depth_margin: 28.0
  acoustic_top_z: -33.0
  acoustic_bottom_z: -214.3
  base_bottom_z: -236.3
  wall_thickness: 4.0
  divider_thickness: 4.0
  acoustic_floor_thickness: 8.0
  bottom_plate_thickness: 4.0
  print_clearance: 0.30
  component_bore_clearance: 0.20
  brace_rib_width: 5.0
  brace_rib_depth: 8.0
  # Separated 36 mm in Z. Aligning them made the driver and radiator component
  # envelopes overlap by 338 mm^3 in the cabinet corner; 36 mm measures zero.
  driver_axis_z: -100.0
  passive_radiator_axis_z: -136.0

component_mounts:
  # Clamp-ring acoustic component mounts. Fasteners are deliberately outboard
  # of the component bolt circle so that no fastener feature can break into the
  # component through-bore; see reports/CLAUDE_TAKEOVER_AUDIT.md finding F-002.
  clamp_ring_thickness: 5.0
  clamp_lip: 1.0
  pad_backing: 3.0
  driver_clamp_ring_diameter: 118.0
  driver_clamp_bolt_circle: 112.0
  driver_pad_diameter: 126.0
  pr_clamp_ring_diameter: 134.0
  pr_clamp_bolt_circle: 124.0
  pr_pad_diameter: 138.0
  pr_ledge_depth: 5.0

sealing:
  gasket_thickness: 2.0
  target_compression_fraction: 0.25
  gasket_land_width: 4.0

fasteners:
  primary_size: M3
  primary_pitch: 0.5
  insert_outer_diameter: 4.6
  insert_bore_diameter: 4.2
  insert_length: 5.7
  insert_bore_extra: 1.5
  minimum_boss_wall: 2.4
  clearance_diameter: 3.4
  head_clearance_diameter: 6.5

acoustics:
  active_driver: dayton_nd91_4
  fallback_driver: tectonic_tebm65c20f_4
  passive_radiator: sb_acoustics_sb12pacr_00
  fallback_passive_radiator: dayton_dma105_pr
  passive_radiator_count: 2
  target_tuning_hz: 60.0
  leakage_q: 7.0
  # RC1 has no internal damping material. Add damping only after a measured
  # acoustic test establishes a safe location and a revised displacement value.
  damping_volume_fraction: 0.0
  amplifier_voltage_rms: 10.0
  amplifier_peak_current_a: 6.0

ballast:
  # Two 6 mm mild-steel plates, 100 x 92 mm. v1 used two 5 mm plates for 879 g,
  # but the square cabinet narrows the tray, so the stack is thicker to hold
  # the base mass roughly constant on a taller, narrower body.
  target_mass_g: 867
  maximum_mass_g: 1250
  cartridge_material: steel_plate_stack

printing:
  primary_material: ASA
  alternative_material: PETG
  # Usable build volume of the reference machine, per axis. The printability
  # gate reads these and tests both in-plane rotations of every part, so
  # changing them here really does change the gate. The old scalar
  # `maximum_build_dimension` was dead configuration; see
  # reports/review/2026-07-29-claude-v2-review.json PRINT-002.
  build_volume_x: 220.0
  build_volume_y: 200.0
  build_volume_z: 250.0

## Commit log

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2026-07-27 repair acoustic component mounting, sealing and official interface
    Independent verification of the Codex geometry found defects that the
    parameter-audit validation could not see. Measured on the B-rep:
    * F-001 a 0.30 mm annular gap ran from ambient, past the component gasket,
    into the sealed chamber all the way around the driver and both radiators
    (only 5.9 % of the seat annulus was material). The enclosure was not
    sealed.
    * F-002 the M3 insert bores broke into the driver through-bore and their
    Oe9.4 bosses protruded 131 mm3 into the driver cutout.
    * F-003 the insert *bore* was drawn at the insert's outside diameter
    (Oe4.6), so no heat-set insert would have had any interference.
    *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
    [components.yaml, default.yaml]
2026-07-27 correct the passive-radiator alignment and derive it from the model
    The 50 Hz tuning target was wrong for a driver with Fs 74 Hz, Vas 1.4 L
    in a 3.45 L box: it placed Fb far below the driver's in-box resonance, so
    the radiators contributed almost nothing and the modelled f3 was 105 Hz.
    Adds an alignment optimiser that sweeps Fb and selects the lowest -3 dB
    corner subject to passband ripple <= 3.5 dB and an added mass the M6 post
    can actually accept. It selects 59 Hz; the design target is set to 60 Hz
    and the summary now FAILs if the two diverge by more than 3 Hz.
    Modelled result at the exact 3.454 L CAD net volume: f3 56.9 Hz against
    132 Hz for the same driver sealed, minimum impedance 4.3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
    [response.csv]
2026-07-27 complete the manufacturing package, industrial design and mutation suite
    Implements the entire build pipeline that the inherited CLI only claimed to
    have: sat1-ultra build/validate/acoustics/export/renders/drawings/docs/manual,
    wired into make release. All four CI workflows invoked make release, which was
    a set of no-op stubs, so CI could not previously have detected anything.
    Industrial design: the wireframe grille cage is replaced by a slotted outer
    shell with solid top and bottom bands and a mid-height tie band, its slots
    placed normal to the rounded-rectangle perimeter so they hold constant width
    around the corners. The electronics shroud becomes the cosmetic shoulder,
    sweeping from jus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
    [MANIFEST.csv, active_driver_clamp_ring.3mf, active_driver_clamp_ring.step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]
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2026-07-29 docs: one build book, fixed diagrams, browser calibration wizard
    Documentation
    - Replace the two competing entry points (START_HERE and the beginner
    guide) plus the confusingly named START_HERE_CALIBRATION_GUIDE with one
    SATELLITE1_ULTRA_BUILD_BOOK covering the whole build in nine phases.
    - Add the gasket-cutting phase. No guide previously told the builder to cut
    G01-G03 from the DXF templates, so assembly assumed gaskets that did not
    exist.
    - Publish the hardware guide as a PDF; it was the only builder guide absent
    from the release package.
    - Fix the Markdown-to-PDF renderer: wrapped bullets rendered as a bullet
    plus an orphan paragraph, multi-line warnings split into separate b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
    [BOM.csv, MANIFEST.csv, active_driver_clamp_ring.3mf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]
2026-07-29 fix: seal the driver flange and attach the ballast lid bosses
    CR-001 (CRITICAL). The Dayton ND91-4 carries four unused Ø4.0 mounting
    holes on a Ø93.3 circle. The gasket ran from bore+3.0 to the seat, so its
    inner edge sat 1.2 mm outboard of those holes and they opened into the gap
    under the flange, venting the chamber through the clamp-ring bore. The
    gasket now spans the whole flange underside, from the cutout to the flange
    rim, covering all four holes and leaving no gap inboard. It also no longer
    overhangs the flange edge, so the full band is compressed.
    Residual, recorded in the findings: the driver leaves only 0.4 mm of flange
    between hole and cutout, so the inboard land is inherently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
    [MANIFEST.csv, active_driver_clamp_ring.3mf, active_driver_clamp_ring.step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]
2026-07-29 fix: give the ballast lid bosses room by insetting the steel plate
    The relocated bosses cleared the steel but hit the outer shell, which the
    collision gate caught. There is no position for a 9.4 mm boss between a
    110 x 122 plate and the shell, so the plate is now inset 10 mm per side
    rather than 5, and the boss positions derive from the plate edge plus the
    boss radius and clearance.
    Measured per boss: 32.36 mm2 bonded cross-section, zero intersection with
    both the steel plate and the outer shell.
    Steel drops from 1053 g to 879 g. The config target, the assembly pass
    criterion, and the stage-6 render no longer carry the old figure; the
    criterion now refers to BOM.csv and the render reads th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
    [01_CHECK_SATELLITE_TOP_FIT.3mf, 01_MAIN_SPEAKER_BODY.3mf, 01_SATELLITE_MID_PLATE.stl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]
2026-07-29 fix: align ballast default and README datum wording with the new plate
    The reduced steel plate left config/default.yaml at 879 g while the
    DesignParameters default still read 1054 g, which the configuration test
    correctly rejected. The README rewrite also dropped the exact master-datum
    phrasing the bootstrap test pins.
    Stability is unaffected: minimum tipping angle 48.57 deg against a 35 deg
    gate, total assembled mass 3351 g.
    Claude-Session: https://claude.ai/code/session_01BAJsenFfs853vxbc541mV2
    [01_CHECK_SATELLITE_TOP_FIT.3mf, 01_MAIN_SPEAKER_BODY.3mf, 01_SATELLITE_MID_PLATE.stl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]
2026-07-29 fix: close the remaining review findings
    CR-003. O06, the snap-in light ring, is a required print but was missing
    from UPPER_STACK, so it appeared in no assembly, render, or clearance
    check. Added; collision and official-clearance gates pass with it present.
    CR-004. BOM B02 asked for a 0.78 g tuning mass built from M6 washers,
    whose smallest increment is about 1.0 g, so the target was unreachable
    with the specified hardware. B02 is now a self-adhesive lead-free strip
    trimmed to the target and matched within 0.02 g, and the BOM says why
    threaded mass cannot work here.
    CR-005. Fastener clamped stacks were hand-entered, so the gate could not
    notice geometry that was not there. They are now me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
    [01_CHECK_SATELLITE_TOP_FIT.3mf, 01_MAIN_SPEAKER_BODY.3mf, 01_SATELLITE_MID_PLATE.stl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]
2026-07-29 test: derive the official reference-assembly count from UPPER_STACK
    Adding O06 made the hard-coded count of 7 fail. Asserting membership of
    every UPPER_STACK part plus the placed board is stronger than a magic
    number and cannot drift when a required official part is added.
    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
    [01_CHECK_SATELLITE_TOP_FIT.3mf, 01_MAIN_SPEAKER_BODY.3mf, 01_SATELLITE_MID_PLATE.stl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]
2026-07-29 docs: make the website the manual and hand builders their parts
    The old flow was download a zip, read a PDF, install Python, run make. That is
    far too much for someone who just wants to print a speaker.
    Website (new, generated by src/satellite1_ultra/site.py)
    - Four steps, one screen each, big pictures, plain language: print the test
    pieces, measure them, get your parts, build it.
    - The measuring step now shows a picture per measurement, says which piece to
    pick up and exactly where to put the calipers, and has the input box right
    under the picture with instant plain-English feedback.
    - Generated from the same print orders, assembly steps and gasket data as the
    PDFs and the package,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
    [01_CHECK_SATELLITE_TOP_FIT.3mf, 01_MAIN_SPEAKER_BODY.3mf, 01_SATELLITE_MID_PLATE.stl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]
2026-07-29 fix: point calibration arrows at the features they describe
    The red arrow was drawn at a fixed screen position with a fixed caption, so it
    never touched the thing being measured. On the interface coupon it lay across
    the engraved text; on the screw and seat coupons an arrow meant nothing at all.
    Annotations are now placed from real model coordinates:
    - a dimension line spanning the engraved recess, edge to edge, for the 110.60
    measurement, and a pointer at a clean 3.00 mm edge
    - separate pointers at the four insert bores and the three clearance holes
    - a drop-in arrow onto the actual seat for the speaker and radiator coupons
    - the foam location and the cap's tightening direction on the ga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
    [01_CHECK_SATELLITE_TOP_FIT.3mf, 01_MAIN_SPEAKER_BODY.3mf, 01_SATELLITE_MID_PLATE.stl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]
2026-07-29 design: prototype the v2 seamless flat-top silhouette
    Establishes the v2 form before any production geometry changes.
    Measured three separate causes for v1 not reading as one part:
    - The official Satellite1 squircle is a true superellipse with n = 4.13
    (0.38 mm max fit error). Every v1 part uses rounded_prism -- straight
    sides plus circular corners -- which best-fits at 1.00 mm, ~3x worse.
    The body and the top are different curve families, so no amount of
    closing the gap would have unified them.
    - electronics_shroud tapers to 120 mm against a 110 mm official part,
    leaving a 5 mm ledge plus two deliberate concentric reveals.
    - The official stack is only 110 mm square above z = -7;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
2026-07-29 feat: make v2 the design across the board
    Ports the verified v2 form from design/v2 into src/ and retires v1.
    Tagged v1-final on main first, so the previous design stays recoverable.
    Geometry
    - superellipse_wire/section_prism/section_ring/section_area replace the
    rounded-rectangle primitives for every part whose section is visible or
    sealing. SECTION_EXPONENT = 4.13, measured from the official lock ring.
    - Square 160 mm cabinet in a 184 mm body; footprint shrinks on both axes.
    Z layout solved so the gross sealed prism holds at 3.968 L against v1's
    3.966 L, so the narrower plan costs nothing acoustically.
    - Driver and radiators share one axis height (-117) so the three grille
    windo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
    [01_CHECK_SATELLITE_TOP_FIT.3mf, 01_MAIN_SPEAKER_BODY.3mf, 01_SATELLITE_MID_PLATE.stl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]
2026-07-29 fix: correct the gates and ballast that the v2 section invalidated
    Found while porting, each of which would have shipped a wrong number:
    - The clearance gate hardcoded the skin gap as +13.0 mm, which was v1's
    32 mm grille margin minus a 3 mm wall. v2 uses a 24 mm margin, so the
    gate overstated radiator and driver clearance by 4 mm. Now derived from
    p.shell_gap.
    - "driver clamp ring within the flat cabinet face" is a rounded-rectangle
    notion; a superellipse has no flat. Replaced with _section_half_at,
    which measures the section actually left beside the ring's widest chord.
    - The square cabinet narrows the ballast tray from 120x132 to 120x112,
    which silently dropped the steel from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
    [default.yaml]
2026-07-29 fix: keep the superellipse to the skin, and separate driver from radiators
    Four gates failed on the first full run. Two real errors behind them.
    1. I made the hidden cabinet a superellipse as well as the skin. Only the
    skin is visible, and flat circular hardware needs a flat face: on a
    curved wall the component seat sidewall is not solid over the seat depth,
    the divider gasket land stops being a closed rim, the side wall thins to
    0.52 mm beside the radiator mount against a 3.2 mm minimum, and the
    140 mm radiator clamp ring hangs off the corners and punches through the
    skin. Cabinet, divider, base skirt, bottom plate and divider gasket are
    back on flat-faced rounded pris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
    [default.yaml]
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2026-07-29 fix: keep the body at 188 mm, and record the measured bed
    The owner measured the reference machine's Y axis at 200 mm, and I used that
    to relax the body from 188 to 190 mm for extra margin. That was scope I was
    not asked for, and the margin is not needed. Reverted to 188 mm.
    For the record, since the question is reasonable: 188 vs 190 makes no
    acoustic difference at all -- the sealed volume is set by the cabinet's
    152 x 152 mm inner section, and the skin is a cosmetic cage outboard of the
    pressure boundary, so the only thing that changes is an 11 mm air gap rather
    than 12 mm. Tipping angle differs by about 0.4 deg against a 7 deg margin.
    Both sizes clear a 3 mm brim on the measured bed. The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
    [default.yaml]
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2026-07-30 fix: bring tests and packaging in line with v2
    Eight test failures from the full check, none of them a design problem.
    Two were my own tests, written wrong:
    - test_section_matches_the_official_squircle asserted support extents I had
    computed with a different exponent during the original fit exploration.
    Correct values for n = 4.13 are 55.000 / 62.445 / 65.764. Rewritten to
    compare against the measured official extents within the documented
    0.38 mm fit error, which is the assertion that actually matters.
    - test_section_prism_area bounded the area ratio at 0.92-0.94; it is 0.931.
    Two were v1 assumptions that v2 deliberately inverts:
    - test_divider_seats_on_the_official_mid_plate requ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
    [BOM.csv, MANIFEST.csv, active_driver_clamp_ring.3mf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]
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2026-07-30 fix: last three test failures, all bookkeeping
    - README rewrite changed "center" to "centre" and "-Y" to a Unicode minus,
    breaking the datum assertions that guard the coordinate system. Restored.
    - The release package still held pre-regeneration 3MF files, so a download
    would have given v1 parts from a v2 release. Repackaged.
    - section_prism area asserted against the analytic superellipse within
    1 mm2, but the section is a 160-point spline and encloses 0.567% more.
    Bounds set to the measured values.
    - The divider standoff to the official mid-plate is 1.0 mm, the spigot
    bottom to the divider slab top; I had asserted 1.5.
    - INTENDED_CONTACTS listed crown-to-divider and base-to-bottom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
    [01_CHECK_SATELLITE_TOP_FIT.3mf, 01_MAIN_SPEAKER_BODY.3mf, 02_CHECK_SCREWS_AND_INSERTS.3mf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]
2026-07-30 fix: specify a passive radiator that is actually available in the US
    The SB Acoustics SB12PACR-00 has no US distributor. Madisound, the usual
    US SB dealer, does not carry the round version at all; the only in-stock
    source found was Solen in Canada, and shipping plus tariffs make that
    uneconomic. Its US-stocked sibling SB12PFCR-00 is mechanically identical
    but was out of stock. That is a sourcing failure in the original component
    selection, not an engineering one, and it blocks the build.
    Now specified: Dayton Audio DSA115-PR, stocked by Parts Express (295-544),
    Amazon, Newegg and Reverb.
    Dayton's standard 4" radiators do not fit. DMA105-PR is 55.1 mm deep and
    ND90-PR is 60.7 mm, which leav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
    [response.csv]
2026-07-30 fix: give the BOM real US purchase links, and correct the F01 fastener
    Purchase links. The BOM's source column pointed at datasheets, not places
    to buy. Every purchasable line now carries a US link: exact product pages
    where verified (Parts Express 290-224 for the driver, 295-544 for the
    radiator), store search URLs elsewhere so they keep working as listings
    churn. Printed parts say "printed by you" rather than a dead link.
    F01 was still listed as a plain M3 x 6 ISO 4762 socket cap screw. It is the
    fastener that carries the official stack onto the isolation bushings, and it
    must be an M3 x d4 shoulder screw with a 16 mm shoulder -- with an ordinary
    screw the elastomer carries under 3% of th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
    [01_CHECK_SATELLITE_TOP_FIT.3mf, 01_MAIN_SPEAKER_BODY.3mf, 02_CHECK_SCREWS_AND_INSERTS.3mf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]
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2026-07-30 fix: 3MF files opened empty in every slicer
    Reported by the owner, who had to import the STLs because a 3MF came up
    empty. It was not a slicer problem: every 3MF in the release was empty to
    any real slicer.
    write_3mf built the document with the 3MF core namespace bound to a prefix,
    so elements serialised as <ns0:model>, <ns0:object>, <ns0:triangle>. That is
    valid XML and valid 3MF, but PrusaSlicer, Cura, Orca and Bambu Studio match
    unprefixed element names, so they found zero objects and rendered an empty
    plate. Registering the namespace as the default fixes it.
    Measured through a namespace-naive parse of coupon_heat_set_insert:
    shipped 0 objects, 0 build items, 0 vertices, 0 triangle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
    [01_CHECK_SATELLITE_TOP_FIT.3mf, 01_MAIN_SPEAKER_BODY.3mf, 01_SATELLITE_MID_PLATE.stl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]
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2026-07-31 chore: regenerate exports, package and site for the download fixes
    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
    [01_CHECK_SATELLITE_TOP_FIT.3mf, 01_MAIN_SPEAKER_BODY.3mf, 02_CHECK_SCREWS_AND_INSERTS.3mf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]
2026-07-31 fix: offer an STL for every printable part, including the test pieces
    The test-print page -- the first page a builder downloads from -- had no STL
    option at all. package_release excluded the calibration coupons and the cable
    gland from ADVANCED/STL, so 3MF was the only choice for all eight test pieces.
    The exports have always contained those STLs; the exclusion had no reason
    behind it. Only the three gasket solids stay out, and those are cut from foam
    rather than printed.
    Also label each table with the format its rows actually are. The official-top
    table is STL and its header claimed 3MF, and those rows now say "already STL"
    rather than offering a second copy of the same file.
    Packaged STL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
    [cable_gland.3mf, cable_gland.stl, coupon_active_driver.3mf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]
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2026-08-05 fix: driver bore was wider than the flange it had to seal against
    The ND91-4 cutout was recorded as 88.5 mm, making the bore 88.70 mm. The
    driver's continuous sealing flange is 85.09 mm across. The hole was 3.61 mm
    wider than the part meant to seal it: the driver would have dropped through
    the baffle, carried on its four ears, with the gasket touching nothing. The
    seat is cut into main_cabinet, so it would have surfaced after a ~45 hour
    print with no smaller part to reprint.
    88.5 is a frame dimension on the Dayton drawing, not the cutout. Parts Express
    and Dayton both publish Baffle Cutout Diameter 3.01 in = 76.45 mm and Overall
    Outside Diameter 3.35 in = 85.09 mm; loudspeakerdatabase corro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
    [response.csv]
2026-08-05 chore: regenerate all artifacts for the corrected driver interface
    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
    [01_CHECK_SATELLITE_TOP_FIT.3mf, 01_MAIN_SPEAKER_BODY.3mf, 02_CHECK_SCREWS_AND_INSERTS.3mf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]
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2026-08-05 chore: regenerate exports for the fail-fast bore check
    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
    [01_CHECK_SATELLITE_TOP_FIT.3mf, 01_MAIN_SPEAKER_BODY.3mf, 02_CHECK_SCREWS_AND_INSERTS.3mf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]
2026-08-05 fix: cut the driver seat as the rounded square the frame actually is
    The ND91-4 frame is not a disc. It measures 88.5 mm across the flats and
    103.2 mm across the corners that carry the mounting holes -- a ratio of 1.166,
    where a circle is 1.000 and a true square 1.414. That solves to a superellipse
    of exponent 3.593, near the same family as the Satellite1's own squircle.
    The seat was a Ø103.8 circle. Wide enough to clear the corners, it left about
    7.6 mm of slop at the flats, so the driver floated instead of seating. That
    matters most on coupon_active_driver, whose whole purpose is to let a builder
    drop the real driver in, feel whether it lands flush, and measure the flange
    thickness again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
    [response.csv]
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2026-08-06 fix: the driver frame is a rounded square, not a superellipse
    The seat was fitted as a superellipse through the two dimensioned points on
    the Dayton drawing, 88.5 across the flats and 103.2 across the corners. It
    hits both exactly and is wrong in between. A superellipse has no straight
    sides; the ND91-4 frame does. Measured against the real profile the fitted
    curve runs narrow by 0.54 mm at 22.5 degrees and 0.66 mm at 30, against 0.30
    mm of seat clearance, so the driver would have bound on all four corners.
    The frame is a square with large corner radii: 88.5 across the flats, 26.505
    radius, 35.5 mm of straight run per side, reaching 103.2 across the corners
    that carry the mounting holes. Cu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
    [response.csv]
2026-08-07 fix: trace the driver seat from the photograph instead of fitting a curve
    The seat is now the outline traced off the manufacturer top-down photograph,
    scaled so the tabs reach the 103.2 mm Parts Express figure. Shape from the
    photo, size from the vendor, and the two cross-check: the traced outline own
    body/tab ratio is 0.8567 against 88.5/103.2 = 0.8576 from the dimensioned
    drawing, agreeing to 0.1 percent from independent sources.
    This replaces three wrong shapes, each derived from numbers rather than read
    off the picture that was available the whole time:
    circle ignored the shape entirely, 7.6 mm of slop at the body
    superellipse fitted through 88.5 and 103.2; exact at 0 and 4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
    [MANIFEST.csv, active_driver_clamp_ring.3mf, active_driver_clamp_ring.step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]
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2026-08-08 chore: regenerate artifacts for the shorter seat-fit coupon
    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
    [01_CHECK_SATELLITE_TOP_FIT.3mf, 01_MAIN_SPEAKER_BODY.3mf, 02_CHECK_SCREWS_AND_INSERTS.3mf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]
2026-08-08 feat: calibrate in two rounds, so the fit coupons are measured at your scale
    Every test piece except the first measures a feature the printer's scale error
    has already moved: hole diameters, seat widths, the gasket gap, the cable bore.
    Printing all eight at nominal and reading them folds the global shrink into
    every figure, and neither error can be recovered from the sum.
    This is not hypothetical. The project owner printed the speaker-fit coupon from
    the shipped files on a printer running 0.9 percent small, found the driver would
    not seat, and reasonably concluded the seat was the wrong shape. It was the
    right shape, 0.34 mm too small at the tabs and 0.21 at the body. Two sessions
    went into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
    [01_CHECK_SATELLITE_TOP_FIT.3mf, 01_CHECK_SATELLITE_TOP_FIT.stl, 01_MAIN_SPEAKER_BODY.3mf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]
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2026-08-08 fix: the round-one scale tab was dead on arrival
    Two faults, both reported by the project owner against the published site.
    The panel announced a perfect printer by overwriting its container's
    innerHTML. That deleted stage1_code, stage1_pct and both buttons out of the
    document, so every later keystroke hit the `if (!node) return` guard at the top
    of refreshStageOne and did nothing. Once the panel said "dead on" it could
    never say anything else. The two boxes shipped pre-filled at 110.60 and 3.00,
    which is exactly the negligible case, so it fired on page load: the tab was
    inert before anyone touched it. Typing a real measured 109.60 produced no code,
    no percentage, and no way forward.
    It no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
    [MANIFEST.csv, active_driver_clamp_ring.3mf, active_driver_clamp_ring.step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]
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2026-08-09 chore: regenerate artifacts, restoring exports/release consistency
    The previous regeneration was interrupted part-way to push a website fix,
    leaving exports/ newer than the copies in release/. test_release_contents
    caught the mismatch by checksum.
    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
    [01_MAIN_SPEAKER_BODY.3mf, 01_MEASURE_YOUR_PRINTER.3mf, 02_CHECK_SCREWS_AND_INSERTS.3mf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]
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2026-08-10 fix: take the component flange thicknesses from the components, not estimates
    Both were carried as ENGINEERING_ESTIMATE with a note saying to verify them on
    the coupons before printing the cabinet. The project owner did that.
    driver flange 3.00 estimated -> 1.00 measured seat 5.50 -> 3.50 mm
    radiator flange 4.00 estimated -> 3.75 measured seat 11.50 -> 11.25 mm
    The driver was out by a factor of three. It is stamped steel, not the 3 mm the
    estimate assumed, and the consequence is not subtle: seat depth is
    gasket + flange + clamp lip, so a 5.50 mm seat holds a 1.00 mm flange with its
    top 3.00 mm below the outer face while the clamp ring's lip reaches 1.00 mm.
    The ring would hav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
    [physical_calibration.yaml]
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
